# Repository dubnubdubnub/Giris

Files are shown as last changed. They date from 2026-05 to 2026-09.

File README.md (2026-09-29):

# Giris

An open source 32 key/half (64 total) **analog TMR split ortholinear keyboard** & 6 key macropad/dev board (`hw/TMR2615F_osu_pad`). 
Layout is similar to Keeb.io Iris with an extra column. Uses TMR2615F, 4:8 TMUX1574RSVR mux, & AT32F405. Link is UART over type-c cable.

There are 3 unique modes of operation: 
- standalone
- half A --> half B --> computer
- computer A <-- half A <--> half B --> computer B
    - Giris doubles as a KVM, you can control which computer you're typing on with a programmable macro
    - Relevant power circuitry to prevent backfeeding (GROUNDS ARE STILL BONDED!!!)

Done by Human:
- `hw/` — KiCad schematics and layout. `TMR2615F_osu_pad` is the 6-key development board the
  firmware is brought up on; `giris` is the full-size split.
- `mech/` — plates and frames.

Done by LLM + Human:
- `fw/` — firmware, written from scratch in C on the Artery BSP with TinyUSB. 8 kHz USB HS polling,
  8 kHz inter-half link. Host tools and a WebHID configurator live in `fw/tools/`.

## Schematics and photos

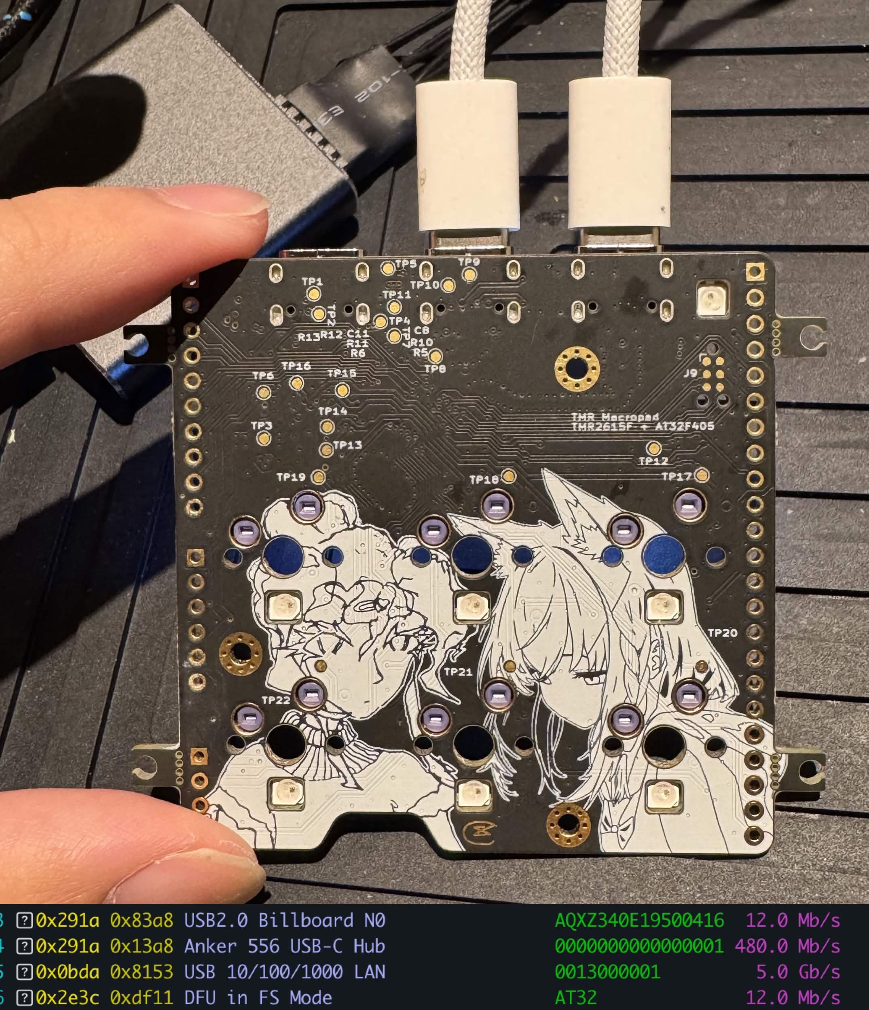
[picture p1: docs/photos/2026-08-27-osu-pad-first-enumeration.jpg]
First-revision osu!pad dev board enumerating over USB


PDFs:

- **osu pad dev board** (built and running, pictured above):
  [schematic](hw/TMR2615F_osu_pad/output/TMR2615F_osu_pad.pdf) ·
  [PCB layers](hw/TMR2615F_osu_pad/output/TMR2615F_osu_pad-layers.pdf)
- **Giris split** (in layout): [schematic](hw/giris/output/giris.pdf)
- **More photos and video** of built boards: [`docs/photos/`](docs/photos/)

The schematic PDFs draw the per-key sheet once and list each key's designators at the end;
regenerate them with `hw/tools/sch_pdf.py`.

## Setup

This repo uses git submodules for its shared footprint/3D-model library (`hw/library`) and `hw/marbastlib`. **The 3D bodies will not appear in KiCad's 3D viewer unless the submodules are checked out**; `.step` files live in `hw/library/packages3d/`.

Clone with submodules:

```bash
git clone --recurse-submodules https://github.com/dubnubdubnub/Giris.git
```

If you already cloned without `--recurse-submodules`, initialize them after the fact:

```bash
git submodule update --init --recursive
```

> Note: `hw/marbastlib` may print an error while recursing into a nested `.history` submodule. That is harmless — it is upstream and holds no 3D models the boards need.

## 3D models

Footprint 3D bodies resolve from three locations:

- `${KICAD10_3DMODEL_DIR}/…` — the standard models shipped with KiCad.
- `${KIPRJMOD}/../library/packages3d/…` — this repo's `hw/library` submodule (must be checked out; see Setup).

When adding new 3D models to a board, reference them with one of the path variables above rather than a bare relative path (e.g. `../../packages3d/…`), so they resolve regardless of where the repo is cloned.

## Licence

Giris uses two licences:

| What | Licence | File |
|---|---|---|
| Firmware, host tools, web configurator, docs | **Apache-2.0** | [`LICENSE`](LICENSE) |
| Hardware — schematics, PCB, magnet models (`hw/`) | **CERN-OHL-P v2** | [`hw/LICENSE`](hw/LICENSE) |

Both are permissive: use it, change it, build it, sell it, no obligation to
publish your changes. Apache-2.0 additionally carries an explicit patent grant.
CERN-OHL-P is the hardware equivalent — software licences are written about
copying source, not about manufacturing a board.

New source files should carry an SPDX header:

```c
/* SPDX-License-Identifier: Apache-2.0
 * Copyright 2026 Isaac Chiu
 */
```

### Third-party code

[`THIRD_PARTY.md`](THIRD_PARTY.md) is the full inventory; [`NOTICE`](NOTICE)
carries the attributions that must accompany a distributed **binary**.

The short version: TinyUSB (MIT) and the ArteryTek BSP are fetched at build time
by `fw/tools/fetch-deps.sh` and are not in this repository, though both are linked
into firmware binaries. Three Artery-derived files *are* committed — the startup
file, the linker script and `at32f402_405_conf.h` — and keep Artery's notice
rather than Giris'. Note that Artery ships two licence statements that disagree;
`THIRD_PARTY.md` explains which one to rely on.

### Why the firmware is not GPL

Giris is written from scratch. libhmk, minipad, DeskHop and the VIA app are
GPL-3.0; QMK, vial-qmk and Keychron's fork are GPL-2.0. All were read as
references and **no source file was ever pasted out of any of them**. That is a
deliberate, ongoing constraint, not an accident — copying so much as a descriptor
struct would make this firmware copyleft.

This matters most for the USB XUSB (Xbox controller) interface, where both
reference implementations — libhmk and Keychron's QMK fork — are copyleft. Write
it from Microsoft's own specification instead:

> **[MS-XUSBI]** — *Xbox Universal Serial Bus Protocol (XUSB) Interface Extension*
> <https://learn.microsoft.com/en-us/openspecs/windows_protocols/ms-xusbi/c79474e7-3968-43d1-8d2f-175d47bef43e>

It gives the class triple and the 20-byte report normatively, and its Open
Specifications notice explicitly permits copying the documentation in order to
build implementations of it. [`THIRD_PARTY.md`](THIRD_PARTY.md) records the
limits of that permission — notably that no patent grant is established.

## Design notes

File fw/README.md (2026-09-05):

# Giris firmware

Bare-metal C for the **AT32F405RBT7-7** on `hw/TMR2615F_osu_pad` — the 6-key analog dev pad that
prototypes the 64-key split (32 keys per half).

Architecture, decisions and the bring-up plan live in
[`../hw/TMR2615F_osu_pad/firmware_architecture.md`](../hw/TMR2615F_osu_pad/firmware_architecture.md).
This README is just how to build and flash.

## Setup

```bash
brew install --cask gcc-arm-embedded   # or the Arm GNU Toolchain installer
brew install cmake ninja dfu-util
./tools/fetch-deps.sh                  # Artery BSP + TinyUSB into vendor/
```

`vendor/` is gitignored. Pinning ~500 MB of upstream firmware libraries into this repo (or into
`.gitmodules`, alongside the KiCad libraries) is a decision to make deliberately — `tools/fetch-deps.sh`
has the one-liners if you want them as submodules.

## Build

```bash
cmake -S . -B build -G Ninja -DCMAKE_TOOLCHAIN_FILE=cmake/arm-none-eabi.cmake -DCMAKE_BUILD_TYPE=Debug
cmake --build build
```

Produces `build/giris.{elf,bin,hex}` and a `giris.map`. The link step prints the memory budget, which is
worth watching as the firmware grows:

```
FLASH:  3868 B / 128 KB   2.95%
RAM:    1600 B /  70 KB   2.23%
```

`compile_commands.json` is exported for clangd.

## Flash

```bash
cmake --build build --target flash      # or: ./tools/flash.sh build/giris.bin
```

**Entering DFU:** hold **SW1 (BOOT0)** and tap **SW2 (NRST)**, then release SW1. The board appears as
`2e3c:df11`, DfuSe 1.1a.

Two things about this that are easy to get wrong:

- The ROM bootloader is on **OTG_FS (PA11/PA12) only — connector J2, never J3.** J3 is the USB HS host
  port and cannot reach the factory bootloader at all.
- **J2 has no VBUS net**, so it cannot power the board. Power it separately while flashing.

`dfu-util` reports `Error during download get_status` on the leave request. That is a DfuSe quirk — the
device resets before answering. `File downloaded successfully` on the line above is the one that matters.

The device advertises its own memory layout, which is how the flash geometry here was confirmed:

```
alt 0   @Internal Flash   /0x08000000/128*001Kg      128 x 1 KB sectors
alt 1   @Option byte      /0x1FFFF800/01*512g
```

Note this is the **xB** part: 1 KB sectors, 6.6 ms typical / 8 ms max erase. The 2 KB / 13.2–16 ms
figures in Artery's tables are the 256 KB xC part. (Artery's own `AT32F405xB_FLASH.ld` declares 256 KB
of flash — a BSP bug. `ld/at32f405rbt7.ld` is that file with the length corrected to 128 KB.)

## What the firmware does today

- clocks to **216 MHz** from the 12 MHz crystal (PLL MS=1, NS=72, FP /4; PLLU /18 for OTG_FS),
- runs the **ADC/mux scan engine at 8 kHz** — ADC1 converts PA3/PA2/PA1/PA0 on every TMR2 TRGO,
  DMA1_CH1 lands them in a circular 8-slot ring, and the half/full-transfer interrupts flip the
  TMUX1574 SEL line so bank A and bank B interleave,
- enumerates on **J3 as a USB high-speed raw-HID device** and streams the readings to the browser
  viewer,
- drives the SK6812 chain as a status indicator.

There are **two HID interfaces**: the vendor raw-HID one the viewer speaks (usage page `0xFF60`), and
a boot-protocol keyboard. They are separate interfaces on purpose — macOS evaluates Input Monitoring
per `IOHIDDevice`, which means per USB interface, so putting keyboard usages on the vendor interface
would make the viewer demand permission to open it. Keyboard output is gated off at boot; see
`CMD_KEYS`.

### The viewer

```bash
./tools/viewer/serve.sh          # http://localhost:8000, Chrome or Edge
```

WebHID needs a secure context and `http://localhost` qualifies, so there is no TLS and no build step.
Live traces for all six keys, per-key readouts in counts and Gauss, CSV recording, a raw-slot debug
table, and a burst capture that dumps a few thousand samples for an in-page FFT.

That FFT is the point of the whole exercise: **a flat spectrum means white noise and narrowing the
analog filter is worth it; a −1/2 amplitude slope means 1/f and narrowing buys ~5 % for a 103 µs
transport delay.** That measurement decides the filter respin.

### Two boards at once

Every board now takes its USB serial from the 96-bit factory UID at `0x1FFFF7E8`, so two halves
running one image are separable everywhere — `capture.py`, `link.py`, `dfu.py` and the viewer all take
`--serial` with any unique substring. The last four hex characters are a good handle.

```bash
tools/.venv/bin/python tools/link.py --list
E75C30400080160505875C13  Giris osu pad (telemetry)
E85C30400080160505875113  Giris osu pad (telemetry)
```

Those two are adjacent dice off one wafer and differ in only two of twelve bytes, which is why
`uid_tag()` — the 16-bit condensation used to break ties in link arbitration — is FNV-1a over the whole
UID rather than a truncation. They come out 0x436A and 0xF885.

In DFU every AT32 reports the serial `AT32`, so there the bus path is the only discriminator:

```bash
tools/.venv/bin/python tools/dfu.py --serial 5C13     # prints the DFU path it lands on
./tools/flash.sh build/giris.bin 2-1.3
```

### The J1 link

```bash
tools/.venv/bin/python tools/link.py --probe --serial 5C13   # one board, J1 empty
tools/.venv/bin/python tools/link.py --continuity            # two boards: is there a wire?
tools/.venv/bin/python tools/link.py --peer                  # two boards: the real sweep
tools/.venv/bin/python tools/link.py --soak --baud 13500000
```

**Measured, two boards, straight-through USB-C on J1:**

| Config | Result |
|---|---|
| Half duplex, open drain, one wire on D− — *the discovery bus* | clean at 115200 and **500 kbaud**; framing errors at 1 Mbaud |
| Full duplex, push-pull, TRPSWAP on one half — *the run phase* | clean at every rung to **13.5 Mbaud**, the USART's ceiling, both directions |
| Soak at 9 and 12 Mbaud, **3 m cable** | 409,600 bytes each, **0 corrupt, 0 missing, 0 noise flags** |
| Same at 13.5 Mbaud, 3 m | NERR on **61/100 runs**; clean at 1.5 m |
| Sustained rate, DMA both ends | **98.8–99.6 % of line rate** — the wire is saturated, not the CPU |

At 13.5 Mbaud a 72-byte frame (32 keys × u16 + header + mech bitmap + CRC-16) takes **54 µs, 43 % of a
125 µs microframe**, and the link is full duplex so the return path is free. 13.5 Mbaud is also the
hard ceiling: RM 12.6.1 requires `DIV ≥ 16` with fixed 16× oversampling, and APB2 is already at the
part's 216 MHz maximum. **Run at 12 Mbaud**: it is clean over a 3 m cable with the receiver's noise
flag never firing, where 13.5 raises NERR on most runs. See the architecture doc for the full table
and for why the link should negotiate its own rate.

500 kbaud is exactly where the architecture doc predicted the open-drain bus
would die: two 10 k pull-ups into ~70 pF. Discovery at 115200 has 4× margin.

Three traps are baked into the tooling because each one costs an afternoon:

- **`--probe` before anything else.** The datasheet gives PC6 = USART6_TX and
  PC7 = USART6_RX but not the MUX index. The probe sweeps all sixteen while the
  USART shifts `0x00` and watches the pad; only **MUX8** modulates.
- **`--continuity` before believing any link failure.** It is a DC test with no
  USART involved: one board holds a pad low, the other reads its own. A
  charge-only USB-C cable carries VBUS and GND but neither D+ nor D−, and from
  the firmware side that is indistinguishable from a dead peripheral. The first
  cable tried here was one of those, and it also fed 5 V into J1 — which is what
  made one board's `/LM_ST` read high and sent us hunting a phantom.
- **Receive by DMA, never by polling.** A CPU loop gets preempted by the 16 kHz
  ADC/mux ISR for longer than a byte time above ~8 Mbaud. The USART overruns,
  the lost byte shifts the expected value for every byte after it, and reading
  `DT` silently clears `ROERR` — so you see *almost every byte arriving and
  almost every byte wrong, with no error flag*, which looks precisely like a bad
  cable. It is not. `DMA1_CHANNEL1` is the ADC ring, so the link takes channel 2.

**This silicon does not echo its own half-duplex transmission.** RM 12.2 says TX
and SW_RX are interconnected, but with `SLBEN=1 TEN=1 REN=1` a lone board never
raises RDBF, at any baud, open-drain or push-pull, with no error flag — and
turning the listener's transmitter off does not change it. Testing the receive
path needs a peer on J1 or a jumper from **TP1** (D+) to **TP2** (D−).

### Is it really 8 kHz?

```bash
tools/.venv/bin/python tools/ratetest.py --seconds 10
```

Measured, not asserted. The streaming path emits exactly **one frame per report** — `adc_read_frame()`
always returns the newest complete frame, so the pack loop breaks on its second iteration — which means
the device wants to send at the full scan rate and achieves `min(poll rate, scan rate)`. Counting
reports therefore counts polls. `bInterval = 1` is 1 ms at full speed and 125 µs at high speed, so
~8000/s proves both at once.

Two independent numbers come out and should agree: the host-observed count, which Python can bottleneck,
and a device-side figure computed from the firmware's own `tx_dropped` counter, which cannot.

| Host | scan | host-observed | device-side | dropped | seq gaps |
|---|---|---|---|---|---|
| macOS 26, 30 s | 8000 frames/s | 7902 reports/s | 8000 reports/s | 0 | 0 |
| **Windows 11 24H2, 5 s** | 8001 frames/s | **7883 reports/s** | 8001 reports/s | 0 | 0 |

Windows matters here because it honours the `bInterval` exponent only for intervals 1–5, and it is the
platform where 8 kHz claims usually fall apart. It does not: within 0.2 % of macOS.

**Caveat:** a 30 s Windows run ended in an `OSError: read error` from hidapi and the hub then dropped
off entirely, taking its other devices with it. That looks like cable movement rather than a device
fault, but a long Windows soak has not yet completed cleanly and should be repeated.

### Checking the USB side

```bash
python3 tools/usb-check.py
```

Reads descriptors only — no interface claim — so it works while the browser has the device open. It
should report high speed (480 Mb/s) and `bInterval=1` on the interrupt endpoints.

### Reflashing without touching the board

The viewer's **DFU** button issues `CMD_BOOTLOADER`, which jumps to the ROM bootloader at
`0x1FFFA400`. The device disappears from J3 and reappears as `2e3c:df11` on J2, ready for
`tools/flash.sh`. BOOT0 + NRST remains the recovery path if the firmware ever stops answering — the
ROM bootloader runs before user code, so you cannot brick the board this way.

## Deliberately not done yet

`main()` **never drives PC13**. That pin is the AP22653 enable and it sources 5 V out of J1 into whatever
is plugged in there. It is Hi-Z at reset with a 10 k pulldown holding the switch off, and it must stay
that way until link arbitration has run and the VBUS_B divider (mux S4A → ADC1_IN0) reads cold.

Likewise the SK6812 driver is a blocking bit-bang with interrupts disabled — fine while nothing else
runs, and exactly what the architecture doc says not to ship. The real one is SPI + DMA at 3.375 MHz.

## Layout

```
cmake/arm-none-eabi.cmake   toolchain file
ld/at32f405rbt7.ld          BSP linker script with the flash length corrected
include/board.h             pin map, read out of the exported netlist (not the schematic source)
include/at32f402_405_conf.h BSP module switches
src/clock.c                 12 MHz -> 216 MHz
src/sk6812.c                bit-banged LED chain (bring-up only)
src/main.c                  first light
tools/fetch-deps.sh         vendor deps
tools/flash.sh              dfu-util wrapper
```

`include/board.h` is the single source of truth for pin assignments and carries the traps inline — the
inverted UART net names, the PB12/OTGHS_ID overlap, the hotswap sockets sitting on the analog nodes, and
the sensor's inverted output.

## Licences

- **TinyUSB** — MIT.
- **Artery BSP** — *not* a free licence. Artery grants use, copying and distribution "for the purpose of
  design and development in conjunction with Artery microcontrollers". Fine for this product; it does not
  travel to a non-Artery target, and it is not BSD-3.
- Everything under `src/`, `include/`, `ld/`, `cmake/`, `tools/` is ours **except three
  Artery-derived files**: `src/startup_at32f402_405.s`, `ld/at32f405rbt7.ld` (modified) and
  `include/at32f402_405_conf.h`. Those keep Artery's notice and are not covered by Giris'
  Apache-2.0 grant. See `THIRD_PARTY.md`.

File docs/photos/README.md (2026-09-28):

# Photos

Photos and video of built boards, reposted from X.

| File | What it shows | Post |
| --- | --- | --- |
| `2026-08-27-osu-pad-first-enumeration.jpg` | First-revision osu!pad (6-key TMR2615F macropad and AT32F405 dev board, `hw/TMR2615F_osu_pad/`) enumerating over USB | https://x.com/dubnubdubnubdub/status/2092836680588038394 |
| `2026-09-28-osu-pad-kvm-mode.mp4` | Two osu!pads running the Giris firmware in KVM mode | https://x.com/dubnubdubnubdub/status/2104688463064994127 |

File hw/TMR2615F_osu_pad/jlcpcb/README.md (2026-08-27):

# TMR2615F_osu_pad — jlcpcb fabrication package

Generated 2026-08-04 04:05 from `TMR2615F_osu_pad.kicad_pcb` by `.claude/skills/fab-export`.

## Board

| | |
|---|---|
| Size | 70.1000 mm × 60.0000 mm |
| Copper layers | 4 (F.Cu, In1.Cu, In2.Cu, B.Cu) |
| Finished thickness | 1.6167 mm |
| Min track width | 0.1600 mm |
| Min clearance | 0.1600 mm |
| Min drill | 0.3000 mm |
| Through vias | 636 |
| NPTH pads | 27 |

## Stackup as designed

Non-default materials — confirm the fab's equivalent when ordering.

```
F.SilkS | Top Silk Screen
F.Paste | Top Solder Paste
F.Mask | Top Solder Mask | 0.01524 mm | JLCPCB Soldermask | Er 3.8
F.Cu | copper | 0.035 mm
dielectric 1 | prepreg | 0.2104 mm | Nan Ya Plastics NP-155F 7628 | Er 4.4
In1.Cu | copper | 0.0152 mm
dielectric 2 | core | 1.065 mm | Nan Ya Plastics NP-155F Core | Er 4.43
In2.Cu | copper | 0.0152 mm
dielectric 3 | prepreg | 0.2104 mm | Nan Ya Plastics NP-155F 7628 | Er 4.4
B.Cu | copper | 0.035 mm
B.Mask | Bottom Solder Mask | 0.01524 mm | JLCPCB Soldermask | Er 3.8
B.Paste | Bottom Solder Paste
B.SilkS | Bottom Silk Screen
```

## Files

- `TMR2615F_osu_pad-gerbers-jlcpcb.zip` — 13 files, flat zip: gerbers (KiCad `.gbr` extensions), Excellon drill (PTH/NPTH separate, mm, absolute origin), `.gbrjob`
- `BOM-TMR2615F_osu_pad-jlcpcb.csv` — 34 line items
- `CPL-TMR2615F_osu_pad-jlcpcb.csv` — 151 placements (128 top / 23 bottom)
- `gerbers/` — the same plot files, unzipped, for review
- `docs/` — drill maps, board statistics, DRC report

## Ordering

Upload the gerber zip under *PCB*, then enable *PCB Assembly* and upload
`BOM-*.csv` and `CPL-*.csv` on the parts step.
Rows with an empty `LCSC Part #` must be matched by hand in their part selector
(or marked Do Not Place).

## Checks

- DRC: **96 error-severity violations, 0 unconnected** — see `docs/drc.rpt`
- 1/34 BOM lines have no LCSC part number: TP1
- 1/34 BOM lines have **neither MPN nor LCSC** — these cannot be sourced automatically
- Dropped 1 empty layer(s) — nothing to plot, and empty gerbers make some portals report a parse failure: TMR2615F_osu_pad-B_Paste.gbr
- DNP parts excluded from both BOM and CPL
- Schematic part-number fields detected: lcsc→LCSC, mpn→MPN, mfr→Manufacturer

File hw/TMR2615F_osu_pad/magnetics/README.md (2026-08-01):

# Magnetics: switch magnet → TMR2615F sensor model

Answers "which MX magnetic switches work with this board, and what does the sensor
see?" for the osu!pad's per-key TMR2615F-AAC-1.500-500 sensors.

## Files

| File | What |
|---|---|
| `magfield.py` | Field of an axially magnetized cylinder magnet at an off-axis point. Equivalent-solenoid model (stack of current loops), complete elliptic integrals via AGM. Pure stdlib. |
| `test_magfield.py` | Checks: K/E against known values, loop closed forms, on-axis analytic face field, dipole far-field limit, symmetry. `python3 test_magfield.py` |
| `fit_switches.py` | Per-switch magnet models (measured or spec-fitted), predicts the in-plane field at this board's sensor across travel. `python3 fit_switches.py` |
| `measure_switch.py` | Measures magnet size / rest height off vendor engineering-drawing PDFs (600 dpi render + dark-pixel edge voting, calibrated against two dimensioned widths per view). Used on `hw/refs/switches/*.pdf`. |
| `tmr-magnet-model.html` | Interactive visualization of the same model (self-contained JS port — no build, open in a browser). Sliders for press depth, sensor offset, PCB thickness, magnet size, sensitivity code. |

## Geometry (measured from `TMR2615F_osu_pad.kicad_pcb`)

- Sensor is **3.09 mm radially offset** from the switch center, rotated so its in-plane
  (Bx) sensing axis points through the switch axis → it reads the stem magnet's
  **radial** field component.
- Single-side assembly on F; the switch inserts from the B side, so the magnet sees the
  die **through the 1.62 mm board** (+0.3 mm die depth in the pads-down DFN3L).
- Switch footprint is standard MX 5-pin + Kailh hotswap; the socket is unused by
  (pinless) magnetic switches — board is hybrid mech/magnetic capable.

## Key results (SEN 1.500 → output rails at ±300 Gs)

All twelve modeled switch families land in range with margin: ~34–48 Gs at rest,
~165–286 Gs at bottom-out vs the ±300 Gs rail — **full-travel linearity for every
switch**, with Gateron KS-20 (905 Gs class) closest to the rail.

Five Gateron switches were *measured* off their dimensioned engineering drawings
(`hw/refs/switches/`): Jade, Jade Pro, Jade Ultra, Jade Attraction, and the MCHOSE
Apollo all use the **same Ø2.77 × 3.41 mm magnet cylinder**; families differ only in
carry height (rest height 4.13–4.73 mm above PCB) and magnet grade (implied Br
1.16–1.66 T). The published initial flux (quoted at 0.3 mm pressed, on their 1.2 mm
reference PCB) validates the model within 2–14 % as a held-out check. Every modern
Gateron drawing states **"Magnet N-pole is facing down"** — community lore calling
Gateron "S-down" is wrong per primary source. The bipolar TMR2615F handles either
polarity, but don't mix polarities on one board unless firmware calibrates sign per
key.

Unpublished specs: Wooting Lekker (community-assumed = KS-20), Raesha/DrunkDeer and
Geon Raptor HE (no flux figures anywhere), TTC/Kailh/Akko (flux specs but no
drawings). Kailh Flame/Mistral quote "2000 Gs trigger flux" at an unknown measurement
point — excluded from the calibrated set; bench-test first. MonsGeek sells no switches
of its own (all Akko-made).

## Caveats

- Vendors publish flux at the sensor, not magnet dimensions. Magnet size is a **fit**
  to the published rest/bottom-out pairs (converges on Ø3.0–3.6 × 1.6–2.2 mm,
  N52-class); treat absolute field values as ±25 %. The published rest flux is held
  out as a validation and reported as "rest chk".
- Verify on hardware before bulk-ordering sensors: log the ADC across full travel with
  one real switch — one bench trace collapses all magnet-fit uncertainty.
- Research provenance (manufacturer specs, polarity clusters, compatibility notes) is
  summarized in the July 2026 conversation that produced this; primary sources are
  Gateron/TTC/Kailh/MonsGeek product pages and the MonsGeek magnetic-switch
  knowledge base.

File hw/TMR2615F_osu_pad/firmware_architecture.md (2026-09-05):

# Giris firmware — architecture options

Scope: the firmware platform for the `TMR2615F_osu_pad` (6-key analog dev pad) **and** the full-size
split keyboard it is a prototype for — **64 keys total, 32 per half**. One image, either half, three topologies, 8 kHz USB HS, browser
configurator, Wooting-class analog feature set.

Written 2026-08-24 after a survey of every open keyboard firmware that could plausibly serve, plus
primary-source verification against the AT32F402/405 datasheet + reference manual, the USB 2.0 spec,
TinyUSB, Chromium, EDK2, and the source of libhmk / QMK / ZMK / RMK / minipad / DeskHop / VIA / Vial.
Claims below are marked where they are still **unverified** and need a bench measurement.

---

## 0. TL;DR

**Nothing off the shelf fits.** The requirement set — 8 kHz *and* analog *and* split *and* dual-host
*and* a good web UI — has no intersection in existing firmware. The closest single project (libhmk)
matches the silicon and the analog feature set exactly but has no split, no RGB, is GPL-3.0, and its
superloop cannot hold a 125 µs deadline once a link and RGB are added.

**Recommended stack:**

| Layer | Choice |
|---|---|
| Base | Clean-room C on Artery BSP (see §11) + TinyUSB (MIT), CMake. libhmk as a read-only reference. |
| Scheduling | SOF-phased interrupt pipeline, strict NVIC priority hierarchy, lock-free SPSC handoff |
| Split cut point | **Semi-smart peripheral**: each half owns analog→key-position; centre owns keymap/layers/HID |
| Link | Fixed-size full-duplex isochronous frames on **USART6 at 12 Mbaud**, DMA both ways, hardware CRC-32; 115200 open-drain only for discovery |
| Roles | **Symmetric peers + transferable input-owner token.** Master/slave survives only as a *power* concept |
| Config transport | Own protocol over a dedicated raw-HID interface (vendor usage page), WebHID |
| Configurator | Own web app, self-describing device (gzipped keyboard metadata in flash) |
| Storage | RAM-mirrored blob + word write log now; banked image + hot-field journal for the full-size board |

The single decision that shapes everything else is #4 (peer model). The hardest constraints are the
flash erase stall (6.6–8 ms on this 128 KB part) and the **44–74 µs** the 64-key pipeline costs out of
every 125 µs microframe.

**Two board respins are worth doing**: the per-key filter to **2.2 kΩ + 47 nF** (kills 12.9 LSB of
inter-key crosstalk), and the sensor's **offset trim code** to reclaim the half of the ADC range the
unipolar field never uses. The 120 Ω link resistors should be left alone.

---

## 1. Prior art: what exists and why none of it is the answer

| Project | Platform | 8 kHz | Analog | Split | Web UI | License | Why not |
|---|---|---|---|---|---|---|---|
| **libhmk** | AT32F405 + STM32F446, TinyUSB, superloop | ✅ HS | ✅ full | ❌ | ✅ own (hmkconf, Svelte) | GPL-3.0 | Right silicon, right features, **no split**, no RGB, superloop won't hold the deadline, `uint8` distance |
| **QMK** | everything, ChibiOS | ❌ ~1 kHz | ❌ upstream | ✅ (≤1 kHz) | via VIA/Vial | GPL-2.0 | Analog is a [feature request](https://github.com/qmk/qmk_firmware/issues/25875), split transport is request/response with 20 ms timeouts |
| **Vial (vial-qmk)** | QMK fork | ❌ | ❌ | ✅ | ✅ vial.rocks | GPL-2.0 | Best *protocol* ideas; the web app is a PyQt5 app compiled to WASM (~17.8 MB first load) |
| **ZMK** | Zephyr, BLE-first | ❌ | ❌ | ✅ (event, 15–20 ms) | ✅ Studio (protobuf) | MIT | Wrong performance class entirely; endpoint-switching code is worth reading |
| **RMK** | Rust + Embassy | ❌ | ❌ | ✅ (central + ≤8 peripherals) | Vial | Apache/MIT | Serial split is COBS/postcard at 115200 **with no CRC**; no AT32 HAL |
| **minipad** | RP2040 + Arduino | ❌ | ✅ | ❌ | CLI/desktop | GPL-3.0 | osu-pad scope; good calibration ideas (runtime-fitted LUT, 0.01 mm units) |
| **macrolev** | STM32F411 / ESP32-S3 | ❌ | ✅ | (rev2 WIP) | ✅ basic | — | Work in progress, no keymap config |
| **Keychron QMK fork** | QMK + HE | ❌ | ✅ | ❌ | Launcher (VIA-derived) | GPL-2.0 | Vendor fork, not a platform |
| **DeskHop** | 2×RP2040, UART | n/a | n/a | n/a (KVM) | — | GPL-3.0 | **The dual-host prior art.** Not a keyboard, but solves the state hygiene |

Notable absence: **there is no open wired split link running above ~1 kHz.** QMK's `split_common` is
four sequential turnarounds per transaction with a 20 ms timeout at 230400–460800 baud
(`serial_protocol.c:113-158`). Whatever the link protocol ends up being, it is new work.

What is worth stealing, concretely:

- **libhmk** — the AT32 clock/USB bring-up sequence, the descriptor layer (boot-compatible NKRO), the
  self-describing metadata pipeline, the DKS/null-bind data model, the forward-migration table.
- **QMK/ZMK/RMK** — all three ship **key positions, not keycodes**, over the split link. Copy that.
- **DeskHop** — per-host lock LEDs (`structs.h:97`), `release_all_keys()` on the half losing the host
  plus a message so the peer does the same (`handlers.c:385-394`), and merging local + remote state
  into one report before every send (`keyboard.c:203-216`).
- **ZMK** — clear reports on the *outgoing* endpoint *before* flipping the active one
  (`endpoints.c:482-489`), and keep `hid_indicators[]` per endpoint.
- **minipad** — 0.01 mm units and a runtime-fitted magnet-model LUT rather than a fixed curve.

---

## 2. Hard constraints (verified, and they kill options)

> Numbers below are for the **64-key full-size board: 32 keys per half**. Everything was re-derived
> after an adversarial audit; where the audit refuted an earlier figure the correction is marked.

### Silicon
- Cortex-M4F @ 216 MHz = **~27,000 cycles per 125 µs microframe**, but **six flash wait states with
  prefetch and no confirmed I-cache**. A branch-dense per-key pipeline running from flash costs
  **130–250 cycles/key**, not the 150 I first assumed. At 64 keys that is **44–74 µs, i.e. 35–59 % of a
  microframe for the key pipeline alone**; with USB, link, CRC, HID assembly and RGB prep, plan on
  **50–70 %**. Relocate the hot loop to SRAM (102 KB, zero wait state).
- **Flash program/erase halts the CPU** — and the board's part is better than I first wrote.
  **AT32F405xB (the RBT7 on this board) has 1 KB sectors, 6.6 ms typ / 8 ms max erase.** The 2 KB /
  13.2 ms / 16 ms figures are the **xC (256 KB)** part. So moving to RCT7 for flash space would
  *double* the worst-case single-erase stall. TPROG is 40 µs typ / 42 max per word either way.
  The RM attributes the erase stall to *flash read access*, so a RAM-resident writer with RAM-resident
  vectors *may* survive it — **unverified, first thing to measure.** Not a disconnect: the DWC2 core
  NAKs IN tokens in hardware without the CPU.
- Flash operations **require HICK enabled**.
- One 12-bit ADC. **TS = 1.5 cycles is legal here** — the 3.3 nF (47 nF after the respin) reservoir is
  the source the ADC sees, not the series resistor, so RAIN is only the mux R_ON, far under the 100 Ω
  that DS Table 51 demands at fADC = 28 MHz. That gives 14 cycles = **518.5 ns per conversion**, so a
  **32-key scan is 17.3 µs = 57.8 kHz** — 41 % faster than the 41 kHz I first quoted, and right at the
  2 MSPS ceiling. Four to seven complete scans fit in a microframe.
- Hardware ADC oversampler (ratio 2–256, shift 0–8) and 2×7 DMA channels with full DMAMUX — a
  **zero-CPU mux scan** (timer → DMA writes SEL → DMA reads ADC) is possible.

### USB
- 8 kHz ⇒ **HS enumeration + `bInterval = 1`** (USB 2.0 §9.6.6). FS cannot do better than 1 kHz, so the
  **J3** host port must be OTG_HS; the 12 MHz crystal is load-bearing (HS PHY reference is **HEXT only**,
  ±50 ppm).
- DWC2 spec 4.00a, internal DMA, EP0 + 7 IN + 7 OUT, 4096-byte FIFO SPRAM. A libhmk-shaped composite
  uses ~136 of 1024 words — endpoint *count* is the tighter budget.
- TinyUSB supports the part as `OPT_MCU_AT32F402_405`, including the AT32 quirk forcing `TRDT = 9`.
- **Windows applies 2^(Interval−1) only for Interval 1–5**, clamping 6–255 to 32 microframes (4 ms), so
  a "1 kHz mode" cannot be expressed by bInterval alone — rate-limit in firmware.
- bInterval is a *request* (§5.7.4); 8 kHz is never guaranteed by the descriptor alone.
- **TinyUSB's device stack is a single global instance** — J3 (HS) and J2 (FS) cannot both be device
  without patching it.

### The link (J1)
- **Open-drain half-duplex is a ≤500 kbaud transport** with 10 kΩ pull-ups into ~70 pF (~560 ns rise).
  Fine for the 115200 discovery phase; 2 Mbaud open-drain is impossible. Push-pull for steady state.
- `USART_BAUDR` is an **integer divider, DIV ≥ 16, fixed 16× oversampling** — no fractional divider, no
  OVER8. On APB1 (108 MHz) **UART7 tops out at 6.75 Mbaud**. **USART6 is on the same PC6/PC7 pins at
  MUX8 and is clocked from APB2 = 216 MHz**, giving an exact ladder of **13.5 (DIV 16), 12, 9, 8 and
  6 Mbaud**. The "6 Mbaud wall" is a UART7 fact, not a link fact. **Use USART6.**
- **Do not lower the 120 Ω series resistors.** *(This refutes my earlier recommendation.)* 120 Ω supports
  roughly 19 Mbaud over 1 m and 11 Mbaud over 2 m — both above USART6's 13.5 Mbaud ceiling — and going
  **below 47 Ω breaks an absolute maximum rating**. Nothing in any link plan needs them changed.
- A straight-through USB-C cable connects like pin to like pin, so **exactly one half must set
  `CTRL2.TRPSWAP`** — which is what role negotiation is for.

### Analog front end — corrected against the netlist and the audit
- As built: sensor VOUT → **30 pF** (C33…) → **5.1 kΩ** (R29–R34) → node with **3.3 nF** (C34…C54) →
  mux. τ = 16.8 µs, f_c = 9.46 kHz. *(Not the 330 Ω + 47 nF in my earlier notes — that was a plan.)*
- **The sensor's own 30 kHz pole cascades with the RC**, so the noise bandwidth is
  (π/2)·f_c·30k/(f_c+30k) = **12.0 kHz**, not 16.1.
- **Charge sharing is the biggest analog defect on the board as built.** The sampling node is
  C_ADC 13 pF max + parasitic ~7 pF + TMUX1574 C_ON 7.5–12 pF ≈ **28 pF**, giving a charge-share
  fraction of **28/(3300+28) = 0.84 %**. Against a worst neighbour-key step (KS-20 full travel =
  1.233 V) that is **12.9 LSB of signal-dependent inter-key crosstalk** — key A's reading moves with
  key B's position, so calibration cannot remove it. Sub-LSB needs **C_res ≥ 27 nF (Jade) / 43 nF
  (KS-20) ⇒ 47 nF is the right value.**
- **But the series resistor cannot go down to 330 Ω.** Worst-case node-to-rail transient current is
  0.95·VDD/R, and the TMR2615's **VOUT drive is a 1.5 mA absolute maximum** — 330 Ω gives 9.5 mA (6.3×
  over), 1 kΩ gives 3.1 mA. **R ≥ 2.09 kΩ; use 2.2 kΩ.**
- ⇒ **Respin target: 2.2 kΩ + 47 nF.** τ = 103 µs, f_c = 1.54 kHz. Sub-LSB crosstalk, drive-limit safe,
  and lower noise. The lag objection does not apply the way I stated it: at a rapid-trigger reversal the
  velocity is zero, so the one-pole error is **τ²·a, not τ·v** — at τ = 103 µs and a = 1000 m/s² that is
  **10.7 µm**. The τ·v term is transport *delay* (≈0.83 of a microframe), not position error.
- **Resolution, corrected.** Travel is per-family, not a flat 4 mm (Jade 3.5, KS-20 4.1, Apollo 3.1…).
  True *local* slope ratio rest→bottom-out is **6.89:1** for the Jade, spread **5.58:1 (Apollo) to
  9.13:1 (KS-20 — the worst, not the best)**. So the radial-offset geometry beats libhmk's 8.6:1 by
  ~20 %, not 3×. One ADC count is **11.15 µm at rest and 1.62 µm at bottom-out** (Jade).
- **Noise floor**: σ ≈ **2.9–3.4 LSB** ⇒ **25–36 µm rms at rest, ~5–9 µm at bottom-out.** The sensor,
  not the ADC, is the floor. Honest rapid-trigger floor is depth-dependent: with 4× ADC oversampling and
  a mild EMA, roughly **0.050 mm at 0.3 mm depth, 0.035 mm at 1 mm, 0.020 mm at 2 mm, 0.011 mm at 3 mm.**
- ⚠️ **Whether narrowing the filter helps at all is unmeasured.** If the sensor noise is white, dropping
  f_c from 9.5 kHz to 3 kHz buys ~1.8×. If it is 1/f-dominated — which MTJ/TMR elements usually are, and
  MDT publishes no corner — the same change buys **5 %**, and the lag is paid for nothing. **Measure the
  noise spectrum before committing to the filter respin.**
- **The F variant's output is inverted**: 95 % VDD → 5 % VDD as B goes −B → +B, so **counts decrease with
  travel** (subject to magnet polarity). Fix the sign convention in firmware and calibrate sign per key.
- Never reorder the ADC scan sequence at runtime — the residual charge-sharing error is deterministic
  only if the order is fixed.

## 3. Decision 1 — base platform

| Option | Verdict |
|---|---|
| **A. Artery BSP (see §11) + TinyUSB (MIT) + own CMake, libhmk as reference** | ✅ **Recommended.** Only combination that leaves licensing free. Board code is genuinely small (libhmk's is ~260 lines). 1–2 weeks to first enumerating 8 kHz HID with ADC scanning. |
| B. Fork libhmk and add split + RGB | 3–5 days to a blinking fork, then weeks unpicking single-half assumptions — and you ship GPL-3.0. Good source of validated constants (clock recipe, DWC2 quirks). |
| C. Artery's own `usbd` stack | Keep the clone for bisecting a TinyUSB bug. Not a base. |
| D. QMK / vial-qmk | 1 kHz, no analog, GPL-2.0. Not viable. |
| E. Rust + Embassy | No AT32 HAL exists. 3–5 months vs 2–3. The value is concentrated in the pure algorithm layer, which you can get by unit-testing C on the host instead. |

**Firmware update path** — the ROM DFU is on **OTGFS PA11/PA12 only** (Artery UM0001 §4.12 Table 12),
so the J3 host port cannot reach the factory bootloader. Netlist-verified: **J2** carries OTGFS1_D+/D− (PA11/PA12)
and **has no VBUS net at all**, so the ROM DFU is electrically reachable on J2 — but `GCCFG.VBUSIG` resets to 0
(VBUS not ignored), so whether the ROM bootloader enumerates there is **unverified and must be bench tested early.** It decides whether a custom HS bootloader is polish or the only unbrick path.
Primary user-facing update should be **app-resident self-flashing over the existing WebHID channel**
(A/B images) — it is the only mechanism that works driver-free on all three OSes over J3 *and* can
update the far half through the link. Note Chrome's WebUSB cannot claim the DfuSe interface on Windows
without WinUSB binding, so "browser WebDFU" is not the free win it looks like.

## 4. Decision 2 — scheduling model

| Option | Verdict |
|---|---|
| A. Bare superloop, DMA-only ISRs (libhmk) | Right for the first two weeks of bring-up. Wrong the moment a link or RGB exists. |
| **B. SOF-phased interrupt pipeline, strict NVIC hierarchy, lock-free SPSC** | ✅ **Recommended.** The only option where "meets 125 µs" is falsifiable with a number. |
| C. Superloop + hard-real-time ISR island | Reasonable staging point; the jitter tail is what fails on a 100-key split with RGB. |
| D. FreeRTOS / ChibiOS / Zephyr | Defensible under B for background work. Zephyr means porting the SoC — months. |
| E. Rust + Embassy | See above. |

The mechanism that makes B work: **OTG_HS routes its SOF pulse to TMR2's internal trigger IS3 in
hardware** (`TMR2_RMP[11:10]`, RM §21.2 "the SOF pulse can be output to device pins and timer 2"), and
with APB1 = /2 the TMR2 counter runs at 216 MHz (4.63 ns/tick). That gives a hardware microframe phase
reference for free: schedule the scan at a fixed offset from SOF, and *prove* the deadline by latching
`TMR2->CVAL` at report-arm time and keeping a max watermark.

> ⚠️ The obvious alternative — `PA4` / `OTGHS1_SOF` as a physical output pin — **is not available on
> this board: PA4 is already ADC1_IN4.** Use the internal TMR2 route. (This corrects the first pass of
> this analysis.)

Concrete priority hierarchy: USB > link UART (DMA + IDLE) > ADC DMA > LED DMA > housekeeping. All of
libhmk's ISRs sit at NVIC priority 0 — flat, no preemption — with 4 priority bits available. Also note
libhmk applies its EMA once per *superloop iteration* rather than per ADC sample, making its filter
time constant load-dependent, and `hid_send_reports()` busy-spins on `tud_hid_n_ready()` inside the
scan path. Do neither.

## 5. Decision 3 — where to cut the split pipeline

At **32 keys per half** the link budget is no longer the thing that decides this. UART 8N1 = 10 bit-times
per byte; payload + 4 B of header/seq/CRC-16:

| Frame | Bytes | @4 Mbaud | @6 Mbaud | @9 Mbaud (USART6) | @13.5 Mbaud |
|---|---|---|---|---|---|
| key positions only | 8 | 20 µs | 13 µs | 8.9 µs | 5.9 µs |
| **centi-mm distance ×32 (9-bit, 400 steps)** | **40** | **100 µs** | **67 µs** | **44 µs** | **30 µs** |
| 8-bit distance ×32 | 36 | 90 µs | 60 µs | 40 µs | 27 µs |
| 12-bit packed ×32 | 52 | ~~130 µs~~ **does not fit** | 87 µs | 58 µs | 39 µs |

Two corrections to my first pass. **12-bit at 4 Mbaud does not fit a 125 µs microframe** and also
destroys the inter-frame IDLE gap the framing depends on — strike it. And **8-bit is not "wrong"**: its
15.6 µm quantisation is 4.5 µm rms, which against a 25–36 µm sensor floor adds 1–8 % in quadrature. The
right unit is **centi-mm — 400 steps, 9 bits** — because it matches the pipeline's own unit, not because
8-bit is too coarse.

| Option | Verdict |
|---|---|
| QMK-shaped polled request/response | Only as the **115200 discovery/arbitration phase**, where collision-detect-by-readback is what you want. Never steady state. |
| **Semi-smart: peripheral does analog→key-position, centre does keymap/layers/HID** <br>✅ **still recommended** | 20 µs frames at 4 Mbaud, 8.9 µs at 9 Mbaud. Leaves each half functional alone, keeps layer resolution correct, leaves the microframe free for the 44–74 µs key pipeline. |
| Dumb peripheral: stream raw analog to one processing domain <br>❌ **refuted on audit** | It does **not** delete cross-half coordination. It *adds* ~1.9 KB of dual-homed config — in dual-host either half can become the owner, so both need the full config anyway — of which **~640 B is live-mutating calibration** needing a new sync path. And it is arithmetically inconsistent with the CPU budget: a 100 µs frame leaves ~25 µs of the microframe, against a 44–74 µs key pipeline. |
| Fully smart: peripheral emits keycodes | ❌ Needs the centre's layer state fed back a frame late; emits the wrong keycode across a layer change. The reason QMK, ZMK and RMK all ship positions. |
| Event-driven, COBS (RMK/ZMK shape) | ❌ Wrong premise — an 8 kHz board exists for bounded, constant latency. |

**Frame shape:** fixed-size, word-aligned, full-duplex isochronous, into a circular DMA ring, delimited by
the USART **IDLE-line interrupt** — periodic traffic with a guaranteed inter-frame gap resynchronises for
free, so no COBS and no length-prefix search. CRC-16/CCITT on the hardware CRC unit costs ~111 ns for
24 bytes. Sequence numbers for drop detection; release all keys on link loss.

**Run USART6 at 9 Mbaud.** It is an exact integer divisor of APB2, the 120 Ω resistors already support
it, and it puts even a full centi-mm stream at 36 % duty — which keeps the dumb-peripheral option open as
a later experiment without a board change.

## 6. Decision 4 — roles, and the built-in KVM

**Replace master/slave with symmetric peers plus a transferable "input-owner" token.** Master/slave
survives *only* as a power concept — who drives PC13/AP22653 into J1 — which `/LM_ST` already tells
you. Conflating power-master with input-owner is what makes topology (b) unimplementable.

Each half owns a full, permanently-enumerated USB HID stack. The token says which of the (up to two)
attached hosts currently receives the merged keyboard. Transfer it with a two-phase commit.

Topologies to auto-detect:

| # | Topology | Detection | Behaviour |
|---|---|---|---|
| a | PC → half A → half B | A has J3 VBUS, B is link-powered (`/LM_ST`) | A sources 5 V, A owns input, B tunnels positions |
| a′ | Same, roles reversed | symmetric | identical code path |
| b | PC1 → A ↔ B ← PC2 | link hail answered *and* both have own VBUS | **nobody sources 5 V**; token chooses the active host; the non-owner half tunnels |
| c | Half alone | hail times out, no peer | standalone keyboard |
| d | Link lost mid-session | frame timeout | release all keys, fall back to Independent mode |

State hygiene on a token switch — all of these are per-host, not global:
- Zero report on the **outgoing** host *before* flipping the owner variable (ZMK's ordering).
- A zero keyboard report is not enough: clear consumer, system control, mouse buttons, and zero every
  gamepad axis/trigger.
- **Change-suppression caches are per-host.** libhmk's file-scope statics in `hid_send_hid_report()`
  would suppress a needed report after a switch.
- Lock LEDs (caps/num) diverge per host — keep `leds_desired[NUM_HOSTS]`.
- Boot protocol vs report protocol, and SET_IDLE, differ per host. PC1 may be in a BIOS at 6KRO while
  PC2 is at NKRO. Keep abstract key state and *render* per host.
- **Suspend is not disconnect.** On disconnect the host drops your keys; on suspend it freezes its view
  of them. Re-send state on resume.

Latency: the remote hand costs roughly **+125 µs mean / +185 µs worst** versus the local hand — on top
of a ~125 µs local path, against a ~1 ms end-to-end budget. Irrelevant. The genuinely new problem in
topology (b) is that the two halves are clocked by **two independent SOF domains** (USB 2.0 Table 7-13:
125 µs ±500 ppm each, so up to ~1000 ppm relative drift), so the non-owner cannot phase-align its link
TX to the owner's microframe. Fix with a link sync beacon and a slow phase servo, or accept one extra
frame of jitter.

Electrical consequence to accept, not fix: in topology (b) the split cable **hard-bonds the two hosts'
USB grounds**, because J1 must carry GND for the 5 V pass-through in topology (a). DeskHop puts an
ISO7721 across its link precisely to avoid this — but its own FAQ says running without the isolator is
fine. Document it; don't pretend firmware can solve it.

**Measured, 2026-08-28, two hosts on the same 120 V outlet, before bonding:**

| Quantity | Value |
|---|---|
| Open-circuit potential between the two USB grounds | **50 V AC at 60 Hz** |
| Current available between them | **70 µA AC** |
| Implied source impedance | 50 V / 70 µA = **714 kΩ**, i.e. 3.7 nF at 60 Hz |

That impedance is the giveaway: it is a **Y-capacitor divider**, not a fault. A Class II supply with no
earth reference floats its DC ground at roughly half the line voltage through the EMI caps bridging
mains to the secondary, and 2.2–4.7 nF is exactly what those parts are. **The voltage reading alone is
meaningless** — a 10 MΩ meter across a 714 kΩ source reads most of the open-circuit value while almost
no current is available. Measure the current.

Consequences, all negligible:

- IEC 62368-1 allows **250 µA** touch current for this class. 70 µA is 28 % of it.
- Steady state, 70 µA down J1's ground through ~1 Ω is a **70 µV** offset between the two halves'
  ground references — against a UART threshold margin measured in volts.
- The hot-plug transient carries Q = CV̂ ≈ **262 nC**, E = ½CV̂² ≈ **9.3 µJ**, four orders of magnitude
  below the SRV05-4A's 8 kV contact rating, and USB-C mates GND before signal regardless.

**Verdict: no isolator.** One caveat for the product rather than the bench — this was 120 V mains. At
**230 V** the float voltage roughly doubles and so does the leakage, to ~140 µA. Still inside the limit,
with half the margin. Measure it in a 230 V region before shipping dual-host as a headline feature.

Independently confirmed that this is not a functional problem either: the enumeration failure on the
second host was the BOS descriptor (§15), and unplugging J1 changed nothing.

Also unaddressed so far and worth budgeting: in topology (a) **one 500 mA host port powers both halves**
— two MCUs, two HS PHYs, and up to 14 SK6812s.

## 7. Decision 5 — config transport and the web UI

| Option | Verdict |
|---|---|
| A1. VIA protocol, upstreamed to usevia.app | ❌ **Blocked, permanently.** Official support requires your source merged into `qmk/qmk_firmware` *and* a `keymaps/via` keymap merged into `the-via/qmk_userspace_via`. Not possible for from-scratch firmware. |
| A2. VIA protocol + Design-tab side-load | Users must enable a hidden tab, dismiss a warning, and side-load JSON that lives only in that browser profile's IndexedDB. Secondary interface at best. |
| A3. Fork the-via/app (GPL-3.0), self-host | 3–5 weeks + a permanent merge tax. |
| B. Vial protocol | Genuinely implementable: discovery is the magic string `vial:f64c2b3c` in the USB serial descriptor, **no registry at all**, definition ships LZMA-compressed in firmware. But Vial has **no vocabulary for actuation / rapid trigger / DKS**, and vial.rocks is a PyQt5 app compiled to WASM (~17.8 MB first load). |
| **C. Own raw-HID protocol + own web app** | ✅ **Recommended.** hmkconf is a working ~11.5k-LOC proof this is weeks, not months. |
| D. C plus a thin VIA-compatible shim on a second interface | Cheap insurance *after* C ships. Never let it shape the primary data model. |
| E. ZMK Studio model (CDC-ACM + protobuf over Web Serial) | Only if Firefox support is a hard requirement (Web Serial shipped in Firefox 151; WebHID never will). |

**VIA's ceiling, concretely:** 22 command IDs, 32-byte reports on usage page 0xFF60 / usage 0x61,
buffer ops chunked at 28 bytes, and custom menus that can express exactly **eight scalar control types
carrying 1–2 bytes each**, in a nested list with no key-position awareness. Per-key actuation for 69
keys means 69×N enumerated sliders in a flat list, and a DKS entry (4 keycodes + 4 action bitmaps +
bottom-out point = 9 bytes) **does not fit in a single control at all.** This is why every HE vendor
ships their own configurator.

**The best idea to steal from libhmk:** the device describes itself. The whole `keyboard.json` is
gzipped at build time into a `KEYBOARD_METADATA[]` array in flash (~950 B for a 69-key board) and
streamed to the browser 59 bytes at a time, where native `DecompressionStream("gzip")` inflates it.
One web app then serves every board with zero per-board code — including the 6-key pad and the
full-size split.

WebHID mechanics that will bite:
- **Chromium-only** (no Firefox, no Safari). Same limitation as usevia.app and Vial; state it up front.
- **`HIDDevice` has no serial number** — add a `GET_SERIAL` command (the 96-bit UID is at `0x1FFFF7E8`)
  and key app state on VID-PID-serial.
- **Do not put config reports on the keyboard's collection.** Chromium's `IsAlwaysProtected()` strips
  all reports on usage page 0x07 and recurses into child collections. Separate USB interface, vendor
  usage page, own non-zero report ID.
- macOS additionally requires **Input Monitoring** permission to open a HID device containing keyboard
  usages — another reason for the separate interface.
- The blocklist is **remotely extensible** via a Finch param, so "check `hid_blocklist.cc`" is
  necessary but not sufficient when picking a VID/PID.
- Two physically separate halves need **two user gestures** (two `requestDevice` calls). Design the UI
  for that; don't copy hmkconf's `collections[0]`-only filter or vial-web's `devices.length != 1` bail.

**Effort, honestly:** firmware protocol + metadata pipeline 1–2 weeks; web app functional-but-plain
3–4 weeks; genuine usevia.app-class polish (layout renderer, drag/shift-click key selection, keycode
picker, per-key analog editor, DKS editor, macro editor, live depth view, RGB editor, profiles,
split/KVM UI, dark mode) **6–10 weeks** for one experienced dev. Also note hmkconf's live analog view
runs at ~13–14 Hz on a 69-key board because of a `setInterval(…, 10)` dispatch plus a serialized
queue — the transport is not the limit, its client is. Do better with a firmware-pushed telemetry
report.

## 8. Analog pipeline and feature semantics

Baseline: **clean-room centi-mm pipeline with per-key piecewise-linear calibration** (2–3 weeks, plus
1–2 weeks of capture/fit tooling). libhmk's `uint8` distance in [0,255] is the thing not to inherit —
its own fitted LUT has an 8.6:1 sensitivity ratio between bottom-out and rest.

- **Filter**: EMA per *ADC sample*, not per loop iteration. Add ISR-decimated hardware oversampling
  (3–5 days) — measure the noise floor first; if σ < 0.5 LSB keep N small.
- **Calibration**: two-sided continuous (minipad's approach) with an inward deadzone, plus a saved
  bottom-out threshold. Guard the failure mode of a key held at power-on.
- **Curve**: runtime-fitted LUT from a magnet model, or per-key PWL. PWL is the only shape flexible
  enough for a sensor whose transfer function you have not characterised yet.
- **Hysteresis**: libhmk has *none* in non-RT mode (`is_pressed = distance >= actuation_point`) and its
  non-continuous RT reset point equals the actuation point. Add real hysteresis.
- **Velocity**: compute it (free, and the configurator wants it for the live graph) but ship prediction
  **off** by default and never make RT thresholds velocity-adaptive by default.

Feature semantics to pin down in the data model up front: RT down/up sensitivity + continuous mode +
reset point + direction-reversal behaviour; actuation point + hysteresis; Rappy Snappy (deeper wins,
both only when both bottomed out); SOCD modes (last-wins / first-wins / neutral / absolute — plus the
tournament-legality flag); DKS (4 keycodes × 4 action phases + bottom-out point); mod-tap with QMK's
vocabulary (tapping term, permissive hold, hold-on-other-key-press); toggle key; layers + one-shot;
macros; analog curves (deadzone, response curve, per-key axis assignment).

**Split config model — the decision that determines whether the project works:** two-plane processing
with symmetric mirrored config. The peripheral owns calibration, actuation point and rapid trigger for
*its* keys, so per-key analog config must be mirrored to the half that owns the key, with an
epoch/generation scheme. Nail down the epoch format and handedness storage **before** writing split
code. In topology (b) this gains a genuine distributed-systems problem with no prior art: two browsers,
one per host, can both write config. Define a single owner for shared state and a rejoin policy —
last-writer-wins on a counter will silently discard one PC's edits.

Config writes to the *peer* traverse the same 4 Mbaud link that carries the 8 kHz key path. Budget it:
rate-limit config writes, and never let a config write or a live-telemetry stream perturb the key path.

## 9. Storage and the flash stall

1. **Now (dev pad):** RAM-mirrored blob + word write log (libhmk's scheme, hardened with A/B banking
   and a deferral scheduler). Correct for anything under ~8 KB.
2. **Full-size split:** banked image + hot-field journal, no full RAM mirror. libhmk's wear-levelling
   amplification is 8 flash bytes per 6 payload bytes, dropping to 5 payload bytes once
   `WL_VIRTUAL_SIZE` passes 8192 — which a 100-key, 4-profile config will.

Split config into a **hot** part (actuation points, RT thresholds — read every microframe) and a
**cold** part (keymaps, macros, RGB). Never write the hot part while the keyboard is live: stage into a
RAM shadow and apply atomically by pointer swap. Bound every critical section to a countable number of
instructions.

## 10. Bring-up plan (and the measurements that gate each step)

**Phase 0 — silicon truth (do this before writing architecture code).**
1. Does the ROM DFU enumerate on **J2** (FS port, no VBUS net)? (Decides the whole recovery story.)
2. `GPIO toggle + scope` around `flash_sector_erase()`: real stall duration, and **does a RAM-resident
   erase routine with RAM-resident vectors keep ISRs alive?**
3. Does `GINTSTS.SOF` fire every 125 µs in HS device mode? Count SOFs against a free-running timer for
   one second. Confirm the TMR2 IS3 SOF trigger route works.
4. Real mux settling on this board: drive SEL, sample the same channel at 1 µs intervals, find where it
   stops moving. (Expect ~350 ns, not libhmk's 20 µs.)
5. ADC swing in raw counts over the full 4 mm for the TMR2615F as mounted, and the noise floor σ —
   with the SK6812 chain idle *and* at full white.
6. VDD droop and rest-value shift when the AP22653 is enabled (PC13). TMR sensors are ratiometric, so
   this moves every key.
7. Link eye at 4 and 6 Mbaud at the longest cable you intend to ship, with the 120 Ω resistors (R3/R7) in place.

**Phase 1 — superloop bring-up (libhmk shape).** USB HS enumerating at bInterval=1, mux/ADC producing
sane numbers, one key registering, raw-HID config interface answering a version command.

**Phase 2 — the real skeleton.** SOF-phased pipeline, NVIC hierarchy, deadline watermark instrumentation,
role vtable + runtime role dispatch, host-side unit tests of the pure algorithm layer driven by recorded
ADC traces.

**Phase 3 — link.** Discovery/arbitration at 115200 open-drain, then push-pull isochronous frames.
Then the peer/token model and topology detection.

**Phase 4 — configurator.** Metadata pipeline first (self-describing device), then the app.

## 11. Licensing

**Resolved 2026-09-04: Apache-2.0 for software, CERN-OHL-P v2 for `hw/`.** See `LICENSE`,
`hw/LICENSE`, `NOTICE` and `THIRD_PARTY.md`; the notes below are what led there.

- **TinyUSB** MIT → clean, attribution on binaries only.
- **Artery BSP** — *corrected.* This section previously read "BSD-3-Clause", which is what the BSP's
  `LICENSE` file says. The notice at the head of every BSP **source file** says something narrower:
  use, copy and distribute *"in conjunction with Artery microcontrollers"*. A field-of-use limit is
  not an open-source grant, so the BSP is not straightforwardly BSD-3-Clause. No practical
  consequence for Giris — the firmware only runs on an AT32F405 — but it is a real discrepancy, it
  travels with the three committed Artery-derived files, and a compliance scan will flag it.
- **libhmk, minipad, DeskHop, VIA app** are GPL-3.0; **QMK/vial-qmk** GPL-2.0. Reading them and copying
  an *approach* is fine; copying code makes the firmware GPL. Keep libhmk as a reference checkout that
  no source file is ever pasted out of, and note in the repo that this was deliberate.
- Self-hosting any GPL web app carries the source-offer obligation, and WebHID requires a secure
  context (HTTPS or localhost) either way.

## 11b. Netlist-verified board map (exported with the kicad-curved CLI, 2026-08-24)

Superseding earlier notes, which had several refs and values wrong:

| Item | Truth |
|---|---|
| **J3** | Main **USB HS host port** — OTGHS1_D+/D−, VBUS_HOST |
| **J2** | **USB FS port, data only** — OTGFS1_D+/D− (PA11/PA12), **no VBUS net**. The only path to the ROM DFU |
| **J1** | Inter-board link — VBUS_B; D+ (A6/B6) → R7 120 Ω → `/UART7_TX` = **PC7**; D− (A7/B7) → R3 120 Ω → `/UART7_RX` = **PC6**; 10 kΩ pull-ups R1/R2; SRV05-4A (U1) clamps |
| J5 / J7 | Break out **9 spare ADC channels** (IN4–IN15) — useful for prototyping a 32-key scan on the dev pad |
| J6 / J8 / J9 | I²C / SPI / IO expansion, and SWD + USART1 debug |
| Sensors | **U13, U15, U17, U19, U21, U23** — TMR2615F-AAC-1.500-500 |
| Mux | **U11** TMUX1574RSVR; SEL = PB2; outputs → ADC1_IN0..IN3 |
| LEDs | **U12** (sacrificial, on the 1N4148-dropped rail) then U14…U24 on +5 V — 7 total |
| **Analog rail** | +5 V → **U4 TPS7A4700** (ultra-low-noise LDO) → **+3.3VA** → all six sensors **and** the mux; and → **L1** (GZ1608D601TF, 600 Ω bead) → MCU **VDDA**. Digital +3.3 V is a separate XC6206 (U8). |
| **Per-key filter** | sensor VOUT → **30 pF** (C33…) to GND → **5.1 kΩ** (R29–R34) → node → **3.3 nF** (C34…C54) → mux input. τ = 16.8 µs, f_c = 9.46 kHz |
| VBUS_B sense | 10 k/10 k divider (R4/R9) = ÷2 → 5.1 kΩ (R8) + 3.3 nF (C10) → mux S4A → ADC1_IN0 |
| Hotswap sockets | SW3–SW8 pin 2 sits **directly on the analog node**, pin 1 on GND — a mechanical switch shorts the sensor node to ground (hybrid mech/magnetic). Firmware must read a hard 0 as "mechanical key closed", and the socket adds C and leakage to the analog node. |

Because the sensors and the ADC reference are the same node at DC (both `+3.3VA`, separated only by
L1's sub-ohm DCR), **ratiometric cancellation genuinely works here** — supply variation cancels between
the sensor's output and the ADC's full scale. Only >MHz disturbances see the bead, and the TPS7A4700
makes those negligible. This is a good design; do not "fix" it.

## 12. Board-level findings and respin candidates

Netlist- and audit-verified. Items 1–4 are firmware-visible facts; 5–10 are respin candidates.

| # | Finding | Action |
|---|---|---|
| 1 | **PC6 is the native TX and PC7 the native RX**; the schematic names them the other way (`/UART7_TX` on PC7). | Harmless — one half must `TRPSWAP` anyway — but the "default" half is the swapped one. Relabel. |
| 2 | **USART6 shares PC6/PC7 and is APB2-clocked** — exact ladder 13.5 / 12 / 9 / 8 / 6 Mbaud vs UART7's 6.75 ceiling. | Use USART6. Target **9 Mbaud**. No board change. |
| 3 | **PA4 is ADC1_IN4 here**, so the `OTGHS1_SOF` pin output is unavailable. | Use the internal **TMR2 IS3** SOF route instead. |
| 4 | **The F-variant sensor output is inverted** (95 % → 5 % VDD as B increases). | Counts *decrease* with travel. Calibrate sign per key; never mix magnet polarities. |
| 5 | **Charge sharing: 28 pF sampling node into 3.3 nF = 0.84 % ⇒ up to 12.9 LSB of inter-key crosstalk.** | **Respin the filter to 2.2 kΩ + 47 nF.** 47 nF is the minimum for sub-LSB; 2.2 kΩ is the minimum that respects the sensor's 1.5 mA VOUT absolute max. |
| 6 | **Do not lower the 120 Ω link resistors.** They support ~19 Mbaud over 1 m; below 47 Ω breaks an absolute maximum rating. | Leave them. *(Refutes my earlier suggestion.)* |
| 7 | **The 10 kΩ link pull-ups straddle the USB connect threshold.** With RPD 14.25–15.75 kΩ and 10 kΩ ±1 % from 3.3 V ±2 %, J1 sits at **1.893–2.067 V** against VIH = 2.0 V — the governing threshold for connect detection is VIH, not VIHZ. | **Raise the pull-ups** (or gate them) so plugging J1 into a PC cannot read as an attach. |
| 8 | **Half the converter range is structurally unused.** The field is unipolar (34 → ~190 Gs, never crossing zero) but the part is ordered at the mid-rail **500 mV/V** offset, so only 300 Gs of the ±300 Gs window is reachable. Sensitivity **and** offset are custom-orderable (0.500–7.000 mV/V/Gs, 300–700 mV/V). | Order the offset at the end the field moves *away* from. At **700 mV/V** the usable window becomes 650/SEN Gs = **433 Gs**. Trading that headroom for sensitivity: `1.800-700` → +20 % counts/Gs; restricted to the measured Gateron families (≤191 Gs), `2.500-700` → **+67 % counts/Gs**. Free — it is a trim code, not a different part. |
| 9 | **KS-20 / Lekker is at 95 % of the rail already** (286 of 300 Gs) and is a ±25 % *fitted* family — at +25 % it hard-clips before bottom-out. KS-37B and Everglide clip at +14 %. | Either bench-measure those families before promising support, or fix it with the offset change in #8. |
| 10 | **LED budget**: the SK6812MINI-E fitted is the **12 mA/channel** part → 36.65 mA/LED full white → **1.173 A for 32 LEDs**, not the 1.9 A I first quoted. The AP22653's *guaranteed* limit is **ILIM_min = 1.044 A** (1.16 A is typical). | The slave half **trips at ~78 % white**. Firmware brightness cap is mandatory, and in the daisy-chain topology a single 500 mA host port feeds both halves. |
| 11 | **`OTGHS1_R` needs an external 12 kΩ ±1 %**; the **12 MHz crystal needs ±50 ppm total**. | Verify both — classic bring-up failures. |
| 12 | **Hotswap sockets SW3–SW8 pin 2 sit on the analog node**, pin 1 on GND. | A mechanical switch shorts the sensor node. Firmware must read a hard rail as "mechanical key closed", and the socket adds C and leakage. |
| 13 | **SK6812 over SPI + DMA works** (3.375 MHz, 4-bit symbols → 296/889/593/593 ns, in spec). | Divider granularity does not force timer-PWM+DMA. SPI frees a timer. |

### Balancing the filter against the mechanical-switch short

The hotswap sockets (SW3–SW8 pin 2) sit on the same filtered node the mux reads, with pin 1 on GND — so
a mechanical switch shorts the sensor node. That looks like it fights the filter choice. It does not:

**The mech short *is* the constraint that sets R.** The "worst-case node-to-rail current" that forces
R ≥ 2.09 kΩ is exactly a mechanical switch holding the node at ground while the sensor drives into it —
and it is a *continuous* condition while the key is held, not a transient. The TMR2615's **1.5 mA V_OUT
drive is an absolute maximum with no short-circuit protection** (datasheet §4). So 2.2 kΩ is not a
compromise against the hybrid-switch feature; it is the number that feature demands. At 2.2 kΩ the
sensor sources 1.42 mA worst case.

**What genuinely conflicts is the capacitor discharging through the socket contact.** 47 nF at 1.65 V
into a ~0.1 Ω contact is a ~5 A ring (64 nJ) — a hot-switch event on a signal-level gold contact, every
single keypress. Small energy, but peak current is what pits contacts.

**Fix: one 100 Ω resistor in series with each hotswap socket.** It sits in series with R_main for the DC
path, so sensor current is unchanged, but it limits the discharge ~300×. It must stay small enough that
a closed mechanical key reads *below* the deepest legitimate analog value — which is **0.234 V**, set by
KS-20/Lekker, the highest-flux family:

| R_sock | mech level at rest | margin below deepest analog | discharge peak |
|---|---|---|---|
| 0 (as built) | 0.000 V | 0.234 V | **~5 A** |
| **100 Ω** ✅ | 0.075 V | 0.159 V | 15.8 mA |
| 150 Ω | 0.113 V | 0.122 V | 10.2 mA |
| 300 Ω | 0.225 V | 0.009 V — **ambiguous** | 4.7 mA |

Release latency is a non-issue: from the 0.075 V held level the node recrosses 0.30 V in **16 µs** and
0.60 V in 42 µs — a fraction of a microframe.

Rejected alternatives: moving the socket to the sensor-side node (only 30 pF there) shorts V_OUT
directly and blows the 1.5 mA absolute max; shrinking C to cut discharge energy brings back 12.9 LSB of
crosstalk; a large R_sock puts the mech level inside the analog band.

**Firmware**: a closed mechanical key now reads a fixed low level rather than 0, so put the
"mechanical key closed" threshold between the mech level and the analog floor (~0.15 V ≈ 186 counts) —
and express it as a fraction of the key's rest value, since everything here is ratiometric.

**Cost**: one extra 0402 per key — 64 on the full board.

### Why the big C is right regardless

At fixed τ, R and C trade directly against each other, and the crosstalk follows C:

| R_main | C | τ | crosstalk (1.23 V neighbour step) |
|---|---|---|---|
| 2.2 kΩ | 47 nF | 103 µs | **0.9 LSB** |
| 3.3 kΩ | 33 nF | 109 µs | 1.3 LSB |
| 4.7 kΩ | 22 nF | 103 µs | 1.9 LSB |

Big C also lowers the noise bandwidth, and its only cost is transport *delay* — a fixed latency, not a
position error, and ~10 % of a 1 ms end-to-end budget. R can be raised freely on noise grounds (Johnson
noise at 3.3 kΩ over 12 kHz is 0.8 µV against 1.5 mV of sensor noise), so the choice is driven entirely
by crosstalk and by the sensor's drive limit. **2.2 kΩ + 47 nF + 100 Ω socket resistor** satisfies all
three. If the noise spectrum comes back white, 2.2 kΩ + 100 nF (τ = 220 µs, 0.4 LSB) is defensible.

### The measurement that gates the filter respin

**Is the sensor's noise white or 1/f?** Under white, narrowing f_c from 9.46 kHz to 1.54 kHz cuts σ by
~2.5×. Under 1/f — which MTJ elements usually are, and MDT publishes no corner — it buys ~5 %, and you
pay 103 µs of transport delay for nothing. Capture the noise spectrum on one channel with the key at
rest before ordering the respin. Note also that "BW = 5 kHz" in the noise spec is itself ambiguous
(brickwall vs single pole swings the extrapolation by 20 %), and 10 mV_PP is a **max**, not a typ.

---

## 13. Link bring-up: what the two boards actually measured (2026-08-28)

Both dev pads, self-powered from their own J3, nothing in J1. Run with
`tools/link.py --probe`, which sweeps the GPIO MUX electrically instead of trusting a table.

| Claim | Status |
|---|---|
| PC6 = USART6_TX, PC7 = USART6_RX | **Confirmed** — DS_AT32F405_402 V2.03, pins 37/38 of the 64-pin part |
| USART6 is at **MUX8** on those pins | **Confirmed by measurement.** The datasheet does not print MUX indices. Sweeping 0–15 while shifting `0x00`, only MUX8 modulated the pad (78–80 % low against the 90 % the framing implies). MUX15 reads a flat 100 % — an undriven pad, not a signal |
| R1/R2 10k pull-ups and R3/R7 120 Ω fitted and working | **Confirmed** — both pads pull to 0 open-drain and return high through the fitted resistor, on both boards |
| **The link runs** | **Confirmed.** Two boards, straight-through USB-C on J1. Full-duplex push-pull with TRPSWAP on one half is clean at every rung of the ladder to **13.5 Mbaud** — the USART's hard ceiling — in both directions. Soaks of 163,840 bytes at 9 Mbaud and at 13.5 Mbaud: zero corrupt, zero missing, no error flag. The 9 Mbaud target has comfortable margin and 13.5 is available if it is ever wanted |
| Open-drain half-duplex is a ≤500 kbaud transport | **Confirmed, to the rung.** Clean at 115200 and at 500 kbaud; at 1 Mbaud every byte arrives and 1020 of 1024 are corrupt with FERR set. That is the 10k-into-70pF rise, and it is a genuine *wire* limit, not a CPU one. Discovery at 115200 has 4x margin |
| Single-wire half-duplex echoes to its own receiver | **REFUTED.** RM 12.2 says "TX and SW_RX are interconnected inside the USART", but with `SLBEN=1 TEN=1 REN=1` neither board raised RDBF on 256 bytes, at 115200 *and* 9 Mbaud, open-drain *and* push-pull, with `STS = 0x00C0` (TDC+TDBE, no error). The transmitter is provably running. **Consequence: the discovery bus cannot be validated by one board — it needs a peer or a TP1–TP2 jumper.** The discovery design itself is unaffected |
| `/LM_ST` (PB12) means "we are link-powered" | **Confirmed, and the earlier alarm was a bad cable.** LM66100 ST is Hi-Z (so R5 pulls it high) while that ideal diode conducts, and pulled low while it blocks — so high really does mean "our +5 V is coming in through J1". The two boards disagreed because the first cable tried was carrying 5 V into J1, powering one of them through it. With a proper cable both read low, both PC13 read low, and nothing sources VBUS. The AP22653 fitted is the **active-high** enable variant (AP22652 is the active-low one), so R10's 10k pulldown does hold it off |
| ~~`/LM_ST` is driven, not floating~~ | **Over-claimed and withdrawn.** R5's 10k pull-up beats the MCU's ~40k internal pull-down, so a Hi-Z ST reads high under both internal pulls. Only the LOW result was ever conclusive |
| ~~Old note~~ | **Open, and now suspicious.** Read with the internal pull-up and then the pull-down, the pin is genuinely *driven* on both boards — and the two boards disagree. In identical states (J3-powered, J1 empty) board `…5C13` drives it **high** and board `…5113` drives it **low**. U2 is an LM66100 ideal diode on VBUS_B; U7 is its twin on VBUS_HOST; the pair ORs into +5V. Until this is explained, **no power decision may key off PB12** |

### The identity problem, and why it came first

Two halves run one image. Before this, both enumerated as `1209:0001` serial `000000000001`, and in DFU
every AT32 reports the serial `AT32` — so no host tool could name a board, and no log line was
attributable. Fixed by taking the USB serial from the 96-bit UID at `0x1FFFF7E8` (Artery's device
electronic signature, the address their own USB middleware uses) and by adding it, plus a 16-bit
`uid_tag`, to `RSP_INFO`.

The two boards on the bench are adjacent dice: `E75C3040 00801605 05875C13` and
`E85C3040 00801605 05875113` differ in two of twelve bytes. A truncation would collide; FNV-1a over all
twelve gives 0x436A and 0xF885. That tag is the arbitration tie-break.

### Is 13.5 Mbaud enough for an 8 kHz split, and can it go higher?

**Higher is not available.** RM 12.6.1 is explicit: the receiver splits each bit into 16 oversample
steps, "so the data bit width should not be less than 16 PCLK periods, that is, the DIV value must be
greater than or equal to 16." No fractional divider, no OVER8. APB2 is already at the part's 216 MHz
ceiling, so **13.5 Mbaud is a hard wall on USART6**, not a tuning knob.

**Enough is not close.** Measured sustained rate with DMA on both ends (98.8–99.6 % of line rate, so
the wire really is saturated), against a 72-byte frame — 32 keys x u16 position, header, 32-bit mech
bitmap, CRC-16:

| Baud | Sustained | 72 B frame | Share of a 125 µs microframe |
|---|---|---|---|
| 8 Mbaud | 7.94 Mb/s | 90.7 µs | 72.5 % |
| 9 Mbaud | 8.93 Mb/s | 80.7 µs | 64.5 % |
| 12 Mbaud | 11.87 Mb/s | 60.7 µs | 48.5 % |
| **13.5 Mbaud** | **13.33 Mb/s** | **54.0 µs** | **43.2 %** |

The link is full duplex, so the return path — layer state, lock LEDs per host, the input-owner token,
RGB sync, config traffic — rides the other wire concurrently and costs the forward path nothing.

Packing positions to 12 bits (32 keys in 48 bytes) drops the frame to 56 B = 34 % at 13.5 Mbaud, if
that headroom is ever wanted. It is not needed at 32 keys per half.

#### Cable length: measured, 1.5 m and 3 m

409,600 bytes per rate, 100 runs of 4096 alternating direction, over a **3 m** USB-C cable — roughly
three times any split cable that would ship, chosen as a deliberate worst case.

| Baud | 3 m result |
|---|---|
| 9 Mbaud | 409,600 B, 0 corrupt, 0 missing, **0/100 runs raised NERR** |
| 12 Mbaud | 409,600 B, 0 corrupt, 0 missing, **0/100 runs raised NERR** |
| 13.5 Mbaud | **61/100 runs raised NERR**, one run desynced entirely and lost 4093 B |

At 1.5 m all three rungs including 13.5 Mbaud were clean.

**NERR is the leading indicator, and it is free.** The receiver oversamples 16x and majority-votes
samples 8/9/10 of each bit; NERR means those three disagreed. At 13.5 Mbaud over 3 m it fired on 61 %
of runs while **still recovering every byte correctly** — zero corruption. So the eye closes visibly
in the noise flag well before any data is lost. It is symmetric too: 27–39 of 50 on every combination
of direction and of which wire carries the traffic, so this is cable length, not a board or a net.

The a-priori estimate in §2 — 120 Ω supports ~19 Mbaud over 1 m and ~11 Mbaud over 2 m — turns out to
have been slightly conservative and essentially right.

The **open-drain discovery bus is unchanged between 1.5 m and 3 m**: clean at 115200 and 500 kbaud,
1020 of 1024 bytes corrupt with FERR at 1 Mbaud. That limit is the 10 kΩ pull-ups into the node
capacitance, not the cable, which is why length does not move it.

**Recommendation: run at 12 Mbaud, and negotiate it.** 12 is clean at three times the realistic cable
length with the leading-indicator flag never once firing, and it costs 48.5 % of a microframe against
64.5 % at 9. DIV = 18 also keeps one rung off the divider's DIV ≥ 16 floor, where the oversampler has
exactly one PCLK per step.

Then make it adaptive, because NERR makes that nearly free: after the 115200 handshake, bring the link
up at 12 Mbaud and watch NERR and the CRC-16 failure rate. If either rises, step down 9 → 8 → 6. The
link then self-tunes to whatever cable the user actually plugged in, and it downshifts *before* frames
start being lost rather than after.

If a future design genuinely needs more, the lever is not the baud rate:
- **J1's SBU1 (A8) and SBU2 (B8) are unconnected** on this board. Wiring them on the full-size respin
  gives two more conductors — enough for a real SPI, or better, a **hardware frame-sync strobe**, which
  would retire the software phase servo that topology (b)'s two independent SOF domains otherwise need.
- Push more feature computation into each half so the link carries events rather than positions. That
  is a ~10x payload cut, and the reason it was rejected is that SOCD, Rappy Snappy and Snappy Tappy are
  cross-key features whose two keys may land on opposite halves.

### Two traps that cost real time, recorded so they are not paid twice

**A charge-only USB-C cable is indistinguishable from a dead peripheral.** The first cable tried
carried VBUS and GND but neither D+ nor D−. Every link test failed identically with no error flag, and
it also fed 5 V into J1, which lit one board's `/LM_ST` and started a hunt for a phantom power fault.
`tools/link.py --continuity` now settles this in two seconds with no USART involved at all: one board
holds a link pad low open-drain, the other reads its own pad. **Run it before believing any link
failure.**

**Receive by DMA, never by polling.** A CPU loop reading RDBF gets preempted by the 16 kHz ADC/mux ISR
for longer than a byte time above roughly 8 Mbaud. The USART overruns, the lost byte shifts the
expected value for every byte after it, and reading `DT` clears `ROERR` on the way past — so the
symptom is *almost every byte arriving, almost every byte wrong, and no error flag*, which reads
exactly like a bad cable. With DMA the same hardware is clean to 13.5 Mbaud. `DMA1_CHANNEL1` is the ADC
ring; the link takes `DMA1_CHANNEL2` with `DMAMUX_DMAREQ_ID_USART6_RX`.

### Order of the remaining link work

1. ~~Connect J1↔J1 and prove the wire.~~ **Done.** Safe as built: firmware never drives PC13, so
   neither AP22653 sources 5 V and each board keeps its own J3 supply. Electrically this is topology (b).
2. ~~Half-duplex open-drain at 115200 on D−, both halves unswapped; full-duplex with TRPSWAP.~~ **Done,
   both directions, to 13.5 Mbaud.**
3. ~~UID-tag arbitration over the 115200 discovery bus.~~ **Done.** Two halves running one image find
   each other, assign complementary roles and step up to 12 Mbaud unaided:

   ```
   5C13: running  role=A (unswapped)  tag=0x436A  peer=0xF885  baud=12,000,000
   5113: running  role=B (TRPSWAP)    tag=0xF885  peer=0x436A  baud=12,000,000
   ```

   60 s at 12 Mbaud: 1198 ping/pong exchanges each, exactly the designed 20/s, **zero CRC errors, zero
   drops, zero re-switches.** The handshake costs a few CRC errors and at most one drop while the peer
   changes rate under it, then converges within a second and stays converged.
4. ~~Framing — fixed-size isochronous frames into a circular DMA ring.~~ **Done.** 48-byte frames, both
   directions, paced by each half's own 8 kHz ADC tick. See §7a.
5. **Next:** the peer/token model and topology detection. `SPLIT_F_HOST` already rides in every frame,
   which is the one input topology detection cannot work out locally.
6. Then the SOF phase servo, if the measured jitter ever justifies it — see §7a.

### Three things the arbitration design had to work around

**Collision detection is impossible on the discovery bus.** This silicon does not echo its own
half-duplex transmission (§13), so two halves hailing simultaneously simply do not hear each other and
neither can tell. Rather than detect collisions, the protocol makes sustained ones impossible: each half
hails on a period of `20 + (uid_tag & 15)` ms, so two halves cannot stay in lockstep — their phases
drift apart within a few periods and one hail lands in the other's listen window.

**Receive must be circular DMA, not a polled RDBF loop.** At 12 Mbaud a byte lands every 160 core
cycles. The remaining-count register doubles as the write pointer — but **mask it**: in circular mode it
reloads to the buffer length rather than resting at zero, so the naive subtraction can yield an index
the masked read pointer never reaches, and the scan loop never terminates. That runs in the same loop as
`tud_task()`, so the board simply never enumerates and the only way back in is BOOT0 + NRST. Every loop
in the link task is now explicitly bounded, and the task refuses to run for the first 1500 ms so USB is
always up first — the difference between a two-minute reflash over HID and asking someone to hold two
buttons.

**Keep the negotiated rate and the configured rate in separate variables.** Conflating them produced a
link that paired perfectly, reported RUNNING, and ran at 115200: the reconfigure helper overwrote the
target with whatever it was called with, including the discovery rate, so COMMIT carried 115200. The
same reconfigure also resets the receive ring, so the frame handler must tell the scanner to stop —
otherwise it walks stale bytes and re-acts on a COMMIT it already handled, which is what made one half
report five switches for one handshake.

---

## 13b. Framing: the run-phase data plane as built (2026-08-28)

`split.c` is what actually crosses J1 once `peer.c` has both halves at 12 Mbaud. Three deviations from
the plan in §5, all of them things the hardware or the measurement decided rather than the design.

**48 bytes, not 40, and CRC-32 rather than CRC-16.** The architecture doc costed CRC-16/CCITT on the
hardware CRC unit. That unit turns out to have a programmable polynomial (`CRC_POLY`, `POLY_SIZE` = 16b),
so CRC-16 *was* available — but its reset default is already the 32-bit Ethernet polynomial, it consumes
a **word** per write, and header + payload is 44 bytes = 11 words exactly. CRC-32 therefore costs the
same eleven register writes CRC-16 would have, needs no configuration at all, and detects every burst up
to 32 bits instead of 16. The two extra bytes are what makes the frame word-aligned in the first place.

| | |
|---|---|
| `0` sync | `0x5A` — deliberately *not* `peer.c`'s `0xA5`, so a control frame left in the ring across a rate change can never be parsed as data |
| `1` flags | keys / test-pattern / **this half has a host** |
| `2..3` seq | the receiver's only drop detector |
| `4..7` ctrl | piggybacked control channel: token transfer, layer state and lock LEDs ride here rather than on frames of their own, so the wire has exactly **one** frame shape |
| `8..43` keys | 32 × 9 bits = 36 bytes exactly — the reason §5 chose centi-mm |
| `44..47` crc | hardware CRC-32 over bytes 0..43 |

48 bytes at 12 Mbaud 8N1 = 480 bit-times = **40 µs**, against a 125 µs period: 32 % duty each way, and
the wire is idle for 85 µs between frames.

**No IDLE-line interrupt.** §5 specified IDLE-line delimiting. Clearing `IDLEF` requires reading `STS`
and then `DT` (RM 12.6.1), and with the receive DMA live that `DT` read races the DMA's own: the CPU
read clears `RDBF` and the DMA request for that byte is simply lost. The delimiting is done in software
instead, and it costs nothing — with an 85 µs gap between 40 µs frames the alignment is never in doubt.

**The receiver slides one byte on a rejected frame, not 48.** This is the part that would have been a
long-lived bug. Discovery frames are rare and separated by milliseconds, so the ring always starts on a
real sync byte and discarding a whole failed frame is free. Data frames are back-to-back at 8 kHz with
9-bit-packed payloads, and `0x5A` turns up *inside* a payload roughly one frame in five. Consuming 48
bytes from a false sync would swallow the genuine sync behind it — and then the next, and the next: a
link that mis-frames once would stay mis-framed. Sliding by one costs a CRC per false sync (tens of
nanoseconds) and re-locks inside a single frame period.

**Pacing is the ADC's own 8 kHz tick, not SOF.** `split_tx_due()` compares the published ADC frame index
against the last one sent. The frame therefore carries data at most one scan old, and the link rate
cannot drift against the scan rate because it *is* the scan rate. The SOF phase servo §6 anticipates is
still unbuilt, and the jitter measured below does not yet justify it.

### What it measures

Sequence numbers give drop detection; a deterministic payload generated from the sequence number alone
gives something a CRC cannot — it separates *corrupted and correctly discarded* from **accepted and
still wrong**:

| Counter | Meaning |
|---|---|
| `crc_errors` | a frame arrived corrupted and was thrown away. Small counts while re-locking are normal |
| `seq_gaps` | frames the peer's own sequence numbers say never arrived |
| `payload_errors` | good CRC, wrong contents. **Must be zero.** Anything else means a frame was accepted that was not the frame that was sent |
| `period_max_us` | worst inter-arrival — in practice, the longest the receiving half's main loop ever went without servicing the ring |

### The 9 ms debug print

First measurement of the framed link, both halves running:

```
5C13 rx 7,806/s   gaps +96/s (1.2 %)   crc 0   bad 0   inter-arrival 8 .. 8,645 us
5113 rx 7,805/s   gaps +96/s (1.2 %)   crc 0   bad 0   inter-arrival 8 .. 8,676 us
```

Zero corruption, but 1.2 % of frames simply never arrived, and the worst gap was **8.6 ms** — pinned to
that value, never growing, so periodic rather than random. Frames arriving 8 µs apart said the receiver
was draining several at once after a stall rather than losing them on the wire.

The cause was `main.c`'s periodic status line. `console_puts()` is a **blocking** polled write at
115200, and a ~100-character line stops the main loop for ~9 ms; the 512-byte ring holds 10.6 frames, so
everything past ~1.3 ms was lost. A first-light debug print nobody was reading was costing 96 frames a
second. Deleted — everything it printed is available over USB (`CMD_SNAPSHOT`, `RSP_INFO`).

> The general lesson, worth keeping: once the main loop has a real-time obligation, **any blocking
> console write is a fault**, not a diagnostic. The link's own jitter counter is what found it.

### After

```
5C13 rx 8,001.1/s  gaps 0  crc 0  resync 0  bad 0  inter-arrival 103 / 126 / 155 us
5113 rx 8,001.3/s  gaps 0  crc 0  resync 0  bad 0  inter-arrival 103 / 126 / 155 us
```

8 kHz both ways with nothing lost, and ±30 µs of jitter against a 125 µs period — comfortably inside one
microframe, which is why the SOF servo stays on the shelf for now.

End-to-end, live sensor data rather than a test pattern — each half's own ADC slots against what the
other half received:

```
5C13 own slots >>3 :  234  242  258    1  233  243  242
5113 received      :  234  242  258    1  233  244  242      max difference 1 count
5113 own slots >>3 :  255  255  255    1  254  258  255
5C13 received      :  255  255  255    1  254  258  255      max difference 0 counts
```

### The soak

180 s, both halves in test-pattern mode so every accepted frame is checked against a payload
regenerated from its own sequence number:

```
5C13:  tx 1,440,112 (8,000/s)   rx 1,440,114 (8,000/s)
5113:  tx 1,440,112 (8,000/s)   rx 1,440,110 (8,000/s)
       frames lost   0   (0.0000 %)
       crc rejects   0
       resync slides 0 bytes
       payload errs  0
       inter-arrival 83 / 128 / 171 us   and   84 / 123 / 159 us   (min/last/max)
```

**2,880,224 frames, zero errors of every kind**, over the 3 m cable. That is 1.38 × 10⁹ bit-times
without a single one going astray, so by the rule of three the bit error rate is **below 2 × 10⁻⁹ at
95 % confidence** — which is a bound set by how long the test ran, not by anything the link did.

Worst inter-arrival 171 µs against a 125 µs nominal: **+46 µs, or 37 % of one microframe.** That is the
receiving half's main-loop servicing latency, not wire jitter, and it is the number the SOF phase servo
would improve. It does not need improving yet.

### The accidental soak

The bench was then left alone and picked up 11 hours later, still running, counters never reset:

```
5C13  rx 317,821,329   crc 0   gaps 0   resync 0    rate re-measured: 8,000/s
5113  rx 317,820,879   crc 0   gaps 0   resync 0    rate re-measured: 8,000/s
peer: drops back to discovery 0 since the link came up
```

**635.6 million frames across the two directions — 3.1 × 10¹¹ bit-times — with zero CRC failures, zero
sequence gaps and zero resyncs**, and the link never once fell back to discovery. Read carefully, though:
the *payload* check only runs while the test pattern is on, which was 180 s of that window. For the
other 11 hours the guarantees in force were CRC-32 and sequence continuity, on live key data. Those are
the two that matter for "did every frame arrive intact and in order"; "was the frame the one that was
sent" rests on the 180 s figure above.

One wrinkle worth writing down because it looks alarming and is not: half 5C13 reports **2** switches
into RUNNING and **1** drop, against 5113's 1 and 0. That is the flashing order, not a link fault — 5C13
got the new image first and briefly paired with a 5113 still running the previous build, which answers
with 20 Hz PF_PING and never sends a data frame, so the new half's liveness timer expired exactly as
designed. It re-paired once both halves matched and has not dropped since. The failure mode is real and
worth remembering: **a mixed-firmware pair does not interoperate in the run phase**, and it presents as a
liveness drop rather than as anything that names a version. `peer_frame_t` already carries `fw`; nothing
yet refuses to pair on a mismatch.

### Version gating, and the deadlock it uncovered

The mixed-firmware failure above is now named rather than silent. `peer_frame_t` carries a **link
protocol version** — deliberately not the firmware build version, or every routine bump would split the
keyboard in half — and a mismatch parks both halves in `PEER_INCOMPAT`.

**A mismatch does not stop the halves talking.** Refusing to pair would remove the only channel that can
repair it: in topology (a) the far half has no host, so its next image has to arrive over this very link.
The halves stay on the 115200 discovery bus, keep hailing, and never step up to the run phase. That
places one permanent obligation on the design: **the first eight bytes of `peer_frame_t` are frozen
across every future version**, or two halves lose the ability to work out that they disagree. `peer.c`
static-asserts those offsets.

Verified by flashing one half and leaving the other on v1:

```
5C13: INCOMPATIBLE role=A tag=0x436A peer=0xF885 baud=115,200
      the peer speaks link protocol v1, this half does not.
5113: paired       role=B tag=0xF885 peer=0x436A baud=115,200
15 s later: 5C13 hails +30, switches +0, drops +0, crc +0 — parked, not thrashing
```

**Then flashing the second half did not recover, and that turned out to be a latent deadlock in the
arbitration that predates the version gate.** Numbers first:

```
5C13: state ALONE   hails +24   frames_rx +0     last frame 75,563 ms ago
5113: state PAIRED  hails  +0   frames_rx +24    last frame      63 ms ago
```

5113 was **receiving every one of A's hails and answering none of them**. `PF_HAIL` was only accepted
from `DISCOVER`/`ALONE`, so a half sitting in `PAIRED` ignored them — while each ignored hail still
refreshed `t_rx`, holding shut the very liveness escape (`since(t_rx) > 1500 ms`) that should have freed
it. A had missed a `HAIL_ACK` and fallen back to `ALONE`; B waited forever for a switch A no longer knew
to send. Both halves healthy, both halves hearing each other, permanently stuck.

Two fixes, fast path and backstop:

- **A hail is now answered from `PAIRED` and `SWITCHING` too.** A hail means the peer has forgotten the
  pairing, so holding the old one is waiting for a handshake that is never coming. `assign_roles()` is
  deterministic, so re-pairing is idempotent and costs one frame.
- **`PEER_PAIRED` is bounded by time in state, not by liveness.** Role B has no action of its own there,
  and a liveness timer fundamentally cannot bound a wait for one *specific* frame when any frame resets
  it. 300 ms, against the 5 ms A actually takes.

> The general lesson: **a liveness timeout is not a handshake timeout.** Any state whose exit depends on
> receiving one particular message needs its own bound on time-in-state; refreshing on unrelated traffic
> is what turns a missed frame into a permanent stall.

Regression test — 30 cycles restarting one half's arbitration at randomised phase while the other holds
the pairing:

```
30 cycles, 0 stuck, worst recovery 0.28 s
```

and the link still frames clean afterwards: 8,000/s each way, `crc 0  gaps 0  resync 0  bad 0`.

**The unit is provisional and the index is provisional.** There is no travel pipeline yet, so what ships
today is the raw 12-bit count shifted to 9 bits, and key *index* is hardware scan order because the
keymap layer that would give these positions names does not exist either. The transport is final; the
semantics are not.

## 13c. Dual-host bring-up, and the USB suspend gap (2026-08-28)

One half on the Mac, one on a Windows box, J1 between them. Both halves reached the run phase
unaided and framed at 12 Mbaud across two machines, and — the thing worth having — **each read
`SPLIT_F_HOST` set in the other's frames**. Topology (b) detecting itself, from both sides, with no
configuration. When the Windows half later lost its host, the Mac half's view of the peer flags went
from `k-H` to `k--` within a frame. That bit is the input topology detection cannot derive locally, and
it works.

### The board was power-cycling, and the frame counter proved it

Everything measured on the Windows side was, for a while, garbage: a 180 s run that produced zero USB
reports, a storm of `hid_read` errors, the link dropping to `alone`, and the host tool reporting "no
Giris found" seconds after a successful query. The firmware's own frame counter settled it:

```
  0.1s  frame 321,092   uptime 40.1s
  5.3s  device absent
 15.8s  frame  18,360   uptime  2.3s   <<< COUNTER WENT BACKWARDS - MCU REBOOTED
```

Not a re-enumeration — the MCU was restarting, sporadically, a few times per ten minutes. A monotonic
counter that survives nothing is a better disconnect detector than anything the host can offer, because
the host cannot tell a re-enumerated device from a rebooted one.

### Cause: we ignore USB suspend

The board is behind an Anker 556 hub — a hub is exactly where per-port power switching lives — and the
Windows box had **USB selective suspend enabled** with the device's per-device policy set to permit
power-down. Our firmware treats suspend as a telemetry event only: `tud_suspend_cb()` quiesces the
stream and nothing else. The part stays at 216 MHz with the ADC scanning, the link framing, and the HS
PHY up, which is orders of magnitude over the **2.5 mA** USB 2.0 §7.2.3 allows a suspended device. A hub
that cuts an over-budget suspended port produces exactly the observed symptom.

Disabling power-down for the device and both hub nodes:

| | resets observed |
|---|---|
| before | 3 in ~10 minutes of watching |
| after | **0 in 300 s, uptime 300.7 s continuous** |

That is a workaround on one machine, not a fix. **Honouring USB suspend is unfinished firmware work**,
and it is not optional for a keyboard: any host that sleeps will do this. It is also entangled with the
split, because a suspended half stops framing and its peer drops the link after 250 ms — in dual-host
topology (b) one host may sleep while the other is wide awake, so "suspended" must mean *this half stops
talking to its own host*, not *this half stops working*. Remote wakeup has to arrive at the same time.

### `RSP_INFO[48]`: why the MCU last reset

Added because the ambiguity above cost hours. `CRM_CTRLSTS` records the cause; the flags are sticky
(RM 4.3.21) so `reset_capture()` reads and clears them first thing in `main()`, or every later boot
reports the reason for the first one.

The distinction that matters is **power-on reset versus anything else**: a POR means VBUS or the 3.3 V
rail actually went away, which no firmware could have prevented. Verified rather than assumed — the
first boot after the old image read `POR + NRST + software` (correct: nothing had ever cleared them, so
they had accumulated since the board's original power-up), and the next read `0x06`, NRST + software,
with POR correctly absent.

Suspend and resume counts sit alongside it, because a host that suspends us and a hub that cuts our
power look identical from outside: a suspend that does not end in a reset shows in the counter, one that
does shows as `RESET_POR` on the next boot.

### The TX completion race — found only under combined load

With the resets gone, the full-load test earned its keep immediately. 300 s with the Windows half
running everything at once — 8 kHz scan, 8 kHz link both ways, 8 kHz USB HID:

| | Windows half (**under full USB load**) | Mac half (idle host) |
|---|---|---|
| usb | 7,994/s host, 8,000/s device, 0 dropped | — |
| link rx | 8,000/s | 7,994/s |
| **crc errors** | **0** | **1,661** |
| **frames lost** | **0** | **1,654** |
| resync slides | 0 | 52,594 |

The asymmetry is what named the bug. The *loaded* half received flawlessly; the *idle* half saw 5.5
corrupt frames a second. So the fault was never in reception — it was in what the busy half
**transmitted**. A control run with the loaded half idle confirmed it: 112 s, zero errors of every kind.

The cause is in `tx_done()`, which declared a frame sent on `USART_TDC_FLAG` alone:

> **TDC says only that the shift register drained.** It drains just the same in the gap left when a
> starved DMA fails to deliver the next byte in time. On TDC alone, `tx_done()` reports "sent" while the
> DMA still has bytes to fetch; the main loop then rebuilds the frame buffer underneath it, and the tail
> of one frame goes out as the head of the next.

Which is why it needs *both* halves loaded to appear: the OTG core's DMA has to be contending for the
bus hard enough to starve the USART TX channel mid-frame. On an idle half it never happens. Fix is one
line — also require `dma_data_number_get(DMA1_CHANNEL3) == 0`.

Confirmed by reversing the roles, which the split makes free: load the **fixed** half instead and watch
the unfixed one. Same 8 kHz USB, same link, opposite direction:

```
  30.1s  rx 7,999/s  gaps+0  crc+0  resync+0  bad+0
  60.1s  rx 8,000/s  gaps+0  crc+0  resync+0  bad+0
```

Zero, where the unfixed transmitter produced ~330 errors in the same 60 s. The loaded half meanwhile
held 8,000 USB reports/s with 0 read errors.

> Worth keeping: **a peripheral's "done" flag and its DMA's "done" are different facts.** Any DMA-fed
> transmitter needs both, and the gap between them only opens under bus contention — so it will not
> appear in any test that loads one subsystem at a time.

### A host tool can take down a host controller

Worth recording as a hazard in its own right. While the board was flapping, `loadtest.py` reacted to
each failed read with a bare `continue`. A failing read returns instantly, so that became **~44,500
`hid_read` calls per second** — 889,778 read errors in 20 s — and the AMD xHCI controller it was aimed
at ended in `CM_PROB_FAILED_POST_START`, taking a reboot to recover. Its teardown was also not
unconditional: `snapshot()` raised inside the `finally`, so the stream-off after it never ran and the
board was left streaming into a host with nothing reading it — the same condition that took down a
controller earlier in this bring-up (§15).

Both are fixed: failed reads back off, a budget aborts the run, and teardown always executes. The rule
generalises — **a diagnostic that reacts to failure by retrying as fast as it can is a denial-of-service
tool**, and the thing it takes down is the thing you were trying to measure.

## 13d. USB suspend, and why a Hall keyboard cannot wake the normal way

### The constraint

A mechanical keyboard suspends by stopping everything and arming a GPIO interrupt: the switch shorts a
pin, an edge fires, the MCU wakes from deep sleep having drawn microamps. **None of that is available
here.** A TMR2615 has no contact and produces no edge — its output at rest is a mid-scale voltage
indistinguishable from its output under a finger except by *measuring* it. Detecting a press requires
running the mux and the ADC.

Checked for an escape and there isn't one on this part: the only comparators in the reference manual are
the timers' own output-compare units, so there is no standalone analog comparator to sit on a key while
the core sleeps. The ADC's voltage monitor (`VMOR`, thresholds plus interrupt) is the useful refinement —
it does not remove the need to convert, but it lets the CPU sleep between conversions instead of
inspecting every sample. Worth building; not built yet.

So **suspend here means scan slower, not stop.** 500 Hz instead of 8 kHz: a 16x cut in mux and ADC duty,
with a press still seen inside 2 ms — far below anything a person notices when waking a machine.

Be honest about what this is: it does **not** reach the 2.5 mA USB 2.0 §7.2.3 allows a suspended device.
Getting there needs the PLL stopped and the OTG PHY in low-power mode. What it does is remove the two
largest consumers that were running for no reason — a full-rate scan nobody was reading, and the LEDs.

### The split makes suspend a three-state problem

In topology (b) each half has its own host and **they sleep independently.** If half A's host sleeps
while half B's is wide awake, A's keys must keep reaching B — the person is still typing, just on the
other machine. A half that powered down on suspend would silently kill half the keyboard.

That forced `SPLIT_F_HOST` to split in two. It meant "enumerated", which stays true across a suspend;
the power policy needs "awake", which does not. Conflating them means a half can never stop serving a
sleeping peer:

| flag | question it answers | used by |
|---|---|---|
| `SPLIT_F_HOST` | is there a host on that end at all | topology detection |
| `SPLIT_F_AWAKE` | is anyone over there who still needs my keys | power policy |

| state | meaning | scan |
|---|---|---|
| `POWER_RUN` | our host is awake | 8 kHz |
| `POWER_SERVING` | our host sleeps, the **peer's** host is awake | **8 kHz** — costs current, and is still right |
| `POWER_SUSPENDED` | nobody needs us | 500 Hz |

Measured across all four transitions, both halves:

```
both awake          5C13 run       8,000 Hz   peer k-HA
5C13 host asleep    5C13 SERVING   8,000 Hz   peer sees k-H-   (AWAKE cleared, HOST kept)
both asleep         5C13 SUSPENDED   500 Hz   peer k-H-
resumed             5C13 run       8,000 Hz   peer k-HA
```

### Two things the measurement caught that reasoning did not

**The low-power rate was 11x wrong.** `tmr_base_init()` takes a 32-bit period and the driver's struct
declares it 32-bit, but TMR2 implements 16: a period of 215999 came back as `215999 & 0xFFFF` = 19391,
giving **5,569 Hz instead of 500**. Reached with the prescaler instead — 216 MHz / 216 = 1 MHz, / 1000 =
1 kHz timer = 500 Hz frames — which keeps both numbers inside any timer on the part.

**Every rate change produced a spurious wake.** `adc_resync()` realigns the mux bank with the DMA ring,
and the frame straddling that realignment can carry one bank's readings in the other's slots. Taken as
the wake baseline, it makes every following frame look like a huge deflection: exactly one false wake
per transition, with nobody near the keyboard. A false wake is the worst failure this code can produce —
it wakes someone's machine at random — so the baseline now starts from a settled frame. 20 s suspended,
untouched, both halves: **0 attempts.**

### Remote wakeup

`TUSB_DESC_CONFIG_ATT_REMOTE_WAKEUP` was already in the config descriptor; what was missing was
everything behind it. `tud_suspend_cb()` now records whether the host actually granted
`SET_FEATURE(DEVICE_REMOTE_WAKEUP)`, and a press while suspended calls `tud_remote_wakeup()`.

`RSP_INFO` reports attempts and grants separately, because they answer the question anyone debugging
"my keyboard won't wake the machine" actually has:

| reading | meaning |
|---|---|
| attempts 0 | the press was never detected — threshold or scan rate |
| attempts > 0, grants 0 | **the host refused remote wakeup**, nothing wrong with the keyboard |
| grants > 0, machine still asleep | we signalled and the OS ignored it — a wake-source policy question |

The remaining unknown is whether a **vendor-defined HID** is a permitted wake source at all. A HID
keyboard is; a vendor collection frequently is not. That cannot be settled without a host that really
sleeps, and it may resolve itself once there is a real keyboard interface — which carries its own cost
on macOS, since keyboard usages are what make it demand Input Monitoring to open the device (§main.c).
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

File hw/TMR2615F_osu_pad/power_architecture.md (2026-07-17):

# osu pad — master/slave power & interconnect architecture

> **Implementation status (2026-07-05):** items 1–9 are DONE in the schematic — U4 CE→VOUT; U5 EN on
> PC13 (net `/PW_PSTRH`, R27 10 k pulldown); J2 VBUS split to `/VBUS_HOST` via U29 (ST tied to GND,
> C56 10 µF); J4 VBUS disconnected (data-only) with R4/R5 CC Rd populated; J1 CC Rd (R28/R29 5.1 k);
> `/VBUS_B` divider R30/R31 10 k/10 k + C57 47 nF + R32 330 Ω into mux **S4A** (VBUS reads on SEL=0);
> R3 pull-up on +3.3V; bulk caps moved behind the switches (C10 22 µF stays at J1); R8 BOOT0 now 10 k.
> Net renames: `/AP_FAULT` (U5 FAULT#→PB10), `/LM_ST` (U4 ST→PB12).
> **Still open:** the inter-board data link rework (U1 delete → half-duplex UART, below) + J1 data ESD;
> optional: move U5.IN to `/VBUS_HOST` (saves one diode drop to the slave); LED level-shift decision.
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

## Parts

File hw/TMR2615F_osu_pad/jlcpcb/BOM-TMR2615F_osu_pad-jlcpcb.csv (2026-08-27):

Comment | Designator | Footprint | LCSC Part #
CL21A226MAQNNNE | C1,C2,C3,C4,C5,C6 | C_0805_2012Metric | C45783
CL21A106KAYNNNE | C7,C12,C13,C20,C21 | C_0805_2012Metric | C15850
CL05B104KB54PNC | C8,C11,C19,C23,C25,C26,C27,C28,C29,C30,C35,C36,C39,C40,C43,C44,C47,C48,C51,C52,C55,C56 | C_0402_1005Metric | C307331
CL21A476MQYNNNE | C9 | C_0805_2012Metric | C16780
CL10B332KB8NNNC | C10,C34,C38,C42,C46,C50,C54 | C_0603_1608Metric | C1613
CL05A105KA5NQNC | C14,C22 | C_0402_1005Metric | C52923
CL10A475KO8NNNC | C24 | C_0603_1608Metric | C19666
0402CG300J500NT | C31,C32 | C_0402_1005Metric | C1570
1N4148WS_T4 | D1 | D_SOD-323_HandSoldering | C2128
TYPE-C-31-M-12 | J1,J2,J3 | USB-C_SMD-TYPE-C-31-M-12_1 | C165948
XY-SH1_0-4A61 | J4 | CONN-SMD_4P-P1.00_XYECONN_XY-SH1.0-4A61 | C19271998
GZ1608D601TF | L1 | L_0603_1608Metric | C1002
KT-0603W | LED1,LED2 | LED0603-R-RD_WHITE | C2290
0402WGF1002TCE | R1,R2,R4,R5,R6,R9,R10,R28 | R_0402_1005Metric | C25744
0402WGF1200TCE | R3,R7,R14,R16,R21,R27 | R_0402_1005Metric | C25079
0402WGF5101TCE | R8,R12,R13,R15,R17,R18,R19,R20,R22,R29,R30,R31,R32,R33,R34 | R_0402_1005Metric | C25905
0402WGF2202TCE | R11 | R_0402_1005Metric | C25768
0402WGF3300TCE | R23,R24 | R_0402_1005Metric | C25104
0402WGF1202TCE | R25 | R_0402_1005Metric | C25752
0402WGF3301TCE | R26 | R_0402_1005Metric | C25890
SKSGPAE010 | SW1,SW2 | SW-SMD_SKSGAAE010 | C125045
CPG151101S11-16 | SW3,SW4,SW5,SW6,SW7,SW8 | SMD_KEYBOARD-SW | C41430893
TestPoint | TP1,TP2,TP3,TP4,TP5,TP6,TP7,TP8,TP9,TP10,TP11,TP12,TP13,TP14,TP15,TP16,TP17,TP18,TP19,TP20,TP21,TP22 | TestPoint_Pad_D1.0mm
SRV05-4A | U1,U5,U9 | SOT-23-6 | C20615829
LM66100DCK | U2,U7 | SOT-363_SC-70-6 | C2869734
AP22653W6-7 | U3 | SOT-23-6_L2.9-W1.6-P0.95-LS2.8-BR | C2158037
TPS7A4700 | U4 | VQFN-20_L5.0-W5.0-P0.65-TL-EP | C28286
XC6206P332MR | U8 | SOT-23-3_L2.9-W1.6-P1.90-LS2.8-BR | C5446
AT32F405RBT7-7 | U10 | LQFP-64_L7.0-W7.0-P0.40-LS9.0-BL | C47115472
TMUX1574RSVR | U11 | UQFN-16_L2.6-W1.8-P0.40-BL | C2673120
SK6812MINI-E | U12,U14,U16,U18,U20,U22,U24 | LED-SMD_4P-L3.2-W2.8-LS5.9_SK6812MINI-E | C5149201
TMR2615F-AAC-1.500-500 | U13,U15,U17,U19,U21,U23 | DFN3L(1.6x1.6x0.5) | C9900212297
PESD5V0R1BSFYL | U25,U26 | SOD-962_L0.6-W0.3-BI | C461221
X322512MSB4SI | X1 | X322512MSB4SI | C9002

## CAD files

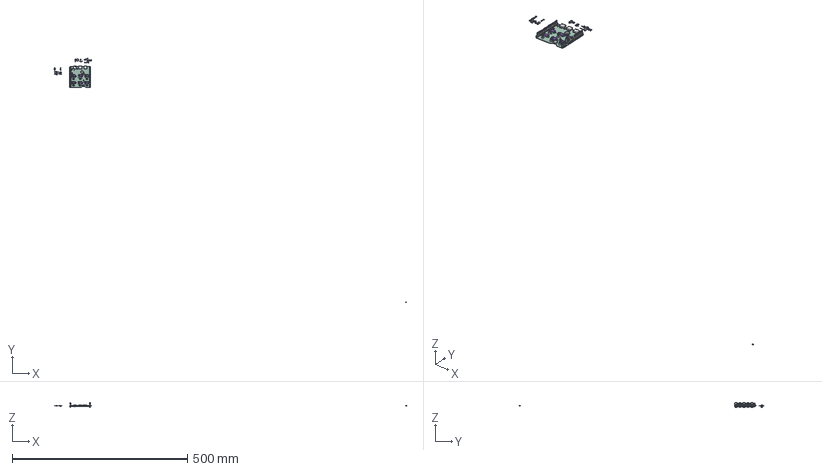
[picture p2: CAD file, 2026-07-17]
hw/TMR2615F_osu_pad/.step
1003.4 x 695.7 x 11.5 mm
SOT-363_SC-70-6 x 2
TMR2615F x 6
C_0805_2012Metric x 12
R_0402_1005Metric x 33
C_0603_1608Metric x 8
PinHeader_1x02_P254mm_Horizontal
C_0402_1005Metric x 36
L_0603_1608Metric
零件2 x 6
PinHeader_1x06_P254mm_Vertical
SOT-23-3L_L2.9-W1.6-H1.1-LS2.8-P0.95
零件1
USB-C_SMD-TYPE-C-31-M-12 x 3
LED-SMD_4P-L3.2-W2.8-LS5.9_SK6812MINI-E x 7
SOT-23-6_L2.9-W1.6-P0.95-LS2.9-BL x 4
PinHeader_1x10_P254mm_Vertical
SW-SMD_SKSGAAE010 x 2
VQFN-20_L5.0-W5.0-H1.0-P0.65
D_SOD-323
PinHeader_1x04_P254mm_Vertical
OSC-SMD_4P-L3.2-W2.5-CJ13-320001210A20
CONN-SMD_4P-P1.00-WT
LED0603-RD_ORANGE x 2
SOT-23-6_L2.9-W1.6-H1.5-LS2.8-P0.95
PinHeader_1x23_P254mm_Vertical
UQFN-16_L2.6-W1.8-H0.5-P0.40-BL
TMR2615F_osu_pad_PCB

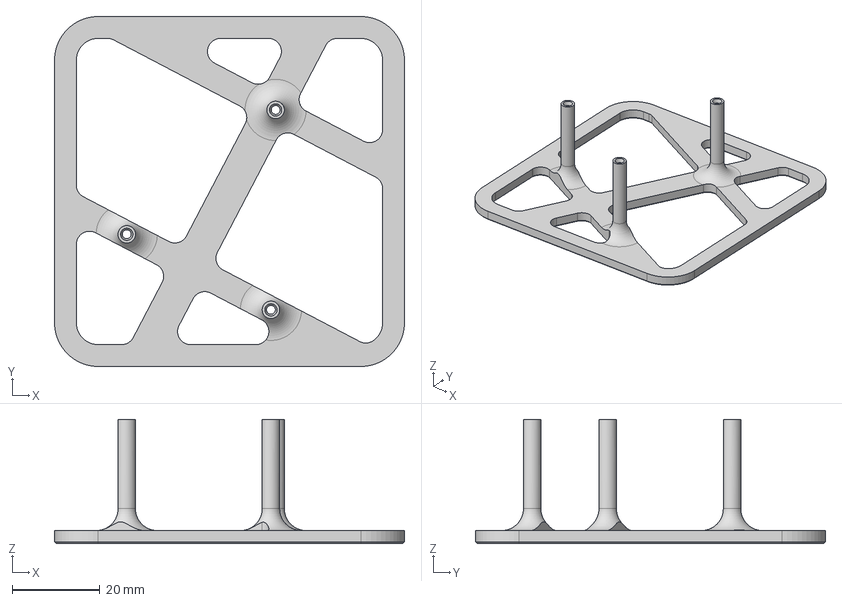
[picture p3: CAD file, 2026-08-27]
mech/osu_pad_dev_frame.step
80.0 x 80.0 x 28.4 mm

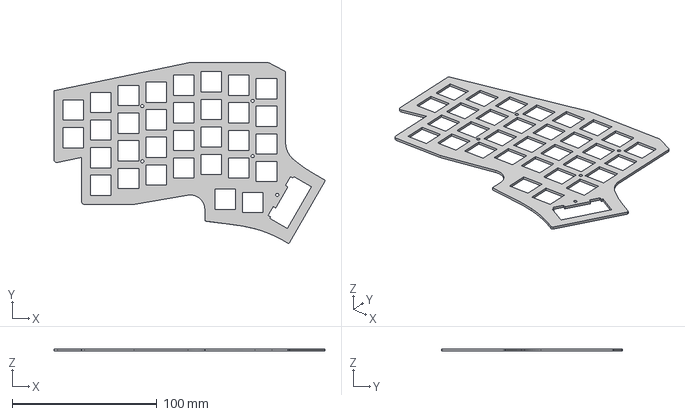
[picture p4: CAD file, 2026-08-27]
mech/combined.step
187.0 x 124.7 x 1.50 mm

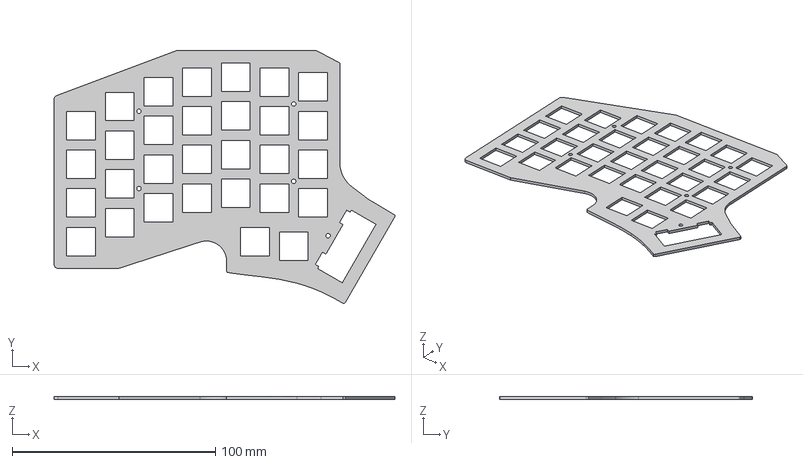
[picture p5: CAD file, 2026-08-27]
mech/Giris Plate.step
168.0 x 124.7 x 1.50 mm

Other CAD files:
hw/TMR2615F_osu_pad/output/osupad.step
mech/osu_pad_dev_frame.stl

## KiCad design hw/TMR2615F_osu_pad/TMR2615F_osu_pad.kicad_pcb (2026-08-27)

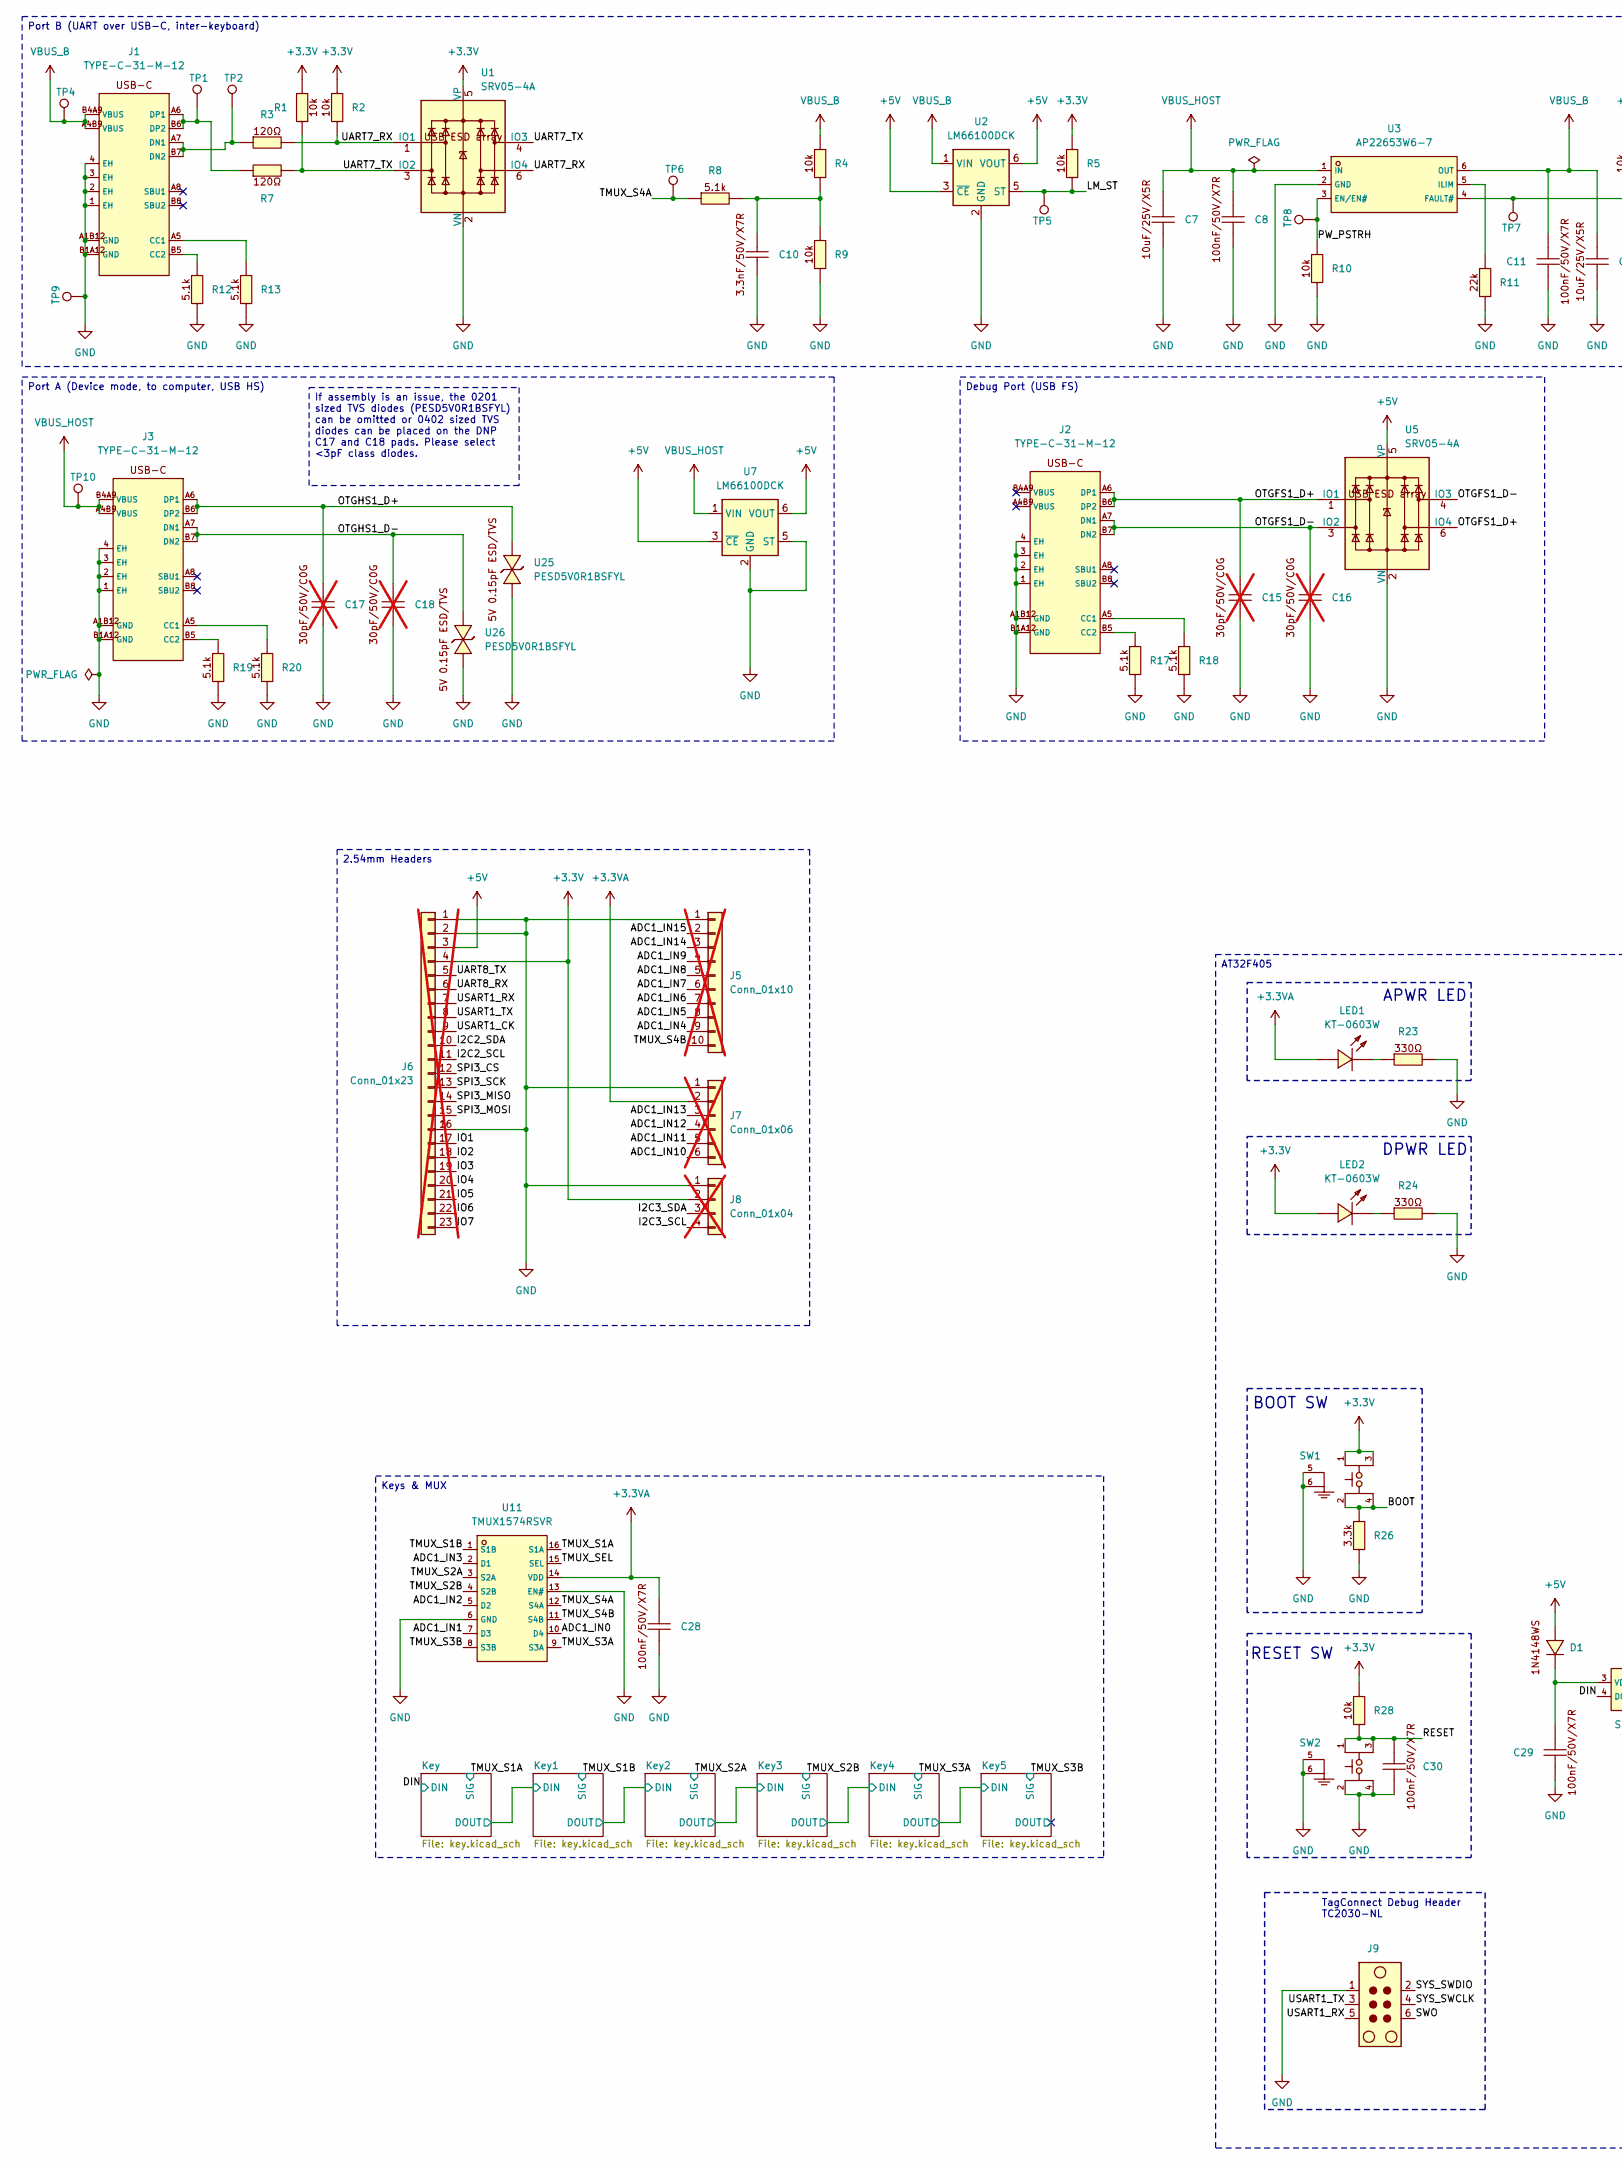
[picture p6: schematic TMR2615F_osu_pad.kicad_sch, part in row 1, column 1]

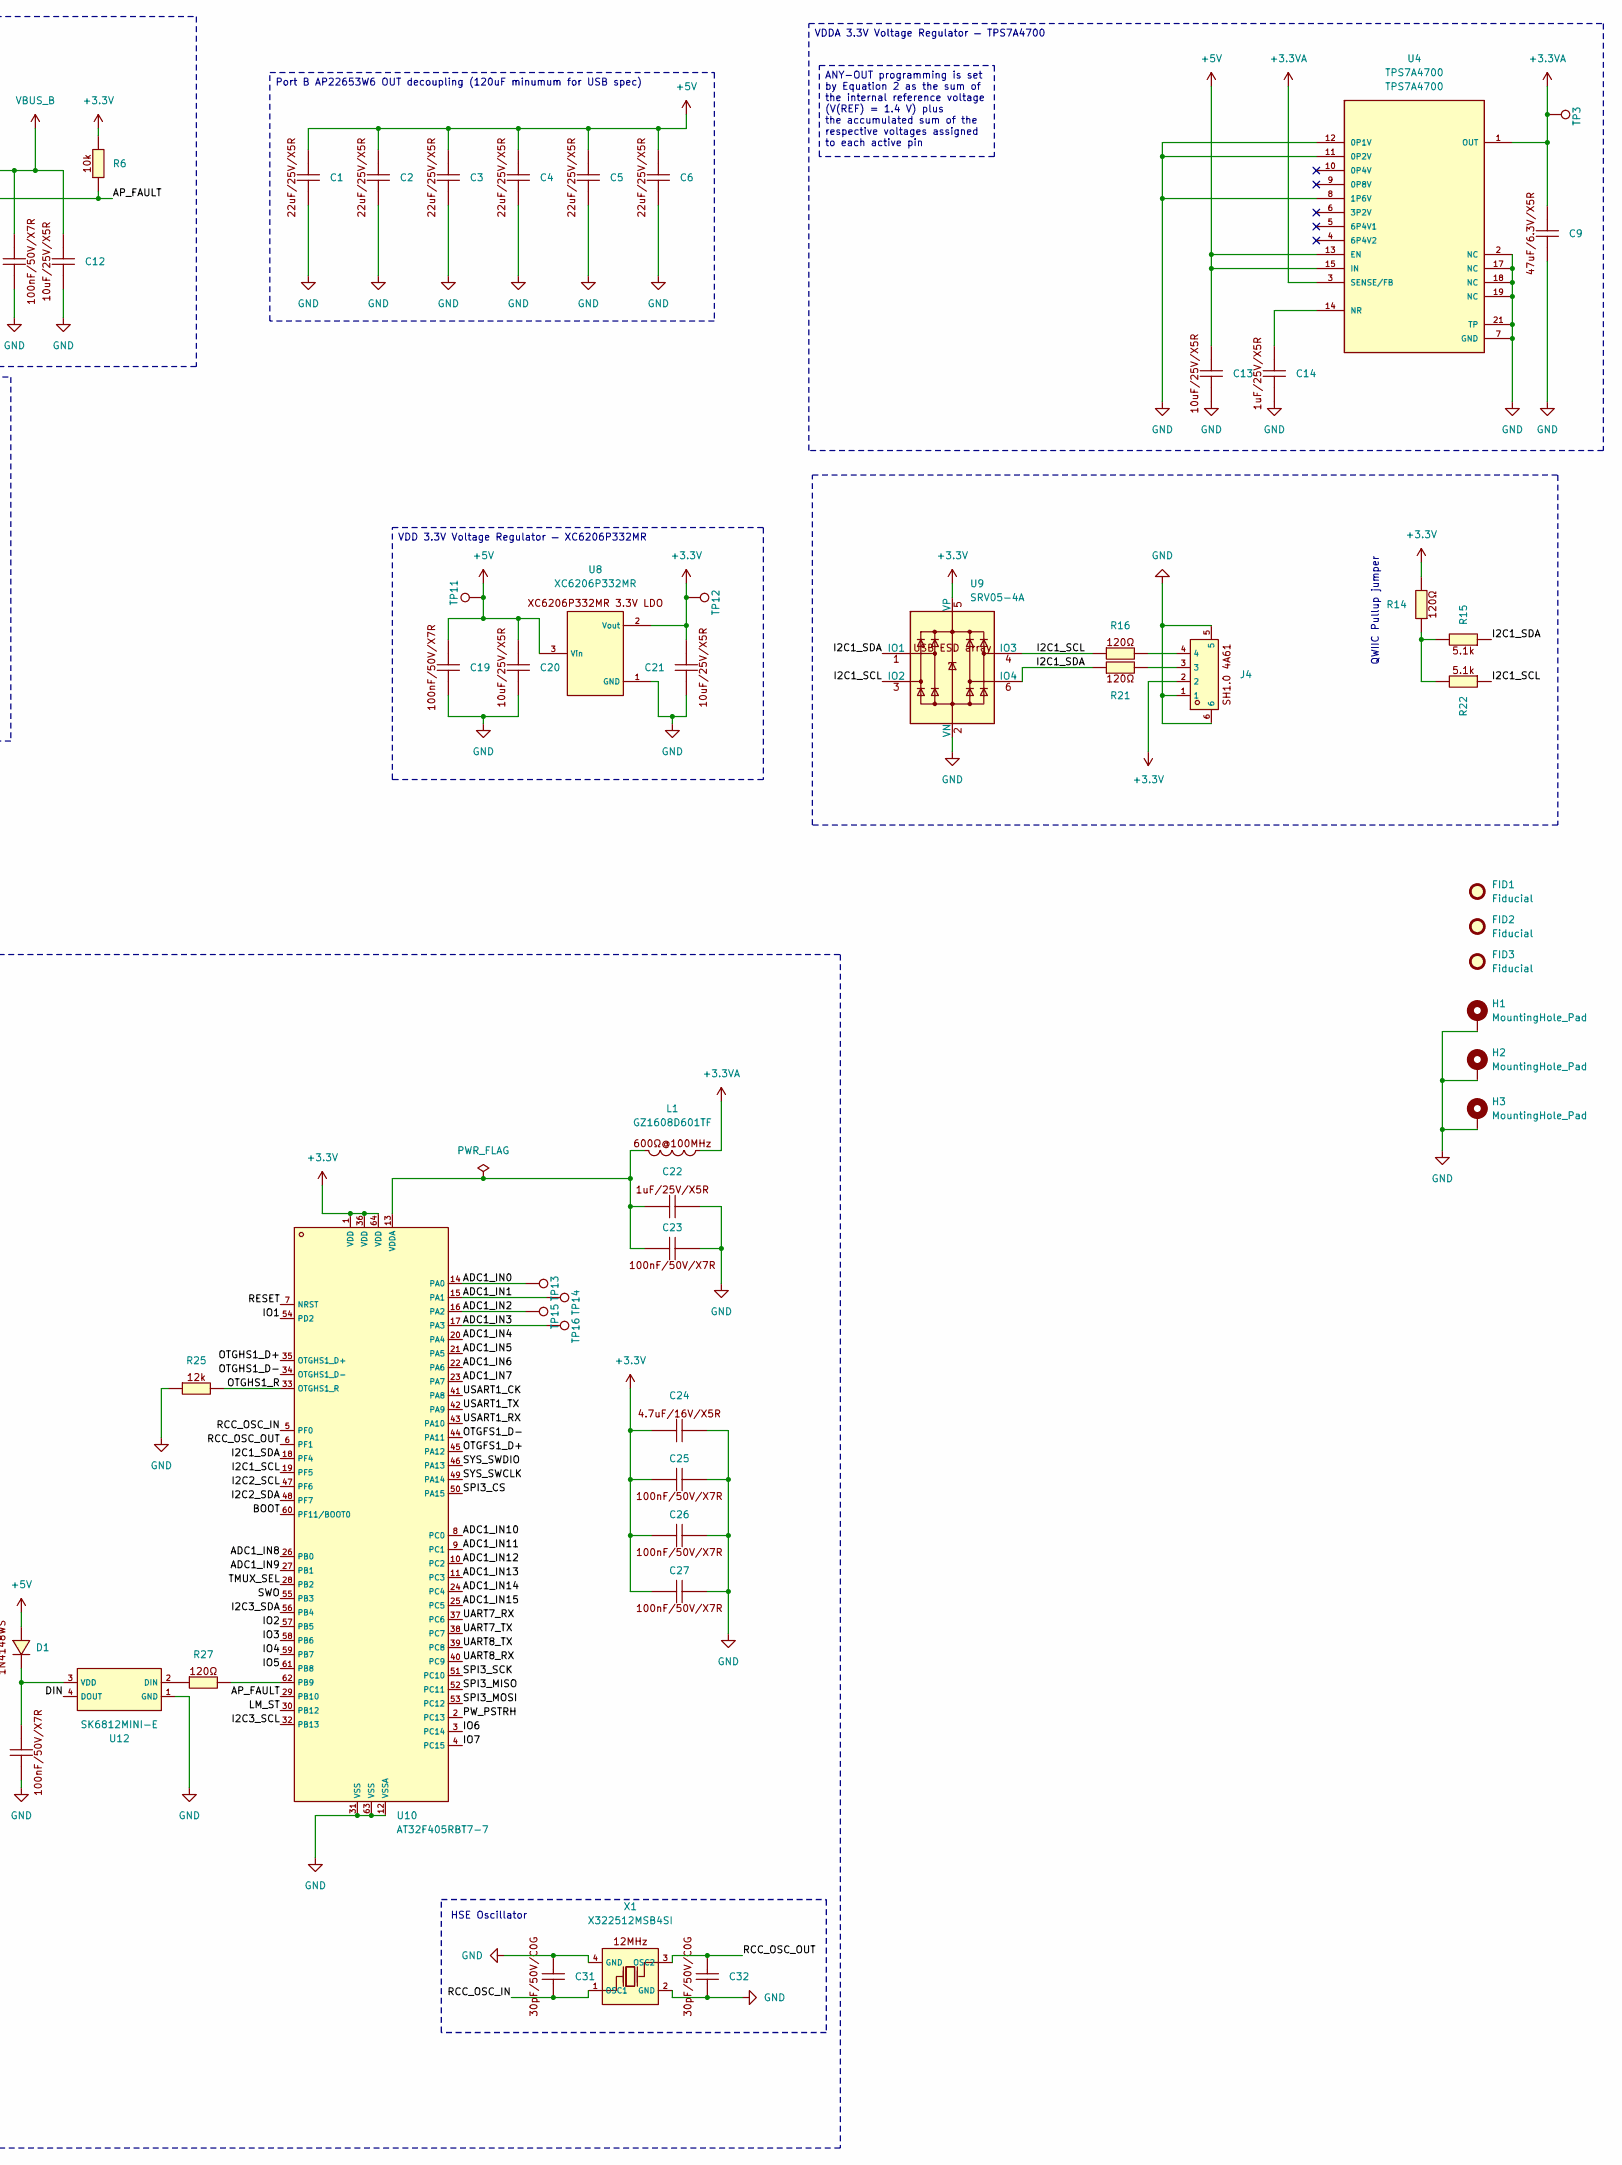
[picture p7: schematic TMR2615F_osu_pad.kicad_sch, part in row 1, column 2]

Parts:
C1, C2, C3, C4, C5, C6: CL21A226MAQNNNE; C_0805_2012Metric; LCSC C45783
C7, C12, C13, C20, C21: CL21A106KAYNNNE; C_0805_2012Metric; LCSC C15850
C8, C11, C19, C23, C25, C26, C27, C28, C29, C30: CL05B104KB54PNC; C_0402_1005Metric; LCSC C307331
C9: CL21A476MQYNNNE; C_0805_2012Metric; LCSC C16780
C10: CL10B332KB8NNNC; C_0603_1608Metric; LCSC C1613
C14, C22: CL05A105KA5NQNC; C_0402_1005Metric; LCSC C52923
C15, C16, C17, C18: 0402CG300J500NT; C_0402_1005Metric; LCSC C1570; not fitted
C24: CL10A475KO8NNNC; C_0603_1608Metric; LCSC C19666
C31, C32: 0402CG300J500NT; C_0402_1005Metric; LCSC C1570
D1: 1N4148WS_T4; D_SOD-323_HandSoldering; LCSC C2128
FID1, FID2, FID3: Fiducial; Fiducial_1mm_Mask2mm
H1, H2, H3: MountingHole_Pad; MountingHole_2.2mm_M2_Pad_Via
J1, J2, J3: TYPE-C-31-M-12; USB-C_SMD-TYPE-C-31-M-12_1; LCSC C165948
J4: XY-SH1_0-4A61; CONN-SMD_4P-P1.00_XYECONN_XY-SH1.0-4A61; LCSC C19271998
J5: Conn_01x10; PinHeader_1x10_P2.54mm_Vertical; not fitted
J6: Conn_01x23; PinHeader_1x23_P2.54mm_Vertical; not fitted
J7: Conn_01x06; PinHeader_1x06_P2.54mm_Vertical; not fitted
J8: Conn_01x04; PinHeader_1x04_P2.54mm_Vertical; not fitted
J9: Tag-Connect_TC2030-IDC-NL_2x03_P1.27mm_Vertical
L1: GZ1608D601TF; L_0603_1608Metric; LCSC C1002
LED1, LED2: KT-0603W; LED0603-R-RD_WHITE; LCSC C2290
R1, R2, R4, R5, R6, R9, R10, R28: 0402WGF1002TCE; R_0402_1005Metric; LCSC C25744
R3, R7, R14, R16, R21, R27: 0402WGF1200TCE; R_0402_1005Metric; LCSC C25079
R8, R12, R13, R15, R17, R18, R19, R20, R22: 0402WGF5101TCE; R_0402_1005Metric; LCSC C25905
R11: 0402WGF2202TCE; R_0402_1005Metric; LCSC C25768
R23, R24: 0402WGF3300TCE; R_0402_1005Metric; LCSC C25104
R25: 0402WGF1202TCE; R_0402_1005Metric; LCSC C25752
R26: 0402WGF3301TCE; R_0402_1005Metric; LCSC C25890
SW1, SW2: SKSGPAE010; SW-SMD_SKSGAAE010; LCSC C125045
TP1, TP2, TP3, TP4, TP5, TP6, TP7, TP8, TP9, TP10, TP11, TP12, TP13, TP14, TP15, TP16: TestPoint; TestPoint_Pad_D1.0mm
U1, U5, U9: SRV05-4A; SOT-23-6; LCSC ID C20615829
U2, U7: LM66100DCK; SOT-363_SC-70-6; LCSC C2869734
U3: AP22653W6-7; SOT-23-6_L2.9-W1.6-P0.95-LS2.8-BR; LCSC C2158037
U4: TPS7A4700; VQFN-20_L5.0-W5.0-P0.65-TL-EP; LCSC C28286
U8: XC6206P332MR; SOT-23-3_L2.9-W1.6-P1.90-LS2.8-BR; LCSC C5446
U10: AT32F405RBT7-7; LQFP-64_L7.0-W7.0-P0.40-LS9.0-BL; LCSC C47115472
U11: TMUX1574RSVR; UQFN-16_L2.6-W1.8-P0.40-BL; LCSC C2673120
U12: SK6812MINI-E; LED-SMD_4P-L3.2-W2.8-LS5.9_SK6812MINI-E; LCSC C5149201
U25, U26: PESD5V0R1BSFYL; SOD-962_L0.6-W0.3-BI; LCSC C461221
X1: X322512MSB4SI; LCSC C9002

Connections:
+3.3V: C21.1, C24.1, C25.2, C26.2, C27.2, J4.2, J6.4, J8.2, LED2.1 (A), R1.2, R2.2, R5.2, R6.2, R14.2, R28.2, SW1.1, SW1.3, TP12.1 (1_1), U1.5 (VP), U8.2 (Vout), U9.5 (VP), U10.1 (VDD), U10.36 (VDD), U10.64 (VDD)
+3.3VA: C9.2, C28.2, J7.2, L1.2, LED1.1 (A), TP3.1 (1_1), U4.1 (OUT), U4.3 (SENSE/FB), U4.20 (OUT), U11.14 (VDD); also elsewhere on the board
+5V: C1.2, C2.2, C3.2, C4.2, C5.2, C6.2, C13.2, C19.2, C20.2, D1.2 (A), J6.3, TP11.1 (1_1), U2.3 (~CE), U2.6 (VOUT), U4.13 (EN), U4.15 (IN), U4.16 (IN), U5.5 (VP), U7.3 (~CE), U7.6 (VOUT), U8.3 (Vin); also elsewhere on the board
/ADC1_IN0: TP13.1 (1_1), U10.14 (PA0), U11.10 (D4)
/ADC1_IN1: TP14.1 (1_1), U10.15 (PA1), U11.7 (D3)
/ADC1_IN2: TP15.1 (1_1), U10.16 (PA2), U11.5 (D2)
/ADC1_IN3: TP16.1 (1_1), U10.17 (PA3), U11.2 (D1)
/ADC1_IN4: J5.9, U10.20 (PA4)
/ADC1_IN5: J5.8, U10.21 (PA5)
/ADC1_IN6: J5.7, U10.22 (PA6)
/ADC1_IN7: J5.6, U10.23 (PA7)
/ADC1_IN8: J5.5, U10.26 (PB0)
/ADC1_IN9: J5.4, U10.27 (PB1)
/ADC1_IN10: J7.6, U10.8 (PC0)
/ADC1_IN11: J7.5, U10.9 (PC1)
/ADC1_IN12: J7.4, U10.10 (PC2)
/ADC1_IN13: J7.3, U10.11 (PC3)
/ADC1_IN14: J5.3, U10.24 (PC4)
/ADC1_IN15: J5.2, U10.25 (PC5)
/AP_FAULT: R6.1, TP7.1 (1_1), U3.4 (FAULT#), U10.29 (PB10)
/BOOT: R26.2, SW1.2, SW1.4, U10.60 (PF11/BOOT0)
/DIN: U12.4 (DOUT); also elsewhere on the board
/I2C1_SCL: R16.1, R22.1, U9.3 (IO2), U9.4 (IO3), U10.19 (PF5)
/I2C1_SDA: R15.1, R21.1, U9.1 (IO1), U9.6 (IO4), U10.18 (PF4)
/I2C2_SCL: J6.11, U10.47 (PF6)
/I2C2_SDA: J6.10, U10.48 (PF7)
/I2C3_SCL: J8.4, U10.32 (PB13)
/I2C3_SDA: J8.3, U10.56 (PB4)
/IO1: J6.17, U10.54 (PD2)
/IO2: J6.18, U10.57 (PB5)
/IO3: J6.19, U10.58 (PB6)
/IO4: J6.20, U10.59 (PB7)
/IO5: J6.21, U10.61 (PB8)
/IO6: J6.22, U10.3 (PC14)
/IO7: J6.23, U10.4 (PC15)
/LM_ST: R5.1, TP5.1 (1_1), U2.5 (ST), U10.30 (PB12)
/OTGFS1_D+: C15.2, J2.A6 (DP1), J2.B6 (DP2), U5.1 (IO1), U5.6 (IO4), U10.45 (PA12)
/OTGFS1_D-: C16.2, J2.A7 (DN1), J2.B7 (DN2), U5.3 (IO2), U5.4 (IO3), U10.44 (PA11)
/OTGHS1_D+: C17.2, J3.A6 (DP1), J3.B6 (DP2), U10.35 (OTGHS1_D+), U25.2
/OTGHS1_D-: C18.2, J3.A7 (DN1), J3.B7 (DN2), U10.34 (OTGHS1_D-), U26.2
/OTGHS1_R: R25.2, U10.33 (OTGHS1_R)
/PW_PSTRH: R10.2, TP8.1 (1_1), U3.3 (EN/EN#), U10.2 (PC13)
/RCC_OSC_IN: C31.1, U10.5 (PF0), X1.1 (OSC1)
/RCC_OSC_OUT: C32.2, U10.6 (PF1), X1.3 (OSC2)
/RESET: C30.2, R28.1, SW2.1, SW2.3, U10.7 (NRST)
/SPI3_CS: J6.12, U10.50 (PA15)
/SPI3_MISO: J6.14, U10.52 (PC11)
/SPI3_MOSI: J6.15, U10.53 (PC12)
/SPI3_SCK: J6.13, U10.51 (PC10)
/SWO: J9.6, U10.55 (PB3)
/SYS_SWCLK: J9.4, U10.49 (PA14)
/SYS_SWDIO: J9.2, U10.46 (PA13)
/TMUX_S1A: U11.16 (S1A); also elsewhere on the board
/TMUX_S1B: U11.1 (S1B); also elsewhere on the board
/TMUX_S2A: U11.3 (S2A); also elsewhere on the board
/TMUX_S2B: U11.4 (S2B); also elsewhere on the board
/TMUX_S3A: U11.9 (S3A); also elsewhere on the board
/TMUX_S3B: U11.8 (S3B); also elsewhere on the board
/TMUX_S4A: R8.1, TP6.1 (1_1), U11.12 (S4A)
/TMUX_S4B: J5.10, U11.11 (S4B)
/TMUX_SEL: U10.28 (PB2), U11.15 (SEL)
/UART7_RX: R2.1, R3.2, U1.1 (IO1), U1.6 (IO4), U10.37 (PC6)
/UART7_TX: R1.1, R7.2, U1.3 (IO2), U1.4 (IO3), U10.38 (PC7)
/UART8_RX: J6.6, U10.40 (PC9)
/UART8_TX: J6.5, U10.39 (PC8)
/USART1_CK: J6.9, U10.41 (PA8)
/USART1_RX: J6.7, J9.5, U10.43 (PA10)
/USART1_TX: J6.8, J9.3, U10.42 (PA9)
GND: C1.1, C2.1, C3.1, C4.1, C5.1, C6.1, C7.2, C8.1, C9.1, C10.1, C11.1, C12.2, C13.1, C14.1, C15.1, C16.1, C17.1, C18.1, C19.1, C20.1, C21.2, C22.2, C23.1, C24.2, C25.1, C26.1, C27.1, C28.1, C29.1, C30.1, C31.2, C32.1, H1.1 (1_1), H2.1 (1_1), H3.1 (1_1), J1.1 (EH), J1.2 (EH), J1.3 (EH), J1.4 (EH), J1.A1B12 (GND), J1.B1A12 (GND), J2.1 (EH), J2.2 (EH), J2.3 (EH), J2.4 (EH), J2.A1B12 (GND), J2.B1A12 (GND), J3.1 (EH), J3.2 (EH), J3.3 (EH), J3.4 (EH), J3.A1B12 (GND), J3.B1A12 (GND), J4.1, J4.5, J4.6, J5.1, J6.1, J6.2, J6.16, J7.1, J8.1, J9.1, R9.1, R10.1, R11.1, R12.1, R13.1, R17.1, R18.1, R19.1, R20.1, R23.2, R24.2, R25.1, R26.1, SW1.5, SW1.6, SW2.2, SW2.4, SW2.5, SW2.6, TP9.1 (1_1), U1.2 (VN), U2.2 (GND), U3.2 (GND), U4.2 (NC), U4.7 (GND), U4.8 (1P6V), U4.11 (0P2V), U4.12 (0P1V), U4.17 (NC), U4.18 (NC), U4.19 (NC), U4.21 (TP), U5.2 (VN), U7.2 (GND), U7.5 (ST), U8.1 (GND), U9.2 (VN), U10.12 (VSSA), U10.31 (VSS), U10.63 (VSS), U11.6 (GND), U11.13 (EN#), U12.1 (GND), U25.1, U26.1, X1.2 (GND), X1.4 (GND); also elsewhere on the board
unnamed: C10.2, R4.1, R8.2, R9.2
unnamed: C29.2, D1.1 (K), U12.3 (VDD)
unnamed: J1.A5 (CC1), R13.2
unnamed: J1.B5 (CC2), R12.2
unnamed: J1.A7 (DN1), J1.B7 (DN2), R3.1, TP2.1 (1_1)
unnamed: J1.A6 (DP1), J1.B6 (DP2), R7.1, TP1.1 (1_1)
unnamed: J2.A5 (CC1), R18.2
unnamed: J2.B5 (CC2), R17.2
unnamed: J3.A5 (CC1), R20.2
unnamed: J3.B5 (CC2), R19.2
unnamed: J4.3, R21.2
unnamed: J4.4, R16.2
unnamed: LED1.2 (K), R23.1
unnamed: LED2.2 (K), R24.1
unnamed: R14.1, R15.2, R22.2
unnamed: R11.2, U3.5 (ILIM)
unnamed: C14.2, U4.14 (NR)
unnamed: R27.2, U10.62 (PB9)
unnamed: C22.1, C23.2, L1.1, U10.13 (VDDA)
unnamed: R27.1, U12.2 (DIN)
VBUS_B: C11.2, C12.1, J1.A4B9 (VBUS), J1.B4A9 (VBUS), R4.2, TP4.1 (1_1), U2.1 (VIN), U3.6 (OUT)
VBUS_HOST: C7.1, C8.2, J3.A4B9 (VBUS), J3.B4A9 (VBUS), TP10.1 (1_1), U3.1 (IN), U7.1 (VIN)

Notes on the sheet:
APWR LED
TagConnect Debug Header TC2030-NL
BOOT SW
QWIIC Pullup jumper
HSE Oscillator
RESET SW
DPWR LED
Keys & MUX
Port A (Device mode, to computer, USB HS)
AT32F405
Debug Port (USB FS)
If assembly is an issue, the 0201 sized TVS diodes (PESD5V0R1BSFYL) can be omitted or 0402 sized TVS diodes can be placed on the DNP C17 and C18 pads. Please select <3pF class diodes.
Port B (UART over USB-C, inter-keyboard)
Port B AP22653W6 OUT decoupling (120uF minumum for USB spec)
VDDA 3.3V Voltage Regulator — TPS7A4700
ANY-OUT programming is set by Equation 2 as the sum of the internal reference voltage (V(REF) = 1.4 V) plus the accumulated sum of the respective voltages assigned to each active pin
2.54mm Headers
VDD 3.3V Voltage Regulator — XC6206P332MR

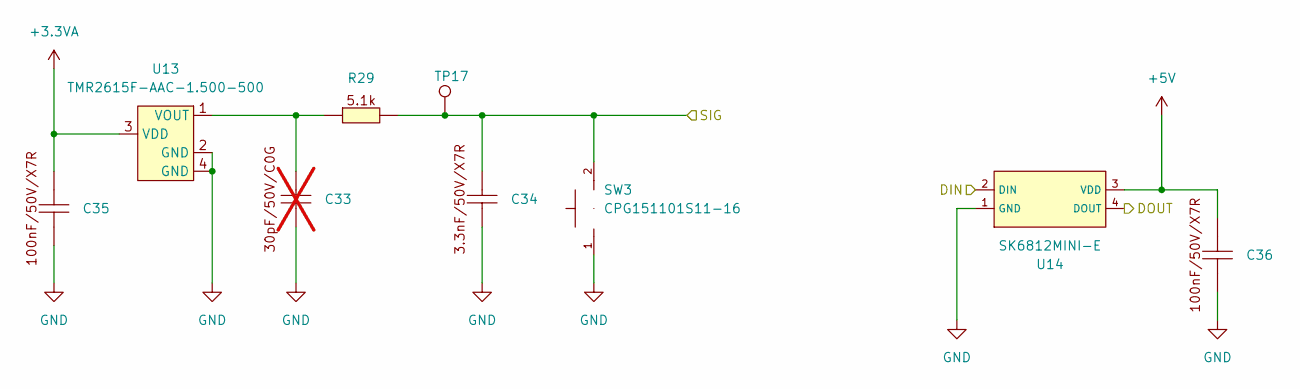
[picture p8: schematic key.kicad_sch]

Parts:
C33: 0402CG300J500NT; C_0402_1005Metric; LCSC C1570; not fitted
C34: CL10B332KB8NNNC; C_0603_1608Metric; LCSC C1613
C35, C36: CL05B104KB54PNC; C_0402_1005Metric; LCSC C307331
R29: 0402WGF5101TCE; R_0402_1005Metric; LCSC C25905
SW3: CPG151101S11-16; SMD_KEYBOARD-SW; LCSC C41430893
TP17: TestPoint; TestPoint_Pad_D1.0mm
U13: TMR2615F-AAC-1.500-500; DFN3L(1.6x1.6x0.5); MPN TMR2615F-AAC-1.500-500; LCSC C9900212297
U14: SK6812MINI-E; LED-SMD_4P-L3.2-W2.8-LS5.9_SK6812MINI-E; LCSC C5149201

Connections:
+3.3VA: C35.2, U13.3 (VDD); also elsewhere on the board
+5V: C36.2, U14.3 (VDD); also elsewhere on the board
/DIN: U14.2 (DIN); also elsewhere on the board
/Key/DOUT: U14.4 (DOUT); also elsewhere on the board
/TMUX_S1A: C34.2, R29.2, SW3.2, TP17.1 (1_1); also elsewhere on the board
GND: C33.1, C34.1, C35.1, C36.1, SW3.1, U13.2 (GND), U13.4 (GND), U14.1 (GND); also elsewhere on the board
unnamed: C33.2, R29.1, U13.1 (VOUT)

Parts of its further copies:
C37, C41, C45, C49, C53: 0402CG300J500NT; C_0402_1005Metric; LCSC C1570; not fitted
C38, C42, C46, C50, C54: CL10B332KB8NNNC; C_0603_1608Metric; LCSC C1613
C39, C40, C43, C44, C47, C48, C51, C52, C55, C56: CL05B104KB54PNC; C_0402_1005Metric; LCSC C307331
R30, R31, R32, R33, R34: 0402WGF5101TCE; R_0402_1005Metric; LCSC C25905
SW4, SW5, SW6, SW7, SW8: CPG151101S11-16; SMD_KEYBOARD-SW; LCSC C41430893
TP18, TP19, TP20, TP21, TP22: TestPoint; TestPoint_Pad_D1.0mm
U15, U17, U19, U21, U23: TMR2615F-AAC-1.500-500; DFN3L(1.6x1.6x0.5); MPN TMR2615F-AAC-1.500-500; LCSC C9900212297
U16, U18, U20, U22, U24: SK6812MINI-E; LED-SMD_4P-L3.2-W2.8-LS5.9_SK6812MINI-E; LCSC C5149201

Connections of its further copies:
+3.3VA: C39.2, C43.2, C47.2, C51.2, C55.2, U15.3 (VDD), U17.3 (VDD), U19.3 (VDD), U21.3 (VDD), U23.3 (VDD); also elsewhere on the board
+5V: C40.2, C44.2, C48.2, C52.2, C56.2, U16.3 (VDD), U18.3 (VDD), U20.3 (VDD), U22.3 (VDD), U24.3 (VDD); also elsewhere on the board
/Key1/DOUT: U16.4 (DOUT), U18.2 (DIN)
/Key2/DOUT: U18.4 (DOUT), U20.2 (DIN)
/Key3/DOUT: U20.4 (DOUT), U22.2 (DIN)
/Key4/DOUT: U22.4 (DOUT), U24.2 (DIN)
/Key5/DOUT: U24.4 (DOUT)
/Key/DOUT: U16.2 (DIN); also elsewhere on the board
/TMUX_S1B: C38.2, R30.2, SW4.2, TP18.1 (1_1); also elsewhere on the board
/TMUX_S2A: C42.2, R31.2, SW5.2, TP19.1 (1_1); also elsewhere on the board
/TMUX_S2B: C46.2, R32.2, SW6.2, TP20.1 (1_1); also elsewhere on the board
/TMUX_S3A: C50.2, R33.2, SW7.2, TP21.1 (1_1); also elsewhere on the board
/TMUX_S3B: C54.2, R34.2, SW8.2, TP22.1 (1_1); also elsewhere on the board
GND: C37.1, C38.1, C39.1, C40.1, C41.1, C42.1, C43.1, C44.1, C45.1, C46.1, C47.1, C48.1, C49.1, C50.1, C51.1, C52.1, C53.1, C54.1, C55.1, C56.1, SW4.1, SW5.1, SW6.1, SW7.1, SW8.1, U15.2 (GND), U15.4 (GND), U16.1 (GND), U17.2 (GND), U17.4 (GND), U18.1 (GND), U19.2 (GND), U19.4 (GND), U20.1 (GND), U21.2 (GND), U21.4 (GND), U22.1 (GND), U23.2 (GND), U23.4 (GND), U24.1 (GND); also elsewhere on the board
unnamed: C37.2, R30.1, U15.1 (VOUT)
unnamed: C41.2, R31.1, U17.1 (VOUT)
unnamed: C45.2, R32.1, U19.1 (VOUT)
unnamed: C49.2, R33.1, U21.1 (VOUT)
unnamed: C53.2, R34.1, U23.1 (VOUT)

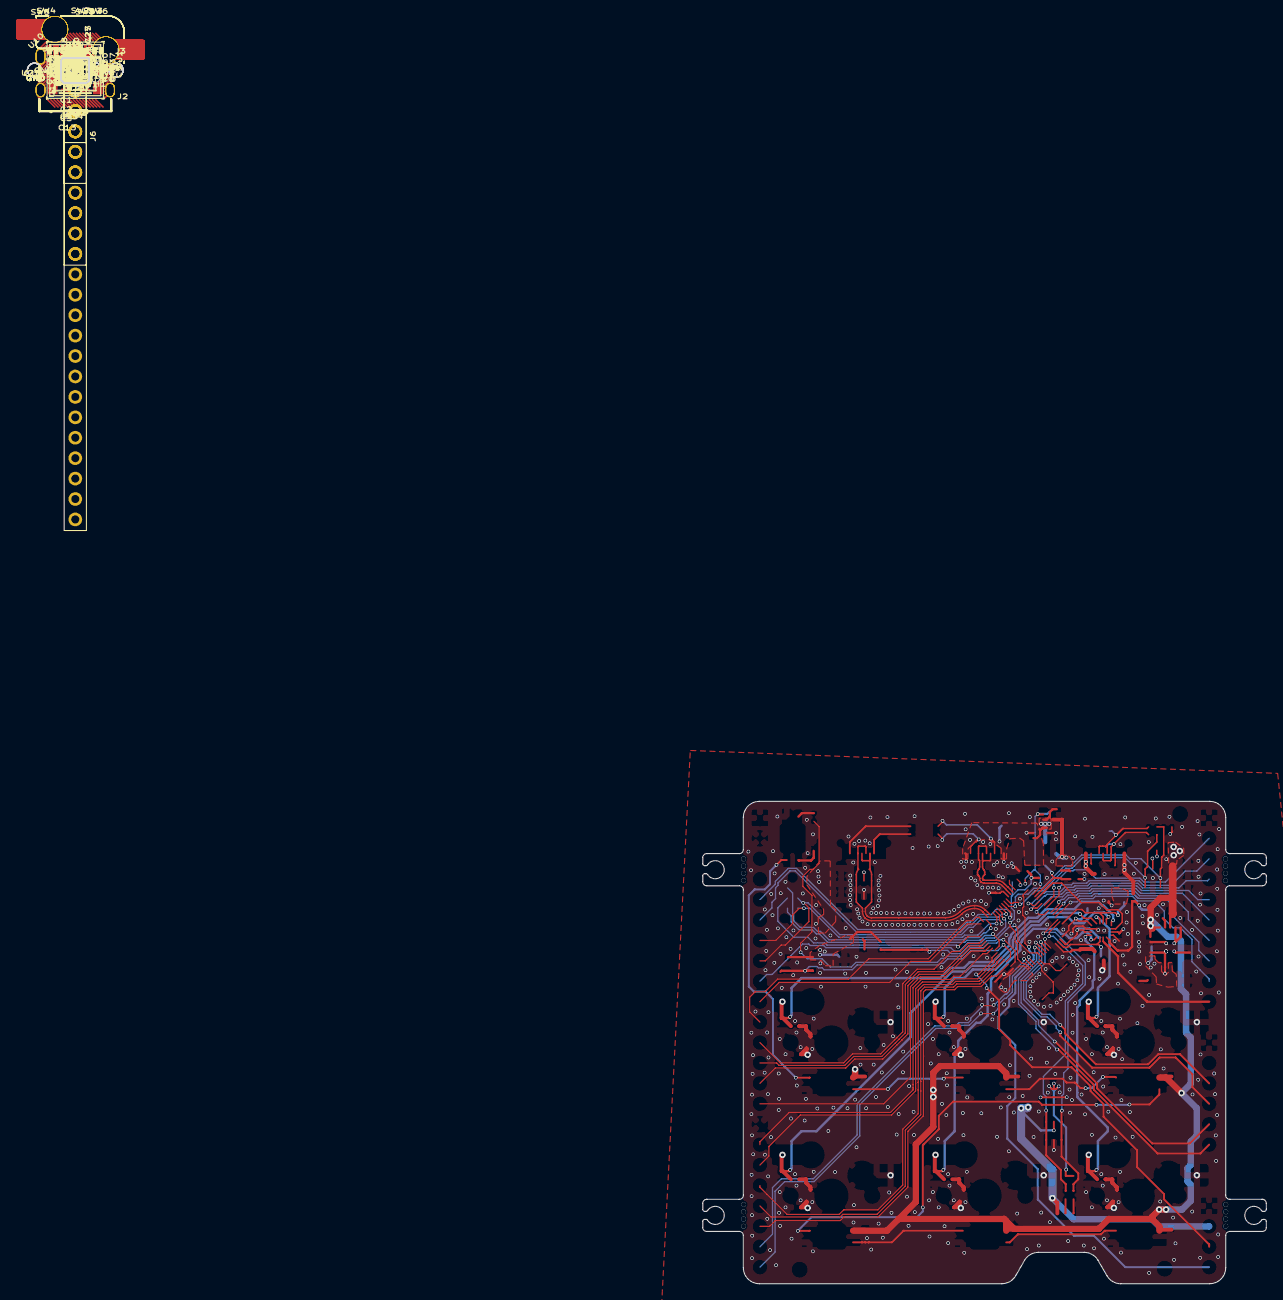
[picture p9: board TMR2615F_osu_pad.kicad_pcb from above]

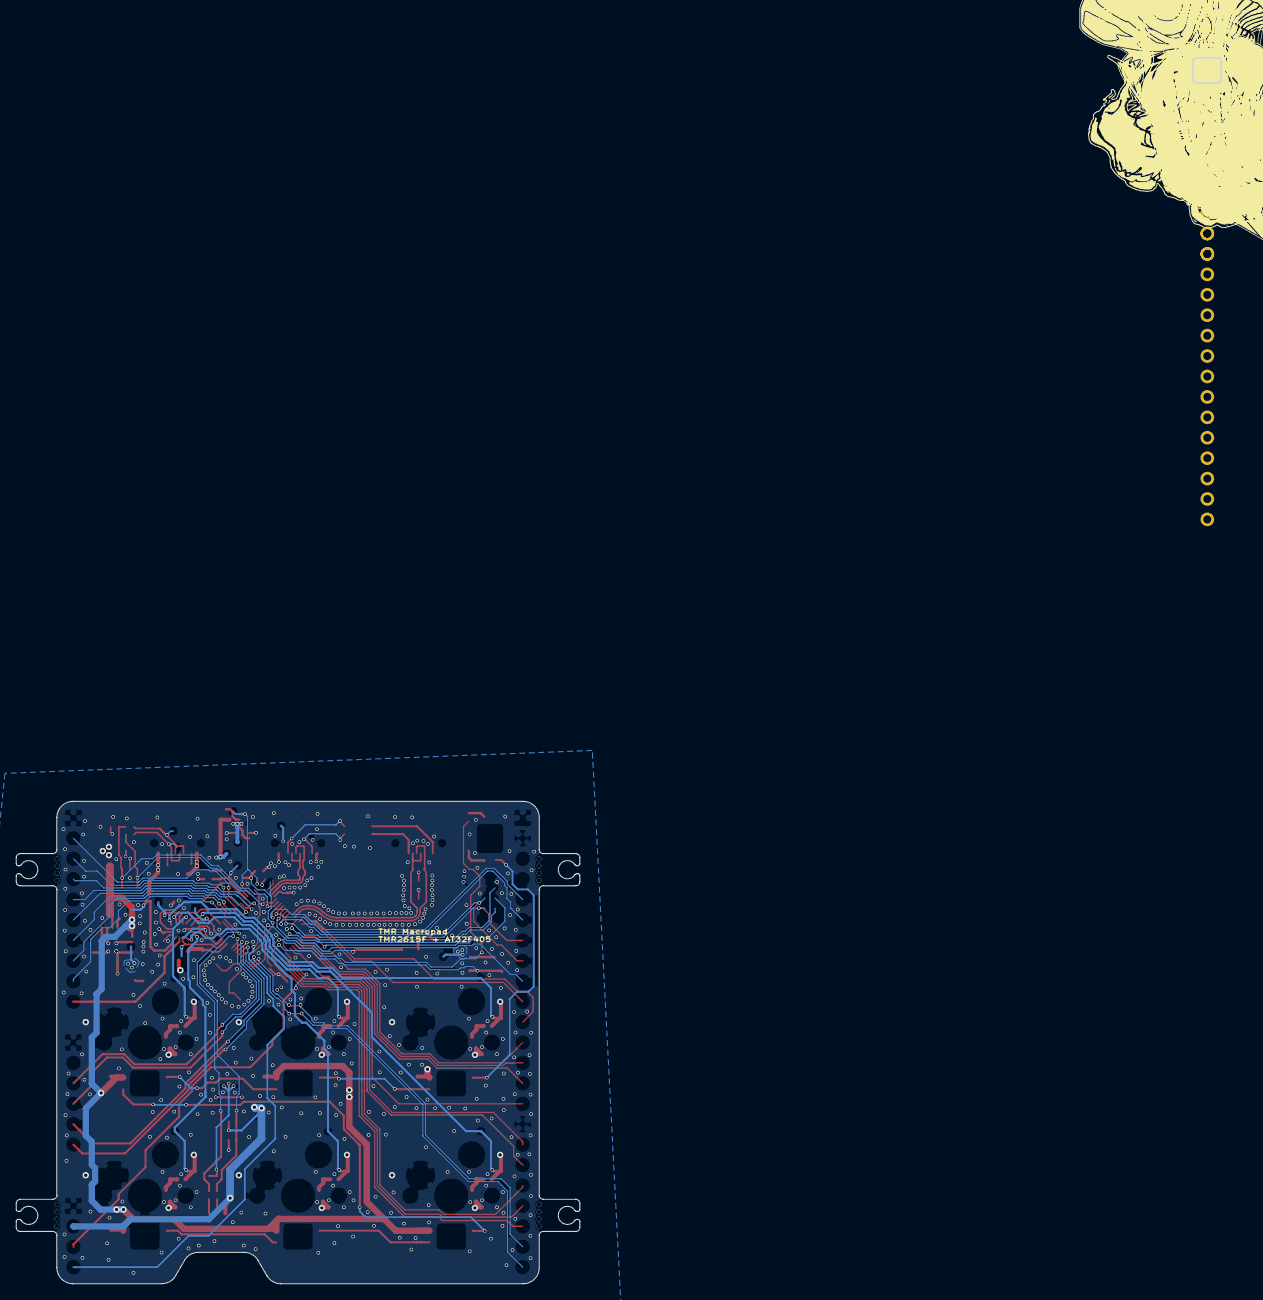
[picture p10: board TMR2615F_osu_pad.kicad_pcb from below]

Board: 4 copper layers, 3.5 x 3.1 mm, 165 parts (23 on the bottom side), 102 nets.

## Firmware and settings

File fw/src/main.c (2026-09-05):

/* SPDX-License-Identifier: Apache-2.0
 * Copyright 2026 Isaac Chiu
 */
/*
 * main.c — Giris firmware, first light.
 *
 * Today: clock to 216 MHz, run the ADC/mux scan engine at 8 kHz, and expose the
 * readings over a raw-HID interface on the USB HS port (J3) so the browser viewer
 * can plot and log them. The SK6812 chain doubles as a status indicator.
 *
 * Still no keyboard interface, deliberately — with no keyboard usages in the
 * descriptor, macOS does not demand Input Monitoring to open the device.
 *
 * See ../../hw/TMR2615F_osu_pad/firmware_architecture.md for what comes next.
 */
#include "board.h"
#include "clock.h"
#include "sk6812.h"
#include "adc.h"
#include "uid.h"
#include "reset.h"
#include "power.h"
#include "keys.h"
#include "xusb.h"
#include "link.h"
#include "peer.h"
#include "split.h"
#include "usb.h"
#include "console.h"
#include "tusb.h"

static uint32_t leds[LED_COUNT];

/* 8-bit hue -> 0x00GGRRBB, dim enough that the whole chain is safe on any port. */
static uint32_t hue(uint8_t h, uint8_t v)
{
  uint8_t r, g, b;
  const uint8_t seg = h / 43u;
  const uint8_t f   = (uint8_t)((h - (seg * 43u)) * 6u);

  switch (seg) {
    case 0:  r = 255;            g = f;              b = 0;   break;
    case 1:  r = (uint8_t)(255 - f); g = 255;        b = 0;   break;
    case 2:  r = 0;              g = 255;            b = f;   break;
    case 3:  r = 0;              g = (uint8_t)(255 - f); b = 255; break;
    case 4:  r = f;              g = 0;              b = 255; break;
    default: r = 255;            g = 0;              b = (uint8_t)(255 - f); break;
  }

  r = (uint8_t)((r * v) / 255u);
  g = (uint8_t)((g * v) / 255u);
  b = (uint8_t)((b * v) / 255u);

  return ((uint32_t)g << 16) | ((uint32_t)r << 8) | b;
}

static void scope_pin_init(void)
{
  crm_periph_clock_enable(CRM_GPIOD_PERIPH_CLOCK, TRUE);

  gpio_init_type gi;
  gpio_default_para_init(&gi);
  gi.gpio_pins           = SCOPE_PIN;
  gi.gpio_mode           = GPIO_MODE_OUTPUT;
  gi.gpio_out_type       = GPIO_OUTPUT_PUSH_PULL;
  gi.gpio_pull           = GPIO_PULL_NONE;
  gi.gpio_drive_strength = GPIO_DRIVE_STRENGTH_STRONGER;
  gpio_init(SCOPE_PORT, &gi);
}

int main(void)
{
  /* Boot on the reset-default internal oscillator so the console exists BEFORE
   * anything that can hang. The previous build initialised the PLL first and
   * spun forever waiting on HEXT — from outside that is indistinguishable from
   * a dead board. */
  /* Before anything else can reset the part, and before the DFU jump, so the
   * flags describe the reset that actually got us here. */
  reset_capture();

  usb_bootloader_check();      /* honours a pending reboot-to-DFU request */

  system_core_clock_update();
  board_delay_cycles_init();
  console_init();

  console_puts("\n\n=== Giris fw (safe boot) ===\nboot sclk ");
  console_dec(system_core_clock);
  console_puts(" Hz (HICK)\n");

  console_stage("probing HEXT - the 12 MHz crystal");
  const bool hext_ok = board_clock_try_hext();
  if (!hext_ok) {
    console_puts("!! HEXT NEVER STABILISED.\n");
    console_puts("!! USB HS cannot work: that crystal is the HS PHY's only legal reference.\n");
    console_puts("!! Check Y1, its load caps, and that OTGHS1_R has its 12k 1%.\n");
  } else {
    console_stage("HEXT stable - switching to 216 MHz PLL");
    if (board_clock_init()) {
      console_init();                 /* re-init: the baud divisor changed */
      console_puts("sclk now ");
      console_dec(system_core_clock);
      console_puts(" Hz\n");
    } else {
      console_puts("!! PLL or sysclk switch timed out; still on HICK\n");
    }
  }

  /* PC13 (AP22653 enable) is deliberately left untouched. It is Hi-Z at reset and
   * R27's 10k pulldown holds the 5 V source OFF. */

  /* Identity before anything else that talks. With two halves running one
   * image, an unlabelled log line is worthless. */
  console_stage("board identity");
  console_puts("   uid    ");
  console_puts(uid_serial());
  console_puts("\n   tag    0x");
  console_hex(uid_tag());
  {
    const uint8_t rf = reset_flags();
    console_puts("\n   reset  ");
    if (rf & RESET_POR)    console_puts("power-on/brown-out ");
    if (rf & RESET_NRST)   console_puts("NRST-pin ");
    if (rf & RESET_SW)     console_puts("software ");
    if (rf & RESET_WDT)    console_puts("watchdog ");
    if (rf & RESET_WWDT)   console_puts("window-watchdog ");
    if (rf & RESET_LOWPWR) console_puts("low-power ");
    if (rf == 0)           console_puts("(no flag set)");
  }
  console_puts("\n");

  console_stage("link pins (J1 / USART6)");
  link_init();
  {
    const uint8_t s = link_sense();
    console_puts("   PB12 /LM_ST   ");
    console_puts((s & 1u) ? "high" : "low");
    console_puts("   (U2 LM66100 ST, the VBUS_B ideal diode)\n   PB10 /AP_FAULT ");
    console_puts((s & 2u) ? "high" : "low");
    console_puts("   (AP22653 overcurrent, active low)\n");
  }

  console_stage("scope pin");
  scope_pin_init();

  console_stage("sk6812");
  sk6812_init();

  console_stage("usb (OTG_HS on J3)");
  if (hext_ok) {
    usb_init();
  } else {
    console_puts("   skipped - no crystal\n");
  }

  console_stage("adc scan engine");
  adc_scan_init();
  if (adc_calibration_failed()) console_puts("!! ADC calibration timed out\n");

  console_stage("power policy");
  power_init();

  console_stage("keyboard (output disabled until asked)");
  keys_init();

  console_stage("xusb (reporting disabled until asked)");
  xusb_init();

  console_stage("link arbitration");
  console_puts("   link protocol v");
  console_dec(PEER_PROTO);
  console_puts("  (both halves must match to reach the run phase)\n");
  peer_init();

  console_stage("running");

  /* Set the status pixels ONCE and leave them alone. The bit-bang blocks
   * interrupts for ~210 us, which is 3.4 TMR2 periods: conversions keep firing
   * while the SEL flip cannot, so the DMA ring slips a bank. Resyncing after
   * each write costs a glitched frame instead, which is no better while we are
   * measuring. The real fix is SPI + DMA (see the architecture doc); until then
   * the LEDs simply do not run during acquisition. */
  leds[0] = 0;
  for (uint32_t i = LED_FIRST_KEY_PIXEL; i < LED_COUNT; i++) leds[i] = hue((uint8_t)(i * 36u), 10);
  sk6812_write(leds, LED_COUNT);
  adc_resync();

  /* No periodic console heartbeat. It was a first-light aid and USB telemetry
   * replaced it long ago, but it survived into the run phase and cost dearly:
   * console_puts() is a blocking polled write at 115200, so a ~100-character
   * status line stops the main loop for ~9 ms. Measured against the split link
   * that was 96 lost frames per second — 1.2 % of an 8 kHz stream, and a
   * worst-case inter-arrival of 8.6 ms — from a debug print nobody was reading.
   * Everything it printed is available over USB: CMD_SNAPSHOT for the frame
   * index and slots, RSP_INFO for the phase error count. */
  for (;;) {
    usb_task();
    /* Rides in every link frame. Both halves setting it is topology (b) — the
     * dual-host case — and it is the one input topology detection needs that
     * cannot be worked out locally. */
    split_set_host(tud_mounted());
    peer_task();
    keys_task();
    power_task();

    /* Only when the host is asleep AND no peer is relying on us. In SERVING the
     * link still has a frame due every 125 us and sleeping would wreck it. */
    if (power_may_idle()) __WFI();
  }
}

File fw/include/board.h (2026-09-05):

/* SPDX-License-Identifier: Apache-2.0
 * Copyright 2026 Isaac Chiu
 */
/*
 * board.h — Giris TMR2615F_osu_pad (6-key analog dev pad) pin map.
 *
 * Every assignment here was read out of the exported netlist, not the schematic
 * source:  kicad-cli sch export netlist --format kicadsexpr
 * See ../../hw/TMR2615F_osu_pad/firmware_architecture.md §11b.
 */
#ifndef GIRIS_BOARD_H
#define GIRIS_BOARD_H

#include "at32f402_405.h"

/* ---------------------------------------------------------------- clocks */
#define BOARD_HEXT_HZ        12000000U   /* mandatory: the OTG_HS PHY's only legal reference */
#define BOARD_SCLK_HZ       216000000U

/* ------------------------------------------------------------- analog in */
/* TMUX1574 (U11) 4x SPDT.  SEL low  -> A set: sensors U13/U17/U21 + VBUS_B sense
 *                          SEL high -> B set: sensors U15/U19/U23                */
#define MUX_SEL_PORT         GPIOB
#define MUX_SEL_PIN          GPIO_PINS_2      /* PB2 */

/* Mux outputs D1..D4 land on ADC1_IN3..IN0 (note the reversed order). */
#define ADC_CH_D1            3                /* PA3 — S1A/S1B */
#define ADC_CH_D2            2                /* PA2 — S2A/S2B */
#define ADC_CH_D3            1                /* PA1 — S3A/S3B */
#define ADC_CH_D4            0                /* PA0 — S4A = VBUS_B/2, S4B = J5.10 */

/* Six TMR2615F-AAC-1.500-500 sensors, all on the +3.3VA rail (TPS7A4700, U4).
 * 1.500 mV/V/Gs, offset 500 mV/V, +-500 Gs magnetic, electrical rails at +-300 Gs.
 * => 6.144 ADC counts per Gauss, and the ratiometric output tracks VDDA exactly.
 * NOTE: the F variant's output is INVERTED — counts fall as the key travels.     */
#define SENSOR_COUNT         6

/* Per-key chain as built: VOUT -> 30 pF -> 5.1 k -> 3.3 nF -> mux.
 * Respin target is 2.2 k + 47 nF (+ 100 R in each hotswap socket branch).        */

/* Kailh hotswap sockets SW3..SW8 sit on the SAME analog node with their other
 * side on GND, so a *mechanical* switch shorts the sensor node. A reading pinned
 * near the bottom rail means "mechanical key closed", not a fault.               */

/* ------------------------------------------------------------------ leds */
/* 7-pixel SK6812MINI-E chain. Pixel 0 (U12) is the sacrificial level-shifter on
 * the 1N4148-dropped ~4.3 V rail; pixels 1..6 are the per-key LEDs on +5 V.      */
#define LED_DATA_PORT        GPIOB
#define LED_DATA_PIN         GPIO_PINS_9      /* PB9 -> R27 120R -> U12.DIN */
#define LED_COUNT            7
#define LED_FIRST_KEY_PIXEL  1

/* ------------------------------------------------------------------ link */
/* Inter-board USB-C J1 carries a UART, not USB.
 *   J1 D+ (A6/B6) -> R7 120R -> PC7   (net /UART7_TX)
 *   J1 D- (A7/B7) -> R3 120R -> PC6   (net /UART7_RX)
 * Both have 10k pull-ups (R1/R2) and SRV05-4A (U1) clamps.
 *
 * CAREFUL: the net names are inverted relative to the silicon. PC6 is natively
 * USART6_TX/UART7_TX and PC7 is natively USART6_RX/UART7_RX, so this board's
 * "default" half is the one that must set CTRL2.TRPSWAP.
 *
 * Prefer USART6 (MUX8) over UART7 (MUX9): same pins, but APB2-clocked at 216 MHz,
 * giving an exact integer ladder of 13.5 / 12 / 9 / 8 / 6 Mbaud instead of a
 * 6.75 Mbaud ceiling.  Target 9 Mbaud.                                           */
#define LINK_PORT            GPIOC
#define LINK_PIN_PC6         GPIO_PINS_6
#define LINK_PIN_PC7         GPIO_PINS_7
#define LINK_DISCOVERY_BAUD  115200U    /* open-drain phase; ~500 kbaud is the ceiling */
#define LINK_RUN_BAUD        9000000U   /* push-pull phase on USART6 */

/* ----------------------------------------------------------------- power */
/* PC13 drives the AP22653 (U3) enable, ACTIVE HIGH, and sources 5 V out J1.
 * It is Hi-Z at reset and R27's 10k pulldown holds the switch OFF.
 *
 * DO NOT DRIVE THIS PIN until link arbitration has completed and the VBUS_B
 * divider (mux S4A -> ADC1_IN0) reads cold. If a peer answers the hail, that is
 * dual-host mode and NOBODY sources VBUS.                                        */
#define PWR_SOURCE_EN_PORT   GPIOC
#define PWR_SOURCE_EN_PIN    GPIO_PINS_13     /* PC13, net /PW_PSTRH */

#define LINK_POWERED_PORT    GPIOB
#define LINK_POWERED_PIN     GPIO_PINS_12     /* PB12, net /LM_ST — high = we are the slave */

#define PWR_FAULT_PORT       GPIOB
#define PWR_FAULT_PIN        GPIO_PINS_10     /* PB10, net /AP_FAULT — AP22653 overcurrent */

#define PWR_DEBOUNCE_MS      10               /* AP22653 FAULT# has a 6 ms deglitch */

/* PB12 is also OTGHS_ID in AF 0xA and PB13 is OTGHS_VBUS — never mux PB12 to
 * AF 0xA. This design is device-only; force device mode.                         */
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

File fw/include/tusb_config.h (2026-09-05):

/* SPDX-License-Identifier: Apache-2.0
 * Copyright 2026 Isaac Chiu
 */
/* TinyUSB configuration — AT32F405 OTG_HS (rhport 1) device only. */
#ifndef _TUSB_CONFIG_H_
#define _TUSB_CONFIG_H_

#define CFG_TUSB_MCU              OPT_MCU_AT32F402_405
#define CFG_TUSB_OS               OPT_OS_NONE
#define CFG_TUSB_DEBUG            0

/* rhport 1 is OTG_HS (0x40040000, 4 KB FIFO). rhport 0 is the FS core on J2,
 * which belongs to the ROM bootloader, not to us. */
#define BOARD_TUD_RHPORT          1
#define BOARD_TUD_MAX_SPEED       OPT_MODE_HIGH_SPEED

#define CFG_TUD_ENABLED           1
#define CFG_TUH_ENABLED           0
#define CFG_TUD_MAX_SPEED         BOARD_TUD_MAX_SPEED

#define CFG_TUSB_MEM_SECTION
#define CFG_TUSB_MEM_ALIGN        __attribute__((aligned(4)))

#define CFG_TUD_ENDPOINT0_SIZE    64

/* The board does not wire PB13 as a VBUS sense, so the core must not look for
 * VBUS — see usb.c, which sets GCCFG.VBUSIG by hand. */
#define CFG_TUD_VBUS_DETECT_HW    0

#define CFG_TUD_HID               2
#define CFG_TUD_CDC               0
#define CFG_TUD_MSC               0
#define CFG_TUD_MIDI              0
#define CFG_TUD_VENDOR            1
/* The XUSB (Xbox) interface rides TinyUSB's vendor class. Without this,
 * vendord_open is absent from usbd's driver table, nothing claims interface 2,
 * and the TU_ASSERT inside SET_CONFIGURATION fails — the WHOLE device stops
 * enumerating, keyboard and raw HID included. */

/* XUSB is interrupt-only ([MS-XUSBI] Table 16). These default to 0, and with
 * them off tud_vendor_int_write() and friends do not exist, so xusb.c fails to
 * link. */
#define CFG_TUD_VENDOR_EP_INT_IN          1
#define CFG_TUD_VENDOR_EP_INT_OUT         1

/* Default 64. vendord_open asserts the descriptor's packet size fits the
 * buffer, and ours is 32 ([MS-XUSBI] Tables 48/49). */
#define CFG_TUD_VENDOR_EP_INT_IN_BUFSIZE  32
#define CFG_TUD_VENDOR_EP_INT_OUT_BUFSIZE 32

/* No bulk endpoints here. Zeroing the FIFO sizes drops the stream buffers, but
 * that un-gates a raw endpoint buffer sized from CFG_TUD_VENDOR_EPSIZE — which
 * defaults to the 512-byte high-speed bulk maximum. All three move together, or
 * we carry 1 KB of dead DMA buffer. */
#define CFG_TUD_VENDOR_EPSIZE     32
#define CFG_TUD_VENDOR_RX_BUFSIZE 0
#define CFG_TUD_VENDOR_TX_BUFSIZE 0

#define CFG_TUD_HID_EP_BUFSIZE    64

#endif

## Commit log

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2026-05-27 add Connector_Pogo__C across hw/, scaffold giris project lib-tables
    - bump hw/library submodule for new Connector_Pogo__C (YTC1P-8535-01 / C5221289)
    - register Connector_Pogo__C in TMR2615F_osu_pad lib-tables
    - scaffold hw/giris/{sym,fp}-lib-table from TMR2615F's so the giris
    KiCad project can resolve all shared library categories via
    ${KIPRJMOD}/../library and ${KIPRJMOD}/../marbastlib
    - track hw/giris/giris.kicad_{pcb,pro,sch} project stubs and
    import_parts.csv manifest (with .gitignore exception)
    - ignore VS Code .history/ extension dirs
    [giris.kicad_pcb, giris.kicad_sch, import_parts.csv]
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2026-08-01 Add fab-export skill for NextPCB/JLCPCB manufacturing packages
    One dependency-free script drives the 10.99 fork's kicad-cli to produce a
    self-contained, upload-ready folder per vendor: flat gerber+drill zip, BOM,
    CPL, drill maps, board stats, DRC report, and a README order sheet.
    Encodes the things that are easy to get wrong:
    - Layer list read from the board's own (layers) block, stackup-ordered, so
    any copper count works unchanged.
    - Gerbers and drill both on absolute origin, so they cannot disagree.
    - Empty layers (e.g. B.Paste with no bottom paste) are pruned. KiCad plots
    them happily but NextPCB reports a generic "file parsing failed" on them.
    - BOM reference ranges disabled; both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
2026-08-01 Add NextPCB/JLCPCB fab packages for TMR2615F_osu_pad
    Generated by .claude/skills/fab-export. 70.1 x 60.0 mm, 4 layers, 1.617 mm
    finished, min track 0.160 mm / clearance 0.160 mm / drill 0.300 mm.
    32 BOM line items (143 parts), 150 placements. Archived as the as-sent
    record; regenerate rather than hand-edit.
    Not yet clean for order: DRC reports 97 error-severity violations
    (30 copper_edge_clearance, 28 hole_clearance, 24 malformed_courtyard,
    8 starved_thermal, 7 courtyards_overlap) -- see docs/drc.rpt. U2/U7 and U4
    carry MPNs but no LCSC code, and TP1-TP22 have neither.
    [BOM-TMR2615F_osu_pad-jlcpcb.csv, BOM-TMR2615F_osu_pad-nextpcb.csv, BOM-TMR2615F_osu_pad-nextpcb.xlsx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]
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2026-08-01 Name the TMR sensor by its full part number
    U13/U15/U17/U19/U21/U23 carried Value "TMR2615x" and MPN "TMR2615F-AAC",
    neither of which is orderable. Both now read TMR2615F-AAC-1.500-500, the
    designation used in hw/TMR2615F_osu_pad/magnetics.
    Value is set on the cached lib_symbols default and the placed symbol; there
    are no per-instance overrides, so all six sensors follow.
    Library identity is deliberately untouched -- lib_id, Symbol Name and the
    unit names stay "TMR2615x" so the symbol still resolves against
    hw/library/symbols/Sensor_Motion__C.kicad_symdir, which is a shared
    submodule. Renaming it there is a separate change.
    [key.kicad_sch]
2026-08-01 Regenerate fab packages for the sensor rename
    BOM Comment/MPN now read TMR2615F-AAC-1.500-500 for U13-U23. Gerber and
    drill diffs are plot-timestamp churn only; no copper changed. The
    .kicad_pro hunk is kicad-cli bumping tuning_profiles.meta.version 0 -> 1.
    DRC unchanged at 97 error-severity violations -- still not order-ready.
    [BOM-TMR2615F_osu_pad-jlcpcb.csv, BOM-TMR2615F_osu_pad-nextpcb.csv, BOM-TMR2615F_osu_pad-nextpcb.xlsx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]
2026-08-01 Correct fab-export troubleshooting guidance
    The NextPCB "file parsing failed" that prompted the Protel/merged-drill/
    no-gbrjob profile was a transient website glitch -- the same package
    uploaded fine after a page reload, unchanged. The message is their
    auto-quote parameter extraction, not a rejection; orders proceed by
    entering board specs manually.
    Reload-and-retry is now step 0 of the ladder, ahead of any export change,
    and the profile comments no longer claim the KiCad-native set fails on
    NextPCB. It was never shown to. The profile stays because it is verified
    working, not because it is required.
    Also records two things worth knowing if a portal ever does hard-fail:
    outline-as-.GKO, and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
2026-08-27 Stop tracking Finder metadata and tool logs
    Two .DS_Store files had been committed by accident and kept showing up as
    working-tree noise. Untrack them and ignore the pattern.
    *.err is added alongside: those files are stderr captures from the
    kicad-happy analyzers and the fab exporter, regenerated on every run.
    The three .err files already tracked under hw/TMR2615F_osu_pad/ are left
    in place — the new rule only stops fresh ones appearing.
2026-08-27 Add XC6206 and TMR2615x reference datasheets
    The XC6206P332MR PDF is the part LCSC actually ships against C5446 (HXY
    MOSFET, not Torex) — it is what the SOT-23 pin assignment was checked
    against when the symbol pinout turned out to be reversed.
    tmr2615.txt is a pdftotext dump of the MDT TMR2615x datasheet, matching
    the other .txt dumps already in this directory: the tables (CL max 10 nF,
    RL min 10 kohm, BW 30 kHz) are greppable this way, the PDF is not.
2026-08-27 Record the 2026-08-03 pre-fab design review
    Full schematic + PCB + gerber/BOM/CPL pass over TMR2615F_osu_pad before
    ordering, with every IC checked against the datasheets in hw/refs/.
    Verdict was DO NOT FAB, on three findings:
    1. U8 XC6206P332MR VIN/VOUT swapped in the symbol — the +3.3V net would
    have sat at ~4.4 V through the pass-FET body diode, over the
    AT32F405's 4.0 V absolute maximum.
    2. I2C1 SDA/SCL swapped on PF4/PF5, so hardware I2C1 on J4 was dead as
    wired (the pins cannot be remapped internally).
    3. SRV05-4A (U6) doubled channels onto the USB HS pair — ~6 pF/line
    against a ~1-2 pF budget at 480 Mbps.
    Plus should-fix items (BOOT0 pull-down above th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
2026-08-27 Clear the pre-fab blockers on TMR2615F_osu_pad
    All three blockers from prefab_review_2026-08-03.md, plus the should-fix
    resistor and a filter retune, in schematic and layout.
    U8 XC6206P332MR pinout corrected to the SOT-23 assignment in the LCSC
    datasheet — 1=VSS, 2=VOUT, 3=VIN. Pad 2 now carries +3.3V and pad 3 +5V;
    before this the +3.3V rail would have come up at ~4.4 V through the pass
    device's body diode, past the AT32F405's 4.0 V absolute maximum.
    I2C1 SDA and SCL swapped at the MCU so PF4=SDA and PF5=SCL, matching
    AT32F405 datasheet Table 9. These pins have no internal remap, so J4's
    accessory port had no working hardware I2C before.
    U6 (SRV05-4A, SOT-23-6, 3-5 pF per channel and d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
    [TMR2615F_osu_pad.kicad_pcb, TMR2615F_osu_pad.kicad_sch, key.kicad_sch]
2026-08-27 Regenerate fab packages for the pre-fab fixes
    Both packages re-exported at 2026-08-04 04:05 from the corrected board.
    Deltas that carry through to the portals: 32 -> 34 BOM lines and
    150 -> 151 placements (U6 out, U25/U26 in), only TP1 now missing an LCSC
    code where U2, U4 and TP1 were before, 644 -> 636 through vias, and 97 ->
    96 error-severity DRC violations with 0 unconnected. Board outline,
    stackup and layer set are unchanged.
    [BOM-TMR2615F_osu_pad-jlcpcb.csv, BOM-TMR2615F_osu_pad-nextpcb.csv, BOM-TMR2615F_osu_pad-nextpcb.xlsx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]
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2026-08-27 Model the SC4011 as a second-source sensor
    Companion to magnetics/tmr-magnet-model.html: same validated
    cylinder-magnet model, recomputed on the axial field component, because
    the Semiment SC4011 is a planar Hall part reading Bz where the TMR2615F
    reads Bx in the board plane. The sensor site does not move — only which
    component it sees.
    Conclusion is that it fits the board electrically (3.3 V rail, output
    window inside the mux rails, ratiometric with VDDA preserved, loading
    fine) but costs about 7x the signal: 112 mV of swing against the TMR's
    767 mV, half from the axis change and half from the lower sensitivity.
    The datasheet specifies no output noise and no temperature drift, which
    is t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
2026-08-27 Draw the 32-key giris schematic
    Scales the six-key osu pad up to one half of the split keyboard. The
    sheet was an empty A4 stub; it is now an A2 root with 32 hierarchical
    instances of a new key.kicad_sch.
    Per key, unchanged from the pad as corrected: TMR2615x sensor on +3.3VA,
    30 pF at the source into 5.1 k and 3.3 nF at the mux, a Kailh
    CPG151101S11-16 hotswap socket across the analog node, an SK6812MINI-E
    in the chain, and 2 x 100 nF.
    Top level: AT32F405RBT7-7, four TMUX1574RSVR muxes taking 32 sensors down
    to ADC1_IN0-IN15 on one shared SEL line, three USB-C ports, the LM66100 /
    AP22653 power path and XC6206 + TPS7A4700 rails carried over from the
    pad, 12 MHz crystal, two buttons, three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
    [giris.kicad_sch, key.kicad_sch]
2026-08-27 Bring up USB HS telemetry and the 8 kHz analog scan engine
    Enumerates on J3 as a USB high-speed raw-HID device (verified: 480 Mb/s,
    bInterval=1 on both interrupt endpoints) and streams all six TMR2615F
    readings to a host.
    ADC1 converts PA3/PA2/PA1/PA0 on every TMR2 TRGO at 16 kHz; DMA1_CH1 rings
    eight slots; the half- and full-transfer interrupts flip the TMUX1574 SEL
    line, so full A+B frames land at 8 kHz. Flipping the instant the four
    conversions finish leaves the mux the whole remainder of the period to
    settle, ~55 us against a 350 ns tTRAN.
    Three things that are easy to get wrong and cost real time here:
    - GCCFG.VBUSIG must be set by hand. PB13 is not wired as a VBUS sense on
    this b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
    [adc.c, console.c, main.c]
2026-08-27 Add the browser scope and host-side checks
    tools/viewer is a self-contained WebHID page served from localhost (which
    counts as a secure context, so there is no TLS and no build step). Live
    traces for all six keys, readouts in counts and Gauss, CSV recording,
    a raw-slot debug table, and a burst capture with an in-page FFT.
    That FFT is the point: a flat spectrum means the sensor noise is white and
    narrowing the analog filter is worth its transport delay; a -1/2 amplitude
    slope means 1/f and narrowing buys ~5% for nothing. That single measurement
    decides the 2.2k + 47nF filter respin, which is otherwise an argument
    between datasheet readings.
    tools/usb-check.py reads descriptors without claim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
    [at32f405.cfg]
2026-08-27 Document the telemetry firmware and the browser scope
    Records what the board itself told us: the ROM DFU descriptor advertises
    128 x 1 KB sectors, confirming this is the xB part. Artery's own
    AT32F405xB_FLASH.ld declares 256 KB — a BSP bug our linker script corrects.
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2026-08-28 Quantify the ADC charge sharing and stop the phase slip
    The scan engine had two artefacts left in it, and both are now measured rather
    than argued about.
    Charge redistribution: every conversion is pulled toward its predecessor's
    voltage. tools/seqtest.py permutes the ADC sequence over raw-HID and watches a
    channel's reading move as a function of what ran before it. The coupling is
    0.490%, which puts the sampling node at 16.3 pF. Earlier numbers in this repo
    were wrong in both directions — 0.84% taken uncritically from an audit, then
    "no measurable crosstalk" from a null on plate-contaminated data.
    The VBUS divider was the loudest neighbour, so the sequence now runs a fifth
    dummy conversi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
    [adc.c, capture.py, seqtest.py]
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2026-08-28 Add TX/RX roles and a DC continuity test across J1
    With the two boards cabled J1 to J1, nothing received in any of the four USART
    modes, at either baud, in either direction, with no error flag raised. Three
    things had to be separated: my receiver code, the peripheral, and the cable.
    link_hold() plus the two new pad bits in link_sense() settle it without
    involving the USART at all. One board holds a link pad low open-drain; the other
    reads its own pad. That is a DC continuity test through the cable.
    Result, both wires, both directions: NO CONNECTION. Each board pulls its own pad
    to 0 and the peer sees an undisturbed 1. The cable carries VBUS and GND — J1
    reads 5.1 V on the VBUS_B divider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
    [link.c, link.py, usb.c]
2026-08-28 Bring the J1 link up: clean to 13.5 Mbaud both ways
    Two boards, straight-through USB-C on J1. Full duplex push-pull with TRPSWAP on
    one half is clean at every rung to 13.5 Mbaud, the USART's hard ceiling, in both
    directions. Soaks of 163,840 bytes at 9 Mbaud and at 13.5 Mbaud: zero corrupt,
    zero missing, no error flag. The 9 Mbaud design target has comfortable margin.
    The open-drain discovery bus lands exactly where the architecture doc predicted:
    clean at 115200 and at 500 kbaud, and at 1 Mbaud every byte arrives with 1020 of
    1024 corrupt and FERR set. That is 10k into ~70pF, a genuine wire limit. 115200
    has 4x margin.
    Two traps cost the afternoon, and both are now baked into the tooling.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
    [link.c, link.py, usb.c]
2026-08-28 Move link TX to DMA and measure the sustained rate
    A polled write loop cannot keep TDR fed at 13.5 Mbaud, where a byte leaves every
    160 core cycles, so it measures the loop rather than the link. With DMA on both
    ends the link sustains 98.8-99.6% of line rate at every rung: the wire is
    saturated, not the CPU.
    That makes the 8 kHz question answerable with a number instead of arithmetic. A
    72-byte frame — 32 keys x u16 position, header, 32-bit mech bitmap, CRC-16 —
    costs 54.0 us at 13.5 Mbaud, 43.2% of a 125 us microframe. At 9 Mbaud it is
    80.7 us, 64.5%. Full duplex, so the return path is concurrent and free.
    Higher is not on the table: RM 12.6.1 requires DIV >= 16 with fixed 16x
    oversam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
    [link.c, usb.c]
2026-08-28 Measure the link over 3 m: 12 Mbaud is the ceiling
    The earlier numbers were taken over a 1.5 m cable, not the "short bench cable"
    the last commit claimed. Repeated over 3 m — about three times any split cable
    that would ship — with 409,600 bytes per rate, 100 runs of 4096 alternating
    direction:
    9 Mbaud 0 corrupt, 0 missing, 0/100 runs raised NERR
    12 Mbaud 0 corrupt, 0 missing, 0/100 runs raised NERR
    13.5 Mbaud 61/100 runs raised NERR, one run desynced and lost 4093 B
    NERR is the receiver's 16x oversampler majority-voting samples 8/9/10 of a bit
    and finding them in disagreement. At 13.5 Mbaud over 3 m it fires on most runs
    while still recovering every byte correctly, so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
2026-08-28 Declare USB 2.00, not 2.10 — we have no BOS descriptor
    The device descriptor claimed bcdUSB 0x0210 "so a BOS descriptor is legal
    later", but a device claiming 2.01 or higher is obliged to answer
    GET_DESCRIPTOR(BOS), and TinyUSB's tud_descriptor_bos_cb is a weak stub
    returning NULL — usbd.c:1344 does TU_VERIFY(desc_bos != 0), so the request is
    STALLED. macOS never asks. Windows asks every device that claims >= 2.01.
    Found while the second board failed to start on Windows 11 with
    CM_PROB_FAILED_START. What Windows had managed to read is the interesting part:
    HardwareIds = USB\VID_1209&PID_0001&REV_0100 device descriptor OK
    CompatibleIds = USB\Class_03&SubClass_00&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
2026-08-28 Confirm 8 kHz on Windows, and add the tool that measures it
    The bcdUSB 0x0200 fix resolved the Windows failure outright: same hub, same
    port, status OK, problem 0, iProduct now read, and the UID serial appearing in
    the Windows instance ID. Two other candidate causes were eliminated first and
    both were wrong — the J1 ground bond (removing the cable changed nothing) and
    the hub (its other devices were healthy throughout). The general lesson: macOS
    is not a sufficient test of a USB descriptor set, because it never asks for BOS.
    ratetest.py answers the open question from section 2 by counting polls rather
    than reading descriptor fields. It works because the streaming path emits
    exactly one fr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
    [ratetest.py]
2026-08-28 Stop telemetry when the host goes away
    usb.c had no tud_mount_cb, tud_umount_cb or tud_suspend_cb, so stream_on
    survived a disconnect, a re-enumeration and the host closing its handle. An
    aborted capture therefore left the device blasting 64-byte reports at 8 kHz
    forever with nobody reading.
    On macOS that is merely untidy. On Windows it is a trap that closes behind you:
    the HID class driver's input ring overflows, ReadFile fails, Windows resets the
    port, the device re-enumerates straight back into the same flood, and the next
    open walks into it again. It cost an afternoon looking like a flaky hub, a
    ground-bond problem and a bad cable in turn. Observed as a board that "randomly"
    dropped off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
    [ratetest.py, usb.c]
2026-08-28 Always answer a snapshot, and count seqlock read failures
    send_snapshot() returned silently when adc_read_frame() failed, so a stopped
    scan engine looked identical to a device that had stopped answering commands.
    The host then sat out its whole timeout with nothing to go on. That silence cost
    real diagnosis time today: CMD_INFO answered and CMD_SNAPSHOT did not, and there
    was no way to tell a wedged HID pipe from a dead ADC.
    A snapshot is now always sent. When the frame read fails the slots are zeroed and
    three new fields say why:
    [56] flags, bit0 = frame read failed
    [57..60] adc_read_failures
    [61] low byte of the raw seqlock counter — ODD means the writer stopped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
    [adc.c, ratetest.py, usb.c]
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2026-08-28 Frame the link: 8 kHz both ways, 2.88 M frames, zero errors
    split.c is the run-phase data plane — what actually crosses J1 once peer.c has
    both halves at 12 Mbaud. 48-byte fixed frames, sent unconditionally in both
    directions on each half's own 8 kHz ADC tick, into the existing circular DMA
    ring. 40 us of wire time in a 125 us period, so the link is idle 68 % of the
    time and the two independent scan domains can drift a long way before anything
    overlaps.
    Three deviations from the plan in the architecture doc, each decided by the
    hardware rather than the design:
    CRC-32, not CRC-16. The CRC unit does have a programmable polynomial, so
    CRC-16/CCITT was available — but it consumes a word pe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
    [adc.c, main.c, split.c]
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2026-08-28 Name the version mismatch, and fix the deadlock it uncovered
    A mixed-firmware pair used to present as a bare liveness drop that named
    nothing. peer_frame_t now carries a link protocol version — deliberately not
    the firmware build version, or every routine bump would split the keyboard in
    half — and a mismatch parks both halves in PEER_INCOMPAT.
    A mismatch does NOT stop the halves talking. Refusing to pair would remove the
    only channel that can repair it: in topology (a) the far half has no host, so
    its next image arrives over this very link. They stay on the 115200 discovery
    bus, keep hailing, and never step up to the run phase. That freezes the first
    eight bytes of peer_frame_t across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
    [main.c, split.py]
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2026-08-29 Report why the MCU last reset
    A board that keeps vanishing off a USB hub is ambiguous from the host side: a
    re-enumeration, a port reset and a dead board look alike, and the frame counter
    only says THAT it restarted, never why. CRM_CTRLSTS knows.
    The distinction that matters is power-on reset versus anything else. A POR means
    VBUS or the 3.3 V rail actually went away — a hub cut the port, or the rail
    browned out — which no firmware could have prevented. Any other flag points back
    at us.
    The flags are sticky (RM 4.3.21: cleared by a power reset or by writing RSTFC),
    so reset_capture() reads them first thing in main() and clears them. Without the
    clear, every later boot reports the reaso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
    [main.c, split.py, usb.c]
2026-08-29 Fix a link TX race that only appears under combined load
    tx_done() declared a frame sent on USART_TDC_FLAG alone. TDC says only that the
    shift register drained — and it drains just the same in the gap left when a
    starved DMA fails to deliver the next byte in time. On TDC alone, tx_done()
    reports "sent" while the DMA still has bytes to fetch, the main loop rebuilds
    the frame buffer underneath it, and the tail of one frame goes out as the head
    of the next. The receiver sees a bad CRC and then slides a byte at a time
    hunting for the sync it just lost.
    It takes real bus contention to open that gap, so it cannot appear in any test
    that loads one subsystem at a time. 300 s with one half running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
    [loadtest.py]
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2026-08-29 Add the keyboard interface, which is what earns wake capability
    Wake turned out not to be negotiable. Windows exposed no
    MSPower_DeviceWakeEnable for a vendor-defined HID, powercfg refused to arm it
    under either friendly name, and the host therefore never sent
    SET_FEATURE(DEVICE_REMOTE_WAKEUP) — measured while genuinely suspended as 65
    detected presses against 0 grants. Counting attempts and grants separately is
    what made that readable as "the host refused" rather than "the press was
    missed".
    A HID System Control collection was the tempting middle road — "System Wake Up"
    is the usage the spec defines for it, and it carries no keyboard usages, which
    is what makes macOS demand Input Monit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
    [capture.py, dfu.py, keys.c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]
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2026-09-05 License the project: Apache-2.0 for software, CERN-OHL-P v2 for hardware
    The repo had no LICENSE at all, which means all rights reserved by default —
    being public on GitHub is not a grant. Nobody could legally fork it, build it,
    or send a patch.
    Two licences because this is two kinds of work. Apache-2.0 covers the firmware,
    host tools, web configurator and docs; it is permissive and adds an express
    patent grant. hw/ gets CERN-OHL-P v2, because software licences are written
    about copying source rather than about manufacturing physical objects, and
    because it is what marbastlib already uses, so nothing in the tree needs a
    compatibility analysis.
    Corrections this turned up:
    - The Artery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
    [adc.c, board.h, capture.py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]
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2026-09-05 Use the requested PID 0x6415 rather than pid.codes' barred test PID
    0x0001 is pid.codes' private-testing PID and carries an explicit prohibition:
    "MUST NOT be used on any device that will be redistributed, sold, or
    manufactured". Staying on it means the rule is broken the moment a board leaves
    the bench, and it makes every host tool and every capture ambiguous with every
    other project doing the same thing.
    0x6415 is requested but not yet allocated (pid.codes PR #1271). Using it breaks
    no rule — it is a claim staked early, and staked in the open: the PR names the
    number, this repo is public and linked from it, and anyone who hits a collision
    can see exactly who is using it and why. That is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
    [capture.py, dfu.py, link.py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]
2026-09-05 Add the XUSB interface, so analog travel can reach XInput
    No HID report descriptor can ever make a device visible to XInput. Windows'
    inbox xusb22.sys binds by COMPATIBLE ID, and the shipped INF matches exactly
    five — MS_COMP_XUSB10, MS_COMP_XUSB20 and three Microsoft VID/PID pairs. There
    is no class/subclass/protocol rule in it at all. So the vendor interface of
    0xFF/0x5D/0x01 is necessary and nowhere near sufficient: the compatible ID has
    to be delivered as well, through the MS OS 1.0 chain. That is the whole trick,
    and it is what lets a keyboard on our own VID present itself to XInput with no
    driver for anyone to install.
    Written from Microsoft's [MS-XUSBI] specification, whose Open Sp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
    [main.c, tusb_config.h, usb.c]
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2026-09-29 Hotswap switch symbol no longer draws two giant arcs; schematic PDFs show a repeated sheet once
    The CPG151101S11-16 symbol carried two arcs whose start, mid and end sat
    within 2.5 um in a line, which plot as circles of enormous radius. They
    are gone. hw/tools/sch_pdf.py keeps the first page of each repeated
    sheet, notes it, and appends each instance's designators.
    [key.kicad_sch]
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
